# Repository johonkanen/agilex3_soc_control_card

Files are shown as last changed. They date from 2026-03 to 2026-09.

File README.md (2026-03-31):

# agilex3_soc_control_card
agilex 3 soc platform based control card for ac in/out lab power supply
Original board used Agilex 3 FPGA and had a few bugs in pin connections so this is second revision with SoC instead of just FPGA

target is to create a Linux capable Control Board with ethernet connection using A3CW100BM16AE6S SoC
Alternatively I could use Agilex 5 A5E(E/B)008B23BE6SCS

Main features :
Agilex 5 SoC (A5EB008B23BE6SCS)
1Gb ethernet
microSD
(1GB? 2GB? 4GB?) LPDDR4
muxed adc block

Controls power electronics so mostly does generic io for pwm and spi/sdm adc

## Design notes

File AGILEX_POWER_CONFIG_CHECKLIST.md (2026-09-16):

# Agilex 5 (A5EB013B-B23B, -6S) power, configuration and power-up checklist

Generated from the schematic as of 2026-09-16 (root sheet, `fpga_power`, `fpga_gnd`, `sdm`, `ps`, `ps1`, `clk`, `hps`). Reference: Altera *Agilex 5 Power Management User Guide* (ID 813161, section 3.2 Power-Up Sequence Requirements, table 3) and the *Agilex 5 Pin Connection Guidelines* (ID 813266).

Legend: `[x]` verified correct in the schematic, `[ ]` open item / needs your decision, `[!]` error to fix.

---

## 1. Supply rails on the board

| Rail (net) | Source | Nominal | Enable | Loads |
|---|---|---|---|---|
| `5V0` / `5V` | J6 (2x3 header), also J4.3 | 5.0 V in | – | all regulators, U6 |
| `VCORE` | U15 TDA38812XUMA1 buck, remote sense via `vcoresense_P/N` (VCCLSENSE BN46 / GNDSENSE BN44), FB divider R2 10k / R1 39k -> 0.6 V x (1 + 10/39) = **0.754 V** | 0.75 V | EN tied to 5V0 -> starts as soon as 5 V is present | all Group 1 pins (see §2) |
| `1V8` | U18 AP61202Z6 buck, R82 10k / (R80 ‖ R81 = 5k) -> 1.80 V | 1.8 V | EN = `PG-Core` (U15 PGOOD, open-drain, R58 5.6k to 5V0) | Group 2A pins, VCCIO_HVIO_6A, Y2 (SiT8924 1.8 V), QSPI flash U2, all SDM/JTAG pull-ups, U1/U42 B-side, PHY 1.8 V |
| `3V3` / `3v3` | U8 AP61202Z6, R85 10k / R83 2k2 -> 3.33 V | 3.3 V | EN = U18 PG (open-drain, R65 47k to 5V) | VCCIO_HVIO_6B..6H, U9 100 MHz LVDS osc, U1/U42 A-side, headers |
| `1V2` | U19 AP61202Z6, R88 10k / R86 10k -> 1.20 V | 1.2 V | EN = U18 PG | VCCRCORE, VCCIO_PIO_SDM, VCCIO_PIO_2A_T/B |
| `1V1` | U16 AP61202Z6, R91 10k / R89 12k -> 1.10 V | 1.1 V | EN = U18 PG | VCCIO_PIO_3A_T/B (LPDDR4), refclk bias divider |
| `3V3_analog` | U6 NCP163 LDO from 5V0 | 3.3 V intended | EN tied to 5V0 | ADC subsystem |

- [x] VCORE set point 0.754 V matches the -6S core voltage; remote sense goes to the device sense pins.
- [x] All AP61202 feedback dividers give the intended voltages (R84/R87/R90 are DNP).
- [x] U6 is `NCP163ASN330T1G` (3.3 V fixed) — was wrongly the 1.5 V `...150T1G` variant.
- [x] U19 / U8 / U16 `PG` pins (open drain) are wired-AND on `pg_all` with R249 10 k to 1V8 -> hierarchical `PG` -> root `pg_1v8` -> U42 channel 4 (1.8 V -> 3.3 V) -> `powergood` (SODIMM P1 pin 12, push-pull 3.3 V) and `pg_led` -> R16 -> D1. High only when 1V2, 3V3 and 1V1 are all in regulation (which implies VCORE and 1V8 are up).

## 2. Voltage per Agilex 5 supply pin group (from `fpga_power.kicad_sch`)

Rail groups are from table 3 of the Power Management UG. All pins of each group were checked; the count is the number of balls.

### Group 1 – core, must ramp first (all on `VCORE`, 0.75 V)

| Pin name | Balls | Net | |
|---|---|---|---|
| VCC | 21 | VCORE | [x] |
| VCCP | 7 | VCORE | [x] |
| VCCL_SDM | 4 | VCORE | [x] |
| VCCH_SDM | 1 (CD54) | VCORE | [x] (PCG: connect to VCCL_SDM when there are no transceivers) |
| VCC_IO_SDM | 1 (CT54) | VCORE | [x] sense pin, follows VCC |
| VCCL_ADC_SDM | 1 (CW52) | VCORE | [x] |
| VCCPLLDIG_SDM | 1 (CL49) | VCORE | [x] |
| VCCL_HPS | 4 | VCORE | [x] |
| VCCL_HPS_CORE0_CORE1 | 2 (AG46, AL46) | VCORE | [x] |
| VCCL_HPS_CORE2/3 | 4 (AL52, AL54, AR57, AW57) | VCORE | [x] (013B quad-core; on 008B these balls are GND) |
| VCCPLLDIG1_HPS / VCCPLLDIG2_HPS | 2 (BB54, BB52) | VCORE | [x] |
| VCC_HSSI_L | 2 (BJ54, BN54) | VCORE | [x] |
| VCCLSENSE / GNDSENSE | BN46 / BN44 | vcoresense_P / vcoresense_N | [x] Kelvin sense to U15 FB / RGND |

### Group 2A – 1.8 V, after Group 1 reaches 90 % (all on `1V8`)

| Pin name | Balls | Net | |
|---|---|---|---|
| VCCPT | 4 | 1V8 | [x] |
| VCCPT_HVIO | 10 | 1V8 | [x] |
| VCCIO_SDM | 1 (CW49) | 1V8 | [x] sets SDM I/O, JTAG, OSC_CLK_1 level = 1.8 V |
| VCCFUSEWR_SDM | 1 (CD52) | 1V8 | [x] |
| VCCPLL_SDM | 1 (CL46) | 1V8 | [x] |
| VCCADC | 1 (CG52) | 1V8 | [x] |
| VCCIO_HPS | 2 | 1V8 | [x] HPS I/O are 1.8 V only |
| VCCPLL1_HPS / VCCPLL2_HPS | 2 (BF57, BF52) | 1V8 | [x] |

### Group 2B – I/O, after Group 2A reaches 90 %

| Pin name | Balls | Net | |
|---|---|---|---|
| VCCRCORE | 3 | 1V2 | [x] 1.2 V |
| VCCIO_PIO_SDM | 1 (CW57) | 1V2 | [x] sense pin, follows VCCRCORE |
| VCCIO_PIO_2A_T / 2A_B | 4 | 1V2 | [x] |
| VCCIO_PIO_3A_T / 3A_B | 4 | 1V1 | [x] LPDDR4 (1.1 V) |
| VCCIO_HVIO_6B .. 6H | 14 | 3v3 | [x] 3.3 V LVCMOS banks |
| VCCIO_HVIO_6A | 2 (CL29, CT29) | **1V8** | [ ] see note below |

### Not sequenced

| Pin name | Ball | Net | |
|---|---|---|---|
| VCCBAT | CG49 | GND | [x] allowed when the BBRAM key is not used (UG 813161, 10/2025) |

**Note on VCCIO_HVIO_6A:** bank 6A was moved to 1.8 V so that the SDM 25 MHz clock can be fed to fabric PLL refclk pin CE19. VCCIO_HVIO is a Group 2B rail, but it now shares the 1V8 regulator with the Group 2A rails, so it reaches 90 % at the same moment as VCCPT instead of after it. This is the only deviation from the published group order. Options, in order of effort:
1. Accept it (Altera's sharing table – which could not be retrieved while writing this – is the authority; if it allows a 1.8 V VCCIO to share the VCCPT regulator, nothing is needed).
2. Feed bank 6A through a small load switch from 1V8, enable driven by U18 PG: e.g. a second TPS22918 (already in the BOM for the SD card) – its soft start gives a clean, later ramp.
3. Move bank 6A back to 3.3 V and use another refclk pin (DP55 in bank 2A at 1.2 V, or BF23 / AE11 in 3.3 V banks).

## 3. Power-up order implemented by the enable chain

```
5V0 applied
  |-- U6  3V3_analog LDO        (EN = VIN, immediately)
  |-- U15 VCORE 0.75 V          (EN = VIN, immediately)            ... Group 1
        PGOOD (open drain, 5.6k to 5 V) ->
        U18 1V8                                                    ... Group 2A (+ VCCIO_HVIO_6A)
              PG (open drain, 47k to 5 V) ->
              U19 1V2  (VCCRCORE, VCCIO_PIO_SDM, 2A)   \
              U8  3V3  (HVIO 6B-6H)                     |  in parallel ... Group 2B
              U16 1V1  (3A / LPDDR4)                   /
```

- [x] Order is Group 1 -> 2A -> 2B as required (VCCIO_HVIO_6A excepted, see §2).
- [x] Each stage is gated by a PGOOD, so the "90 % before the next group starts" rule is met by construction (TDA38812 and AP61202 PG assert at roughly 90–95 % of nominal).
- [x] All rails ramp monotonically (soft-start bucks, no pre-bias issues: every rail starts from 0 V because the previous rail's PG gates the next).
- [x] POR-monitored rails (VCCL_SDM, VCCPT, VCCIO_SDM, VCCADC, VCC, VCCL_HPS, VCCIO_PIO_SDM, VCCRCORE, VCC_IO_SDM) are all present and in the right groups.
- [x] The QSPI flash (1V8) and the 25 MHz oscillator Y2 (1V8) are up before the last Group 2B rail, so they are ready when the POR delay expires (AS fast mode, see §4).
- [ ] The 10 ms total tRAMP limit only applies to CvP; not relevant here, but the total time from 5 V to the last PG is a few ms per stage – fine.
- [ ] Power-down: the UG only *recommends* the reverse order. Nothing on the board enforces it (all rails just decay when 5 V is removed). Acceptable for a lab board; if you want it, add a discharge/sequencer later.
- [ ] While 1V8 is up and 3V3 is not yet up, U1/U42 (SN74AXC4T774) see VCCB = 1.8 V and VCCA = 0 V – the AXC family is designed for this (Ioff, partial-power-down), no issue. The KSZ9031 PHY and the SD card mux likewise have their own supplies sequenced from 1V8/3V3 only.
- [ ] Reminder: during power-up no input pin may be driven above its bank's VCCIO. The 3.3 V UART header J10 and the JTAG header J1 are behind level shifters that are powered by the same rails, so this holds.

## 4. SDM / configuration pins (from `sdm.kicad_sch`)

| Pin | Ball | Schematic | Requirement | |
|---|---|---|---|---|
| nCONFIG | BK71 | `~{nconfig}`, R8 10k to 1V8, nothing else | 10 k pull-up to VCCIO_SDM; drive low to reconfigure | [x] (no push-button / test point – add one if you want to force reconfiguration from the bench) |
| nSTATUS | BM71 | `~{nstatus}`, R11 10k to 1V8 | 10 k pull-up, open-drain output | [x] |
| CONF_DONE | SDM_IO16 DA74 | `conf_done`, R10 10k to 1V8 (no LED; D1 is the power-good LED) | 10 k pull-up; assign SDM_IO16 = CONF_DONE in Quartus | [x] |
| INIT_DONE | SDM_IO0 BK67 | `init_done`, R9 10k to 1V8 | 10 k pull-up; assign SDM_IO0 = INIT_DONE in Quartus | [x] |
| MSEL0 | SDM_IO5 BY71 | R7 4k7 to 1V8 (shared with AS_nCSO0 / flash CS#) | 4.7 k pull | [x] = 1 |
| MSEL1 | SDM_IO7 CN67 | R45 4k7 to GND | 4.7 k pull | [x] = 0 |
| MSEL2 | SDM_IO9 CN71 | R4 4k7 to GND | 4.7 k pull | [x] = 0 |
| MSEL[2:0] | | **001 = Active Serial, fast mode** (011 would be AS normal mode, 111 JTAG only) | matches AS x4 flash on SDM_IO1..IO6 | [x] verify the value once against the Configuration UG (ID 813773) table – the docs site was down while this list was written |
| AS_CLK | SDM_IO2 CY69 | `qspi_CLK` -> U2 SCLK | | [x] |
| AS_DATA0..3 | SDM_IO4 / IO1 / IO3 / IO6 | `qspi_D0..D3` -> U2 SIO0..3; D2, D3 have 10 k pull-ups (R12, R14) | | [x] |
| AS_nCSO0 | SDM_IO5 | `~{qspi_CS}` -> U2 CS#, 4k7 pull-up | | [x] |
| AS_nRST | SDM_IO15 CY71 | `~{qspi_rst_n}` -> U2 RESET#, R15 10 k pull-up | | [x] |
| AS_nCSO3 | SDM_IO8 DB71 | NC | unused, internal weak pull-up | [x] |
| SDM_IO10 | CK69 | `~{hps_cold_rstn}` from the connectors sheet | HPS_COLD_nRESET must be assigned to this SDM_IO in Quartus; SDM_IO pins have internal weak pull-ups, so no external pull-up is required | [ ] check the assignment; check the driver on the connector side is open-drain/1.8 V |
| SDM_IO11, IO12, IO14 | DG71, BK69, BY69 | NC | unused | [x] |
| SDM_IO13 | DA75 | NC | unused | [x] |
| OSC_CLK_1 | DB72 | net `sdm_clk25` = 25 MHz from Y2 (SiT8924, 1.8 V) via R246 33 R | 25 / 100 / 125 MHz, 1.8 V CMOS, mandatory with EMIF | [x] |
| RREF | DH75 | R18 2k0 to GND | 2 kΩ ±1 % | [x] |
| VREFP_ADC, VREFN_ADC, VSIGP/N_0, VSIGP/N_1 | CF75, CF74, BW75, BW74, CJ74, CJ75 | GND | GND when the ADC is unused | [x] |
| TEMPDIODE0Ap / An | CK71, CN72 | NC | leave unconnected (external remote-diode temperature sensor input, unused) | [x] |
| JTAG TCK | CC64 | R22 1k0 to GND | 1 k pull-down | [x] |
| JTAG TMS, TDI | CY67, CC67 | R21, R19 10 k to 1V8 | 10 k pull-up | [x] |
| JTAG TDO | BY67 | R20 10 k to 1V8 | optional | [x] |
| JTAG header | J1 via U1 SN74AXC4T774 (1.8 V <-> 3.3 V) | | | [x] |
| VCCBAT | CG49 | GND | | [x] |
| QSPI flash | U2 MX25U25645G, VCC = 1V8 | 1.8 V flash required (SDM I/O are 1.8 V) | | [x] |

## 5. Quartus / firmware settings implied by the schematic

- [ ] Configuration scheme: AS x4, fast mode; flash MX25U25645G (256 Mbit).
- [ ] SDM I/O assignments: SDM_IO0 = INIT_DONE, SDM_IO16 = CONF_DONE, SDM_IO10 = HPS_COLD_nRESET, SDM_IO15 = AS_nRST (device-wide flash reset), others unused.
- [ ] OSC_CLK_1 frequency = 25 MHz.
- [ ] Bank 6A VCCIO = 1.8 V, CE19 = `sdm_clk25` 1.8 V LVCMOS refclk; banks 6B–6H = 3.3 V; 2A = 1.2 V; 3A = 1.1 V (LPDDR4); HPS = 1.8 V.
- [ ] HPS clock: `hps_osc_clk25` on GPIO1_IO3 (AN67), 25 MHz.
- [ ] HPS GPIO1_IO14/IO15 = UART0 TX/RX (level-shifted by U42 to J10), GPIO1_IO18 = PHY reset.
- [ ] User LED D2 on CE6 (bank 6B, 3.3 V, ~2 mA source); D1 = power good (hardware, no assignment needed).

## 6. Summary of actions

1. `[x]` U6 value changed to `NCP163ASN330T1G` (3.3 V).
2. `[x]` NC flags added on SDM_TEMPDIODE0Ap / An (CK71, CN72).
3. `[ ]` Decide how to handle VCCIO_HVIO_6A on the shared 1V8 (§2 note).
4. `[x]` AP61202 PG pins wired-AND -> `powergood` (3.3 V via U42) + LED D1.
5. `[x]` `load_factory_image` label removed (SDM_IO13 NC); net renamed `sdm_clk25`.
6. `[ ]` Confirm HPS_COLD_nRESET on SDM_IO10 and the MSEL = 001 (AS fast) entry against the Configuration UG.
7. `[ ]` Optional: nCONFIG push-button / test point.

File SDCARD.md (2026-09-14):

# microSD interface

Documents the microSD card interface: what is currently built, what is
missing, and what would be required to run UHS-I speeds.

## Why a level translator is needed

The Agilex 5 HPS SD/MMC I/O only supports 1.8 V signalling. An SD card must
be powered and must communicate at 3.3 V signalling at insertion, regardless
of what speed mode it later negotiates. A translator between the two domains
is therefore mandatory, not optional.

## As built

| Part | Function |
|---|---|
| U11  | Nexperia NXS0506GUX, SD 3.0 level translator, XQFN16 (SOT1161-1) |
| J8 | microSD socket, Wuerth 693072010801 |
| U40  | TI TPS2116DRLR, 2:1 supply mux, `3V3` / `1V8` -> `VDD_SD_IO` (U11 VCCB) |
| U41  | TI TPS22918DBVR, load switch, `3V3` -> `VDD_SD_CARD` (J8 pin 4) |
| R241 | 100k, `sd_vsel` pull-up to `1V8` (default: 3.3 V signalling) |
| R242 | 100k, U40 MODE pull-up to `1V8` (manual mode) |
| R243 | 100k, `sd_pwr_en` pull-up to `1V8` (default: card powered) |
| C240, C241 | 1u at U40 VIN1 / VIN2 |
| C242, C243 | 4u7 + 100n on `VDD_SD_IO` at U11 pin 14 |
| C244, C245 | 4u7 + 100n on `1V8` at U11 pin 15 |
| C246 | 10u at U41 VIN |
| C247, C248 | 10u + 100n on `VDD_SD_CARD` at J8 pin 4 |

The decoupling capacitors are drawn as a row on the schematic; on the PCB
they belong at the pins named above.

Signal path, verified pin by pin:

| Function | HPS (U7) | U11 host side | U11 card side | J8 |
|---|---|---|---|-----|
| CLK  | AC74 | 5  CLKA  | 8  CLKB  | 5 |
| CMD  | AK69 | 16 CMDA  | 13 CMDB  | 3 |
| DAT0 | AF75 | 3  DAT0A | 10 DAT0B | 7 |
| DAT1 | AC75 | 4  DAT1A | 9  DAT1B | 8 |
| DAT2 | AN64 | 1  DAT2A | 12 DAT2B | 1 |
| DAT3 | Y74  | 2  DAT3A | 11 DAT3B | 2 |

Supplies:

| Net | Feeds |
|-----|---|
| `1V8` | U11 pin 15 (VCCA), host side; U40 VIN2 |
| `3V3` | U40 VIN1, U41 VIN |
| `VDD_SD_IO` | U11 pin 14 (VCCB), card-side signalling rail, 3.3 V or 1.8 V |
| `VDD_SD_CARD` | J8 pin 4 (card VDD), switched 3.3 V |
| `GND` | U11 pin 7, J8 pin 6 and shield, U40, U41, decoupling |

Control, both on HPS GPIO1 (IOB, 1.8 V bank):

| Signal | HPS pin | Drives | Idle (HPS in reset) |
|---|---|---|---|
| `sd_vsel` | F75, GPIO1_IO16 | U40 PR1: high = 3.3 V, low = 1.8 V | pulled high, 3.3 V |
| `sd_pwr_en` | AD71, GPIO1_IO17 | U41 ON: high = card powered | pulled high, on |

U40 ST (open-drain status) and U41 CT (slew) are left unconnected; U41 QOD
is tied to VOUT so the internal ~25 ohm discharge empties the card rail
when `sd_pwr_en` goes low.

Pin 6 (CLKFB) is tied to `sd_clk` together with CLKA, as the datasheet
recommends for higher clock rates.

No external pull-ups are fitted, and none are needed: the NXS0506GU has
integrated 70 kOhm (42-100 kOhm) pull-ups to VCCA on every host-side pin
except CLKA.

## Open items before fabrication

- [x] Decoupling on U11 (C242-C245) and at J8 (C247, C248) is in the
      schematic. Place them at the pins when the area is rerouted.
- [ ] **Update PCB from schematic.** U40, U41, R241-R243 and C240-C248
      exist only in the schematic until Tools -> Update PCB from Schematic
      is run, then need placing near U11 / J8.
- [ ] **No card detect.** J8's pin 2 is DAT3/CD and passes through the
      translator as an ordinary data line. This connector variant has no
      detect switch contact. Either detect in software from DAT3, or change
      to a connector variant with the switch.
- [ ] **SD traces need rerouting.** U11 was changed from a TXS0206A
      (DSBGA-20) to the NXS0506GUX (XQFN16). The footprint is much smaller,
      so the existing traces no longer reach the pads. They were left in
      place deliberately rather than deleted.

## UHS-I support

Without the rail switching below, the card-side signalling rail would sit at
a fixed 3.3 V and the interface would be limited to default speed and high
speed, roughly 50 MHz. UHS-I modes (SDR50, DDR50, SDR104) require the bus
to switch to 1.8 V signalling after the card accepts the request. The
NXS0506GU itself supports UHS-I; Nexperia AN90037 covers this use of the
part. The circuit described in this section is what is now drawn in
`hps.kicad_sch`.

### Sequence

1. Host sets S18R in ACMD41; card responds S18A.
2. Host issues CMD11.
3. Card drives CMD and DAT[3:0] low.
4. Host stops SDCLK, switches the signalling rail 3.3 V -> 1.8 V.
5. After at least 5 ms, host restarts the clock at 1.8 V.
6. Card releases the lines within 1 ms. If it does not, the host must
   power-cycle the card and fall back to 3.3 V.

Only the signalling rail changes. Card VDD stays at 3.3 V throughout.

### Rails

The two former uses of `3V3` are split:

| Net | Feeds | Behaviour |
|-----|---|---|
| `3V3` (via load switch) | J8 pin 4, card VDD | fixed 3.3 V, gateable on/off |
| `VDD_SD_IO` (new) | U11 pin 14, VCCB only | switched 3.3 V / 1.8 V |
| `1V8` | U11 pin 15, VCCA | unchanged |

Both `3V3` and `1V8` already exist on the board, so no additional regulator
is needed. The signalling rail can be a 2:1 supply mux between them.

Two control signals are used, on the first two of the six free HPS GPIOs
(all on IOB / GPIO1, the same 1.8 V bank as the SD signals; IO18 (K71),
IO19 (AK71), IO20 (F74) and IO21 (AA71) remain free).

| Signal | HPS pin | Controls | Linux binding |
|---|---|---|---|
| `sd_vsel` | GPIO1_IO16, F75 | `VDD_SD_IO` 3.3 V / 1.8 V | `vqmmc-supply` (gpio-regulator) |
| `sd_pwr_en` | GPIO1_IO17, AD71 | J8 pin 4 on/off | `vmmc-supply` (regulator-fixed with enable GPIO) |

Card power gating is not optional. It is the specification's mandated
recovery path when a card fails to release the bus after CMD11, and it
appears in the NXP reference circuit (AN13031, figure 1).

### Parts

| Ref | Part | Function | Package | KiCad footprint |
|-----|---|---|---|---|
| U40 | TI TPS2116DRLR | 2:1 mux, `3V3` / `1V8` -> `VDD_SD_IO` | SOT-583 | `Package_TO_SOT_SMD:SOT-583-8` |
| U41 | TI TPS22918 | load switch on card VDD | SOT-23-6 | `Package_TO_SOT_SMD:SOT-23-6` |

Symbols `TPS2116DRL` and `TPS22918DBV` are in `agilex_5_lib`. Pin numbers
were taken from the TI pin-function tables (TPS2116: 1 GND, 2/7 VOUT,
3 VIN1, 4 PR1, 5 MODE, 6 VIN2, 8 ST; TPS22918: 1 VIN, 2 GND, 3 ON, 4 CT,
5 QOD, 6 VOUT).

**TPS2116.** Input range 1.6-5.5 V, covering both rails. MODE is pulled
to `1V8` (R242) for manual mode; it must not be tied to VIN1, which selects
priority mode instead. PR1 then selects the input, high = VIN1, low = VIN2.
PR1 switches around VREF (0.92-1.08 V), so an 1.8 V GPIO has ample margin.
Reverse current blocking (when VOUT > VINx, 2 us) and break-before-make are
both internal, which satisfies the first two constraints below with no
external parts.

**TPS22918.** 1-5.5 V, 2 A, ON threshold 1 V minimum and specified for use
with 1 V or higher GPIOs. Quick output discharge is roughly 25 ohm at 3.3 V.
The discharge matters: for a power-cycle recovery to reset the card, its VDD
has to reach near zero rather than float on its own decoupling.

Availability as of September 2026: TPS2116DRLR, 66k at DigiKey and 2.4k at
Mouser, around $0.50. TPS22918 is stocked as TPS22918TDBVTQ1, the Q1
automotive grade, around 5.9k at DigiKey; the plain TPS22918DBVT was not
stocked.

Confirm before ordering:

- The stocked load switch is the `T` variant (TPS22918TDBVTQ1). Check its
  rise time and QOD behaviour against the base TPS22918 datasheet cited here.
- KiCad's `SOT-583-8` footprint carries a description referencing the
  TPS62933, not the TPS2116. It is the same JEDEC package and the land
  pattern measures 2.15 x 1.80 mm at 0.5 mm pitch, but cross-check it
  against TI's TPS2116 land pattern before fabrication.

### Design notes

- **Reverse blocking on the 1.8 V leg.** A plain P-FET or a load switch
  without reverse blocking will conduct through its body diode from the
  output back into `1V8` whenever the rail sits at 3.3 V. Use back-to-back
  FETs or a switch that blocks reverse current. The 3.3 V leg is inherently
  safe because 3.3 V > 1.8 V keeps its body diode reverse biased.
- **Break before make.** `3V3` and `1V8` must never be connected together.
  Handled internally by the TPS2116; only relevant if built from discretes.
- **Default state at reset.** HPS GPIOs are high impedance during reset, so
  both control lines are pulled (R241, R243) to the safe state: card
  powered, 3.3 V signalling. The translator also requires VCCB >= VCCA,
  which an undefined VCCB would violate while VCCA is at 1.8 V. The
  TPS22918 ON pin has no internal pull and must not float.
- **Falling transition.** Switching to the 1.8 V rail discharges the VCCB
  capacitance into `1V8` through the closed switch, roughly 7 uC for 4.7 uF,
  which is negligible against the board's 1.8 V bulk. Note that an LDO with
  a switched feedback divider would *not* behave this way: its output would
  float down at the load current, needing around 1.4 mA of bleed to meet the
  5 ms window. This is a reason to prefer the mux.
- **Signal integrity.** SDR104 clocks at 208 MHz, four times the present
  rate. Length matching, controlled impedance, short stubs and minimal added
  capacitance all become relevant. Worth routing for this when the traces are
  redone.
- **Silicon revision.** Agilex 5 engineering samples are documented as
  failing to boot from SD in SDR104 (and eMMC in HS200/HS400). Production
  devices are unaffected. Confirm the stepping before relying on it.

### Alternative part

NXP NVT4857UK integrates the switchable LDO and a card detect pin, removing
the external mux. It is WLCSP20, 0.4 mm pitch, 1.7 x 2.1 mm.

## eMMC as an alternative

eMMC has a separate I/O supply (VCCQ) that can run at 1.7-1.95 V while the
NAND core (VCC) runs at 3.3 V, so it connects directly to the 1.8 V HPS pins
with no translator, no card detect problem and no voltage switching. The
Agilex 5 HPS SD/MMC controller supports eMMC, and its HS200/HS400 modes
require 1.8 V signalling in any case.

`sd_d4` through `sd_d7` are already named and brought out to U7 (U74, AK67,
P75, P74) but connect to nothing else, so the 8-bit bus an eMMC would need
is partly prepared.

Sourcing is the obstacle. As of September 2026, 8 GB eMMC in single-digit
quantities was not stocked at DigiKey, Mouser or LCSC across parts from
Kingston, Micron, KIOXIA, Swissbit, FORESEE and MK; the low densities are
being discontinued. Franchise distributors (Arrow, Avnet, Future) quote
small quantities against stock that does not appear in the catalogues.

## References

- Nexperia NXS0506 datasheet — https://assets.nexperia.com/documents/data-sheet/NXS0506.pdf
- Nexperia AN90037, NXS0506 SD-card voltage level translator — https://assets.nexperia.com/documents/application-note/AN90037.pdf
- Nexperia SOT1161-1 package / land pattern — https://www.nxp.com/docs/en/package-information/SOT1161-1.pdf
- NXP AN13031, Recommendations for SD Connections to 1.8 V SDHC Interfaces — https://www.nxp.com/docs/en/application-note/AN13031.pdf
- NXP NVT4857UK datasheet — https://www.nxp.com/docs/en/data-sheet/NVT4857UK.pdf
- Altera SD/eMMC controller documentation — https://altera-fpga.github.io/rel-26.1/linux-embedded/drivers/sd-emmc/sd-emmc/

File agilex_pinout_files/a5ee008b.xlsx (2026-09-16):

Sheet: IO Resource Count
Pin Information for Agilex™ 5 A5EE008B Device
TYPE | BANK | B23B Package
HSIO | 2A_B | 48
HSIO | 2A_T | 48
HPS shared HSIO | 3A_B | 48
HPS and SDM shared HSIO | 3A_T | 48
HVIO | 6A | 20
HVIO | 6B | 20
HVIO | 6C | 20
HVIO | 6D | 19
HVIO | 6E | 20
HVIO | 6F | 20
HVIO | 6G | 20
HVIO | 6H | 20
HPS I/O | HPS | 48
SDM I/O | SDM | 33
i. Total LVDS channels per bank supporting SERDES Non-DPA and DPA mode is equivalent to (LVDS I/O per bank)/2, inclusive of clock pair. Please refer to Dedicated Tx/Rx Channel column in the pin-out table for the channel availability.
ii. Total LVDS channels supporting SERDES Soft-CDR mode is 12 pairs per bank. Please refer to Soft CDR column in the pin out table for the channel availability.

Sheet: Pin List B23B
Pin Information for Agilex™ 5 A5EE008B Device Version: 2025-06-13 B23B Status: Final
Bank Number | Index within I/O Bank | Pin Name/Function | Optional Function(s) | Configuration Function | HPS Function | Dedicated Tx/Rx Channel SERDES | Soft CDR Support | B23B | DQS for X4 | DQS for X8/X9 | DQS for X16/X18
SDM |  | TDO |  |  |  |  |  | BY67
SDM |  | TMS |  |  |  |  |  | CY67
SDM |  | TCK |  |  |  |  |  | CC64
SDM |  | TDI |  |  |  |  |  | CC67
SDM |  | OSC_CLK_1 |  |  |  |  |  | DB72
SDM |  | SDM_IO1 | AVSTx8_DATA2,AS_DATA1 |  |  |  |  | CK67
SDM |  | SDM_IO5 | AS_nCSO0,MSEL0 |  |  |  |  | BY71
SDM |  | SDM_IO3 | AVSTx8_DATA3,AS_DATA2 |  |  |  |  | DC74
SDM |  | nCONFIG |  |  |  |  |  | BK71
SDM |  | SDM_IO4 | AVSTx8_DATA1,AS_DATA0 |  |  |  |  | CN64
SDM |  | SDM_IO2 | AVSTx8_DATA0,AS_CLK |  |  |  |  | CY69
SDM |  | SDM_IO7 | AS_nCSO2,MSEL1 |  |  |  |  | CN67
SDM |  | SDM_IO11 | AVSTx8_VALID,PWRMGT_SDA |  |  |  |  | DG71
SDM |  | nSTATUS |  |  |  |  |  | BM71
SDM |  | SDM_IO16 | PWRMGT_SDA |  |  |  |  | DA74
SDM |  | SDM_IO0 | PWRMGT_SCL,PWRMGT_ALERT |  |  |  |  | BK67
SDM |  | SDM_IO13 | AVSTx8_DATA5 |  |  |  |  | DA75
SDM |  | SDM_IO9 | AS_nCSO1,MSEL2,PWRMGT_ALERT |  |  |  |  | CN71
SDM |  | SDM_IO6 | AVSTx8_DATA4,AS_DATA3 |  |  |  |  | DC75
SDM |  | SDM_IO10 | AVSTx8_DATA7 |  |  |  |  | CK69
SDM |  | SDM_IO8 | AVSTx8_READY,AS_nCSO3 |  |  |  |  | DB71
SDM |  | SDM_IO12 | PWRMGT_SDA,PWRMGT_ALERT |  |  |  |  | BK69
SDM |  | SDM_IO15 | AVSTx8_DATA6,AS_nRST |  |  |  |  | CY71
SDM |  | SDM_IO14 | AVSTx8_CLK,PWRMGT_SCL |  |  |  |  | BY69
SDM |  | RREF_SDM |  |  |  |  |  | DH75
SDM |  |  | TEMPDIODE0An |  |  |  |  | CN72
SDM |  |  | TEMPDIODE0Ap |  |  |  |  | CK71
SDM |  |  | VREFP_ADC |  |  |  |  | CF75
SDM |  |  | VREFN_ADC |  |  |  |  | CF74
SDM |  | VSIGP_0 |  |  |  |  |  | BW75
SDM |  | VSIGN_0 |  |  |  |  |  | BW74
SDM |  | VSIGP_1 |  |  |  |  |  | CJ74
SDM |  | VSIGN_1 |  |  |  |  |  | CJ75
HPS |  | HPS_IOA_1 | GPIO0_IO0,SPIM0_SS1_N,SPIS0_CLK,UART0_CTS_N,NAND_ADQ0,SDMMC_DATA0,USB0_CLK,EMAC0_PPS0,TRACE_D10 |  | HPS_IOA_1 |  |  | BC64
HPS |  | HPS_IOA_2 | GPIO0_IO1,SPIM1_SS1_N,SPIS0_MOSI,UART0_RTS_N,NAND_ADQ1,SDMMC_DATA1,USB0_STP,EMAC0_PPSTRIG0,TRACE_D9 |  | HPS_IOA_2 |  |  | BC67
HPS |  | HPS_IOA_3 | GPIO0_IO2,SPIS0_SS0_N,UART0_TX,I2C1_SDA,NAND_WE_N,SDMMC_CLK,USB0_DIR,EMAC1_PPS1,TRACE_D8 |  | HPS_IOA_3 |  |  | AY67
HPS |  | HPS_IOA_4 | GPIO0_IO3,SPIS0_MISO,UART0_RX,I2C1_SCL,NAND_RE_N,USB0_DATA0,EMAC1_PPSTRIG1,TRACE_D7 |  | HPS_IOA_4 |  |  | AN72
HPS |  | HPS_IOA_5 | GPIO0_IO4,SPIM0_CLK,UART1_CTS_N,I2C0_SDA,NAND_WP_N,SDMMC_WRITE_PROTECT,USB0_DATA1,EMAC2_PPS2,TRACE_D6 |  | HPS_IOA_5 |  |  | AY69
HPS |  | HPS_IOA_6 | GPIO0_IO5,SPIM0_MOSI,UART1_RTS_N,I2C0_SCL,NAND_ADQ2,SDMMC_DATA2,USB0_NXT,EMAC2_PPSTRIG2,TRACE_D5 |  | HPS_IOA_6 |  |  | BA75
HPS |  | HPS_IOA_7 | GPIO0_IO6,SPIM0_MISO,MDIO2_MDIO,UART1_TX,I2C_EMAC2_SDA,NAND_ADQ3,SDMMC_DATA3,USB0_DATA2,TRACE_D4 |  | HPS_IOA_7 |  |  | BC71
HPS |  | HPS_IOA_8 | GPIO0_IO7,SPIM0_SS0_N,MDIO2_MDC,UART1_RX,I2C_EMAC2_SCL,NAND_CLE,SDMMC_CMD,USB0_DATA3,TRACE_D15 |  | HPS_IOA_8 |  |  | AU74
HPS |  | HPS_IOA_9 | GPIO0_IO8,SPIM1_CLK,SPIS1_CLK,MDIO1_MDIO,I2C_EMAC1_SDA,NAND_ADQ4,SDMMC_DATA4,USB0_DATA4,I3C1_SDA,TRACE_D14 |  | HPS_IOA_9 |  |  | AY71
HPS |  | HPS_IOA_10 | GPIO0_IO9,SPIM1_MOSI,SPIS1_MOSI,MDIO1_MDC,I2C_EMAC1_SCL,NAND_ADQ5,SDMMC_DATA5,USB0_DATA5,I3C1_SCL,TRACE_D13 |  | HPS_IOA_10 |  |  | AU75
HPS |  | HPS_IOA_11 | GPIO0_IO10,SPIM1_MISO,SPIS1_SS0_N,MDIO0_MDIO,I2C_EMAC0_SDA,NAND_ADQ6,SDMMC_DATA6,USB0_DATA6,I3C0_SDA,TRACE_D12 |  | HPS_IOA_11 |  |  | BC72
HPS |  | HPS_IOA_12 | GPIO0_IO11,SPIM1_SS0_N,SPIS1_MISO,MDIO0_MDC,I2C_EMAC0_SCL,NAND_ADQ7,SDMMC_DATA7,USB0_DATA7,I3C0_SCL,TRACE_D11 |  | HPS_IOA_12 |  |  | BP74
HPS |  | HPS_IOA_13 | GPIO0_IO12,NAND_ALE,SDMMC_PU_PD_DATA2,USB1_CLK,EMAC0_TX_CLK,TRACE_D10 |  | HPS_IOA_13 |  |  | BP75
HPS |  | HPS_IOA_14 | GPIO0_IO13,NAND_RB_N,SDMMC_PWR_ENA,USB1_STP,EMAC0_TX_CTL,TRACE_D9 |  | HPS_IOA_14 |  |  | BL74
HPS |  | HPS_IOA_15 | GPIO0_IO14,NAND_CE_N,USB1_DIR,EMAC0_RX_CLK,TRACE_D8 |  | HPS_IOA_15 |  |  | BL75
HPS |  | HPS_IOA_16 | GPIO0_IO15,NAND_DQS,SDMMC_DATA_STROBE,USB1_DATA0,EMAC0_RX_CTL,TRACE_D7 |  | HPS_IOA_16 |  |  | AP74
HPS |  | HPS_IOA_17 | GPIO0_IO16,I3C1_SDA,NAND_ADQ8,USB1_DATA1,EMAC0_TXD0,TRACE_D6 |  | HPS_IOA_17 |  |  | BG74
HPS |  | HPS_IOA_18 | GPIO0_IO17,I3C1_SCL,NAND_ADQ9,USB1_NXT,EMAC0_TXD1,TRACE_D5 |  | HPS_IOA_18 |  |  | AP75
HPS |  | HPS_IOA_19 | GPIO0_IO18,I3C0_SDA,NAND_ADQ10,USB1_DATA2,EMAC0_RXD0,TRACE_D4 |  | HPS_IOA_19 |  |  | BD74
HPS |  | HPS_IOA_20 | GPIO0_IO19,SPIM1_SS1_N,I3C0_SCL,NAND_ADQ11,USB1_DATA3,EMAC0_RXD1,TRACE_CLK |  | HPS_IOA_20 |  |  | AN71
HPS |  | HPS_IOA_21 | GPIO0_IO20,SPIM1_CLK,SPIS0_CLK,UART0_CTS_N,I2C1_SDA,NAND_ADQ12,USB1_DATA4,EMAC0_TXD2,TRACE_D0 |  | HPS_IOA_21 |  |  | BD75
HPS |  | HPS_IOA_22 | GPIO0_IO21,SPIM1_MOSI,SPIS0_MOSI,UART0_RTS_N,I2C1_SCL,NAND_ADQ13,USB1_DATA5,EMAC0_TXD3,TRACE_D1 |  | HPS_IOA_22 |  |  | AM74
HPS |  | HPS_IOA_23 | GPIO0_IO22,SPIM1_MISO,SPIS0_SS0_N,UART0_TX,I2C0_SDA,NAND_ADQ14,USB1_DATA6,EMAC0_RXD2,TRACE_D2 |  | HPS_IOA_23 |  |  | AJ74
HPS |  | HPS_IOA_24 | GPIO0_IO23,SPIM1_SS0_N,SPIS0_MISO,UART0_RX,I2C0_SCL,NAND_ADQ15,USB1_DATA7,EMAC0_RXD3,TRACE_D3 |  | HPS_IOA_24 |  |  | AJ75
HPS |  | HPS_IOB_1 | GPIO1_IO0,SPIM1_CLK,UART0_CTS_N,EMAC0_PPS0,NAND_ADQ0,SDMMC_DATA0,I3C0_SDA_PULLUP_EN,EMAC1_TX_CLK,TRACE_D10 |  | HPS_IOB_1 |  |  | AF75
HPS |  | HPS_IOB_2 | GPIO1_IO1,SPIM1_MOSI,UART0_RTS_N,EMAC0_PPSTRIG0,NAND_ADQ1,SDMMC_DATA1,I3C1_SDA_PULLUP_EN,EMAC1_TX_CTL,TRACE_D9 |  | HPS_IOB_2 |  |  | AC75
HPS |  | HPS_IOB_3 | GPIO1_IO2,SPIM1_MISO,UART0_TX,I2C0_SDA,NAND_WE_N,SDMMC_CLK,EMAC1_RX_CLK,TRACE_D8 |  | HPS_IOB_3 |  |  | AC74
HPS |  | HPS_IOB_4 | GPIO1_IO3,SPIM1_SS0_N,UART0_RX,I2C0_SCL,NAND_RE_N,EMAC1_RX_CTL,TRACE_D7 |  | HPS_IOB_4 |  |  | AN67
HPS |  | HPS_IOB_5 | GPIO1_IO4,SPIM1_SS1_N,SPIS1_CLK,UART1_CTS_N,EMAC2_PPS2,NAND_WP_N,SDMMC_WRITE_PROTECT,I3C1_SDA,EMAC1_TXD0,TRACE_D6 |  | HPS_IOB_5 |  |  | Y75
HPS |  | HPS_IOB_6 | GPIO1_IO5,SPIS1_MOSI,UART1_RTS_N,EMAC2_PPSTRIG2,NAND_ADQ2,SDMMC_DATA2,I3C1_SCL,EMAC1_TXD1,TRACE_D5 |  | HPS_IOB_6 |  |  | AN64
HPS |  | HPS_IOB_7 | GPIO1_IO6,SPIS1_SS0_N,UART1_TX,I2C1_SDA,NAND_ADQ3,SDMMC_DATA3,I3C0_SDA,EMAC1_RXD0,TRACE_D4 |  | HPS_IOB_7 |  |  | Y74
HPS |  | HPS_IOB_8 | GPIO1_IO7,SPIS1_MISO,UART1_RX,I2C1_SCL,NAND_CLE,SDMMC_CMD,I3C0_SCL,EMAC1_RXD1,TRACE_D15 |  | HPS_IOB_8 |  |  | AK69
HPS |  | HPS_IOB_9 | GPIO1_IO8,JTAG_TCK,SPIS0_CLK,MDIO2_MDIO,I2C_EMAC2_SDA,NAND_ADQ4,SDMMC_DATA4,EMAC1_TXD2,TRACE_D14 |  | HPS_IOB_9 |  |  | U74
HPS |  | HPS_IOB_10 | GPIO1_IO9,JTAG_TMS,SPIS0_MOSI,MDIO2_MDC,I2C_EMAC2_SCL,NAND_ADQ5,SDMMC_DATA5,EMAC1_TXD3,TRACE_D13 |  | HPS_IOB_10 |  |  | AK67
HPS |  | HPS_IOB_11 | GPIO1_IO10,JTAG_TDO,SPIS0_SS0_N,MDIO0_MDIO,I2C_EMAC0_SDA,NAND_ADQ6,SDMMC_DATA6,EMAC1_RXD2,TRACE_D12 |  | HPS_IOB_11 |  |  | P75
HPS |  | HPS_IOB_12 | GPIO1_IO11,JTAG_TDI,SPIS0_MISO,MDIO0_MDC,I2C_EMAC0_SCL,NAND_ADQ7,SDMMC_DATA7,EMAC1_RXD3,TRACE_D11 |  | HPS_IOB_12 |  |  | P74
HPS |  | HPS_IOB_13 | GPIO1_IO12,I2C1_SDA,NAND_ALE,SDMMC_PU_PD_DATA2,EMAC2_TX_CLK,TRACE_D10 |  | HPS_IOB_13 |  |  | L75
HPS |  | HPS_IOB_14 | GPIO1_IO13,I2C1_SCL,NAND_RB_N,SDMMC_PWR_ENA,EMAC2_TX_CTL,TRACE_D9 |  | HPS_IOB_14 |  |  | N72
HPS |  | HPS_IOB_15 | GPIO1_IO14,UART1_TX,NAND_CE_N,I3C1_SDA,EMAC2_RX_CLK,TRACE_D8 |  | HPS_IOB_15 |  |  | N71
HPS |  | HPS_IOB_16 | GPIO1_IO15,UART1_RX,NAND_DQS,SDMMC_DATA_STROBE,I3C1_SCL,EMAC2_RX_CTL,TRACE_D7 |  | HPS_IOB_16 |  |  | AD72
HPS |  | HPS_IOB_17 | GPIO1_IO16,UART1_CTS_N,NAND_ADQ8,I3C0_SDA,EMAC2_TXD0,TRACE_D6 |  | HPS_IOB_17 |  |  | F75
HPS |  | HPS_IOB_18 | GPIO1_IO17,SPIM0_SS1_N,UART1_RTS_N,NAND_ADQ9,I3C0_SCL,EMAC2_TXD1,TRACE_D5 |  | HPS_IOB_18 |  |  | AD71
HPS |  | HPS_IOB_19 | GPIO1_IO18,SPIM0_MISO,MDIO1_MDIO,I2C_EMAC1_SDA,NAND_ADQ10,EMAC2_RXD0,TRACE_D4 |  | HPS_IOB_19 |  |  | K71
HPS |  | HPS_IOB_20 | GPIO1_IO19,SPIM0_SS0_N,MDIO1_MDC,I2C_EMAC1_SCL,NAND_ADQ11,EMAC2_RXD1,TRACE_CLK |  | HPS_IOB_20 |  |  | AK71
HPS |  | HPS_IOB_21 | GPIO1_IO20,SPIM0_CLK,SPIS1_CLK,I2C_EMAC2_SDA,NAND_ADQ12,I3C0_SDA_PULLUP_EN,EMAC2_TXD2,TRACE_D0 |  | HPS_IOB_21 |  |  | F74
HPS |  | HPS_IOB_22 | GPIO1_IO21,SPIM0_MOSI,SPIS1_MOSI,I2C_EMAC2_SCL,NAND_ADQ13,I3C1_SDA_PULLUP_EN,EMAC2_TXD3,TRACE_D1 |  | HPS_IOB_22 |  |  | AA71
HPS |  | HPS_IOB_23 | GPIO1_IO22,SPIM0_MISO,SPIS1_SS0_N,MDIO0_MDIO,I2C_EMAC0_SDA,NAND_ADQ14,EMAC2_RXD2,TRACE_D2 |  | HPS_IOB_23 |  |  | C74
HPS |  | HPS_IOB_24 | GPIO1_IO23,SPIM0_SS0_N,SPIS1_MISO,MDIO0_MDC,I2C_EMAC0_SCL,NAND_ADQ15,EMAC2_RXD3,TRACE_D3 |  | HPS_IOB_24 |  |  | D71
2A_T | 95 | IO | IOB |  |  | DIFF_IO_2A_T1n | No | DJ9 | DQ0 | DQ0 | DQ0
2A_T | 94 | IO | IOB |  |  | DIFF_IO_2A_T1p | No | DK9 | DQ0 | DQ0 | DQ0
2A_T | 93 | IO | IOB |  |  | DIFF_IO_2A_T2n | No | DD9 | DQ0 | DQ0 | DQ0
2A_T | 92 | IO | IOB |  |  | DIFF_IO_2A_T2p | No | DD12 | DQ0 | DQ0 | DQ0
2A_T | 91 | IO | IOB |  |  | DIFF_IO_2A_T3n | No | DF12 | DQSn0 | DQ0 | DQ0
2A_T | 90 | IO | IOB |  |  | DIFF_IO_2A_T3p | No | DJ12 | DQS0 | DQ0 | DQ0
2A_T | 89 | IO | IOB |  |  | DIFF_IO_2A_T4n | No | DJ18 | DQSn1 | DQSn0/CQn0 | DQ0
2A_T | 88 | IO | IOB |  |  | DIFF_IO_2A_T4p | No | DK18 | DQS1 | DQS0/CQ0 | DQ0
2A_T | 87 | IO | IOB |  |  | DIFF_IO_2A_T5n | Yes | DD18 | DQ1 | DQ0 | DQ0
2A_T | 86 | IO | IOB |  |  | DIFF_IO_2A_T5p | Yes | DD21 | DQ1 | DQ0 | DQ0
2A_T | 85 | IO | IOB |  |  | DIFF_IO_2A_T6n | No | DF21 | DQ1 | DQ0 | DQ0
2A_T | 84 | IO | IOB |  |  | DIFF_IO_2A_T6p | No | DJ21 | DQ1 | DQ0 | DQ0
2A_T | 83 | IO | IOB |  |  | DIFF_IO_2A_T7n | No | DN7 | DQ2 | DQ1 | DQ0
2A_T | 82 | IO | IOB |  |  | DIFF_IO_2A_T7p | No | DN3 | DQ2 | DQ1 | DQ0
2A_T | 81 | IO | IOB |  |  | DIFF_IO_2A_T8n | No | DN10 | DQ2 | DQ1 | DQ0
2A_T | 80 | IO | IOB |  |  | DIFF_IO_2A_T8p | No | DP7 | DQ2 | DQ1 | DQ0
2A_T | 79 | IO | IOB |  |  | DIFF_IO_2A_T9n | No | DP13 | DQSn2 | DQ1 | DQ0
2A_T | 78 | IO | IOB |  |  | DIFF_IO_2A_T9p | No | DP10 | DQS2 | DQ1 | DQ0
2A_T | 77 | IO | IOB |  |  | DIFF_IO_2A_T10n | No | DN15 | DQSn3 | DQSn1/CQn1 | DQSn0/CQn0
2A_T | 76 | IO | IOB |  |  | DIFF_IO_2A_T10p | No | DP15 | DQS3 | DQS1/CQ1 | DQS0/CQ0
2A_T | 75 | IO | IOB |  |  | DIFF_IO_2A_T11n | Yes | DN20 | DQ3 | DQ1 | DQ0
2A_T | 74 | IO | IOB |  |  | DIFF_IO_2A_T11p | Yes | DP22 | DQ3 | DQ1 | DQ0
2A_T | 73 | IO | IOB |  |  | DIFF_IO_2A_T12n | No | DN17 | DQ3 | DQ1 | DQ0
2A_T | 72 | IO | IOB |  |  | DIFF_IO_2A_T12p | No | DP20 | DQ3 | DQ1 | DQ0
2A_T | 71 | IO | IOB |  |  | DIFF_IO_2A_T13n | No | DJ24 | DQ4 | DQ2 | DQ1
2A_T | 70 | IO | IOB |  |  | DIFF_IO_2A_T13p | No | DK24 | DQ4 | DQ2 | DQ1
2A_T | 69 | IO | IOB |  |  | DIFF_IO_2A_T14n | No | DD24 | DQ4 | DQ2 | DQ1
2A_T | 68 | IO | IOB |  |  | DIFF_IO_2A_T14p | No | DD27 | DQ4 | DQ2 | DQ1
2A_T | 67 | IO | IOB |  |  | DIFF_IO_2A_T15n | No | DF27 | DQSn4 | DQ2 | DQ1
2A_T | 66 | IO | IOB |  |  | DIFF_IO_2A_T15p | No | DJ27 | DQS4 | DQ2 | DQ1
2A_T | 65 | IO | IOB,PLL_2A_T_CLKOUT1n |  |  | DIFF_IO_2A_T16n | No | DJ32 | DQSn5 | DQSn2/CQn2 | DQ1
2A_T | 64 | IO | IOB,PLL_2A_T_CLKOUT1p,PLL_2A_T_CLKOUT1,PLL_2A_T_FB1 |  |  | DIFF_IO_2A_T16p | No | DK32 | DQS5 | DQS2/CQ2 | DQ1
2A_T | 63 | IO | IOB |  |  | DIFF_IO_2A_T17n | Yes | DD32 | DQ5 | DQ2 | DQ1
2A_T | 62 | IO | IOB,RZQ_T_2A |  |  | DIFF_IO_2A_T17p | Yes | DD35 | DQ5 | DQ2 | DQ1
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

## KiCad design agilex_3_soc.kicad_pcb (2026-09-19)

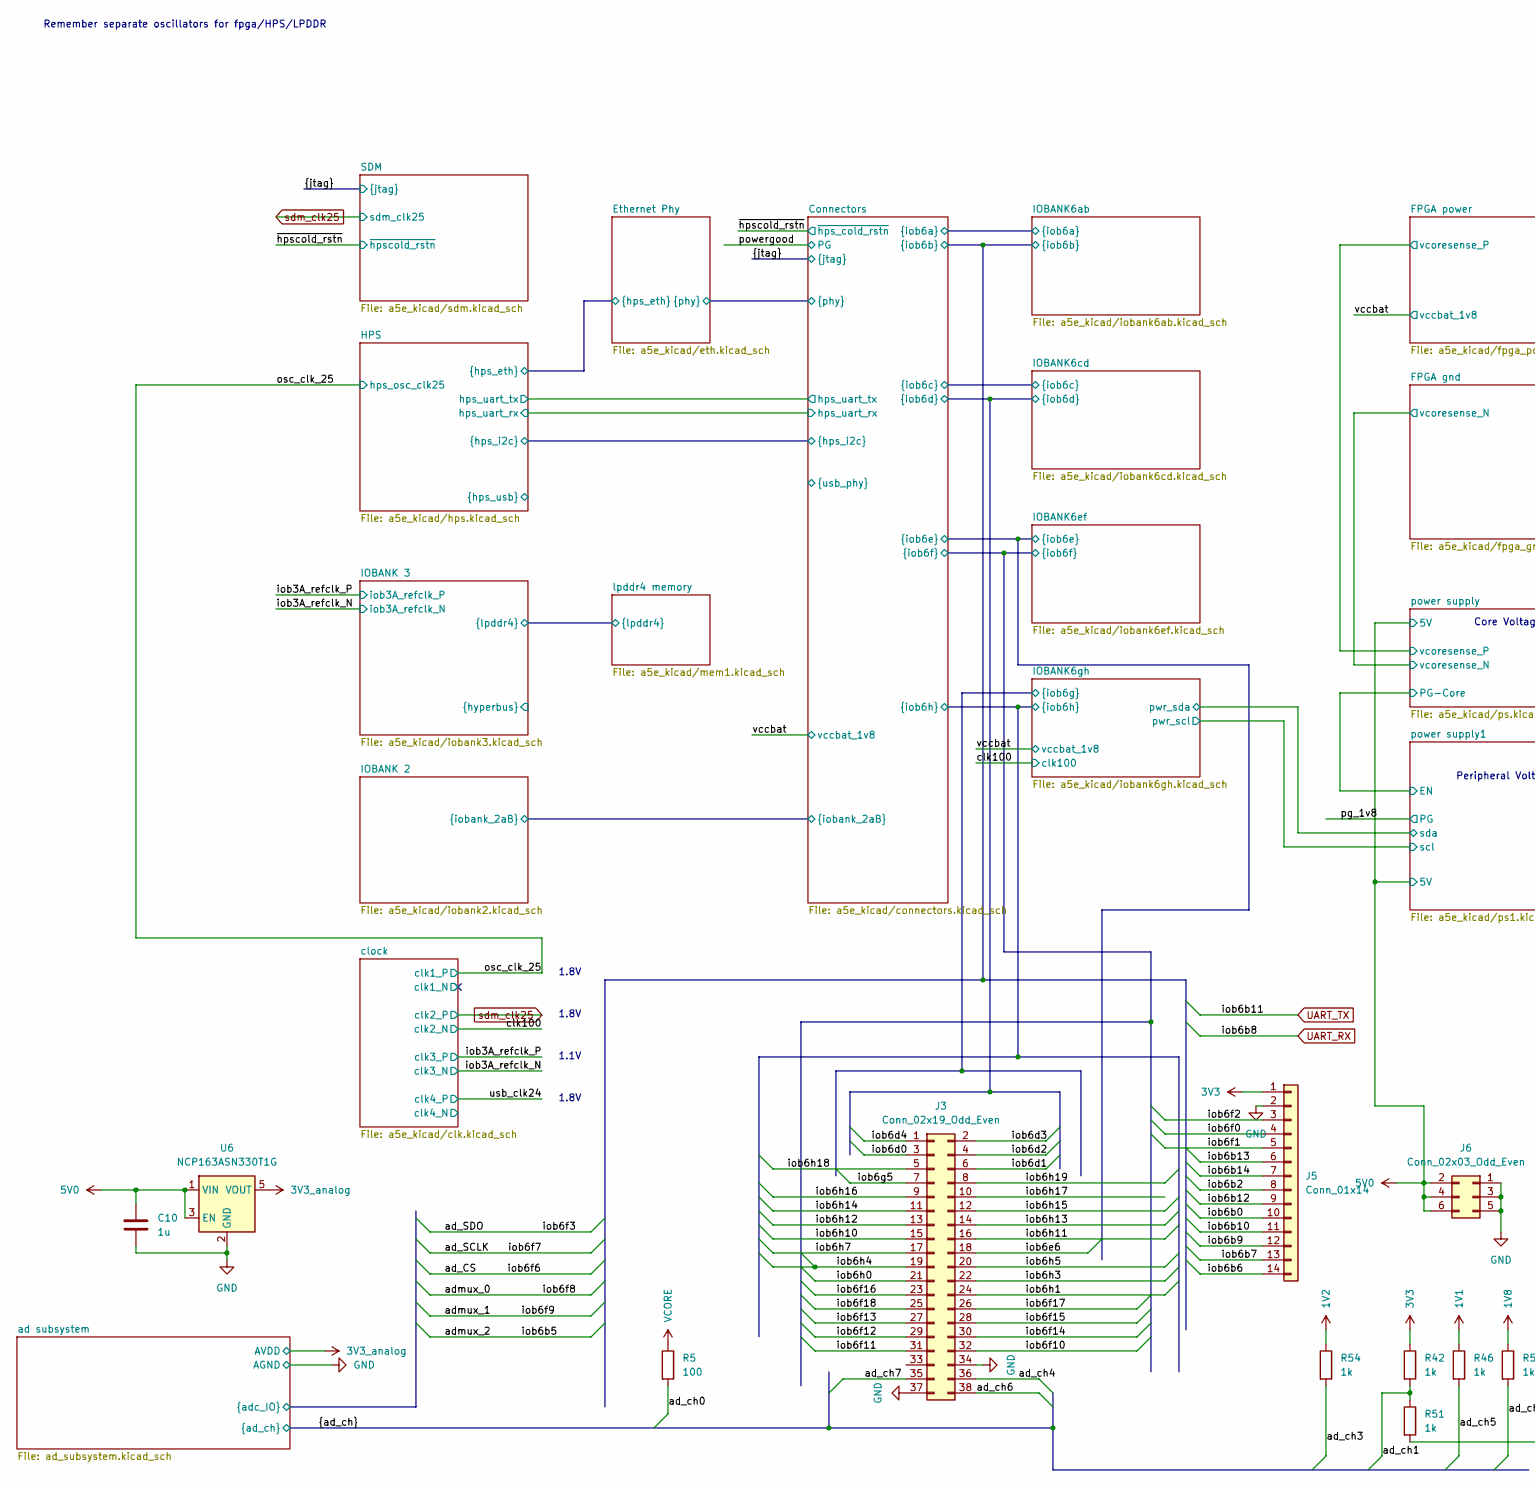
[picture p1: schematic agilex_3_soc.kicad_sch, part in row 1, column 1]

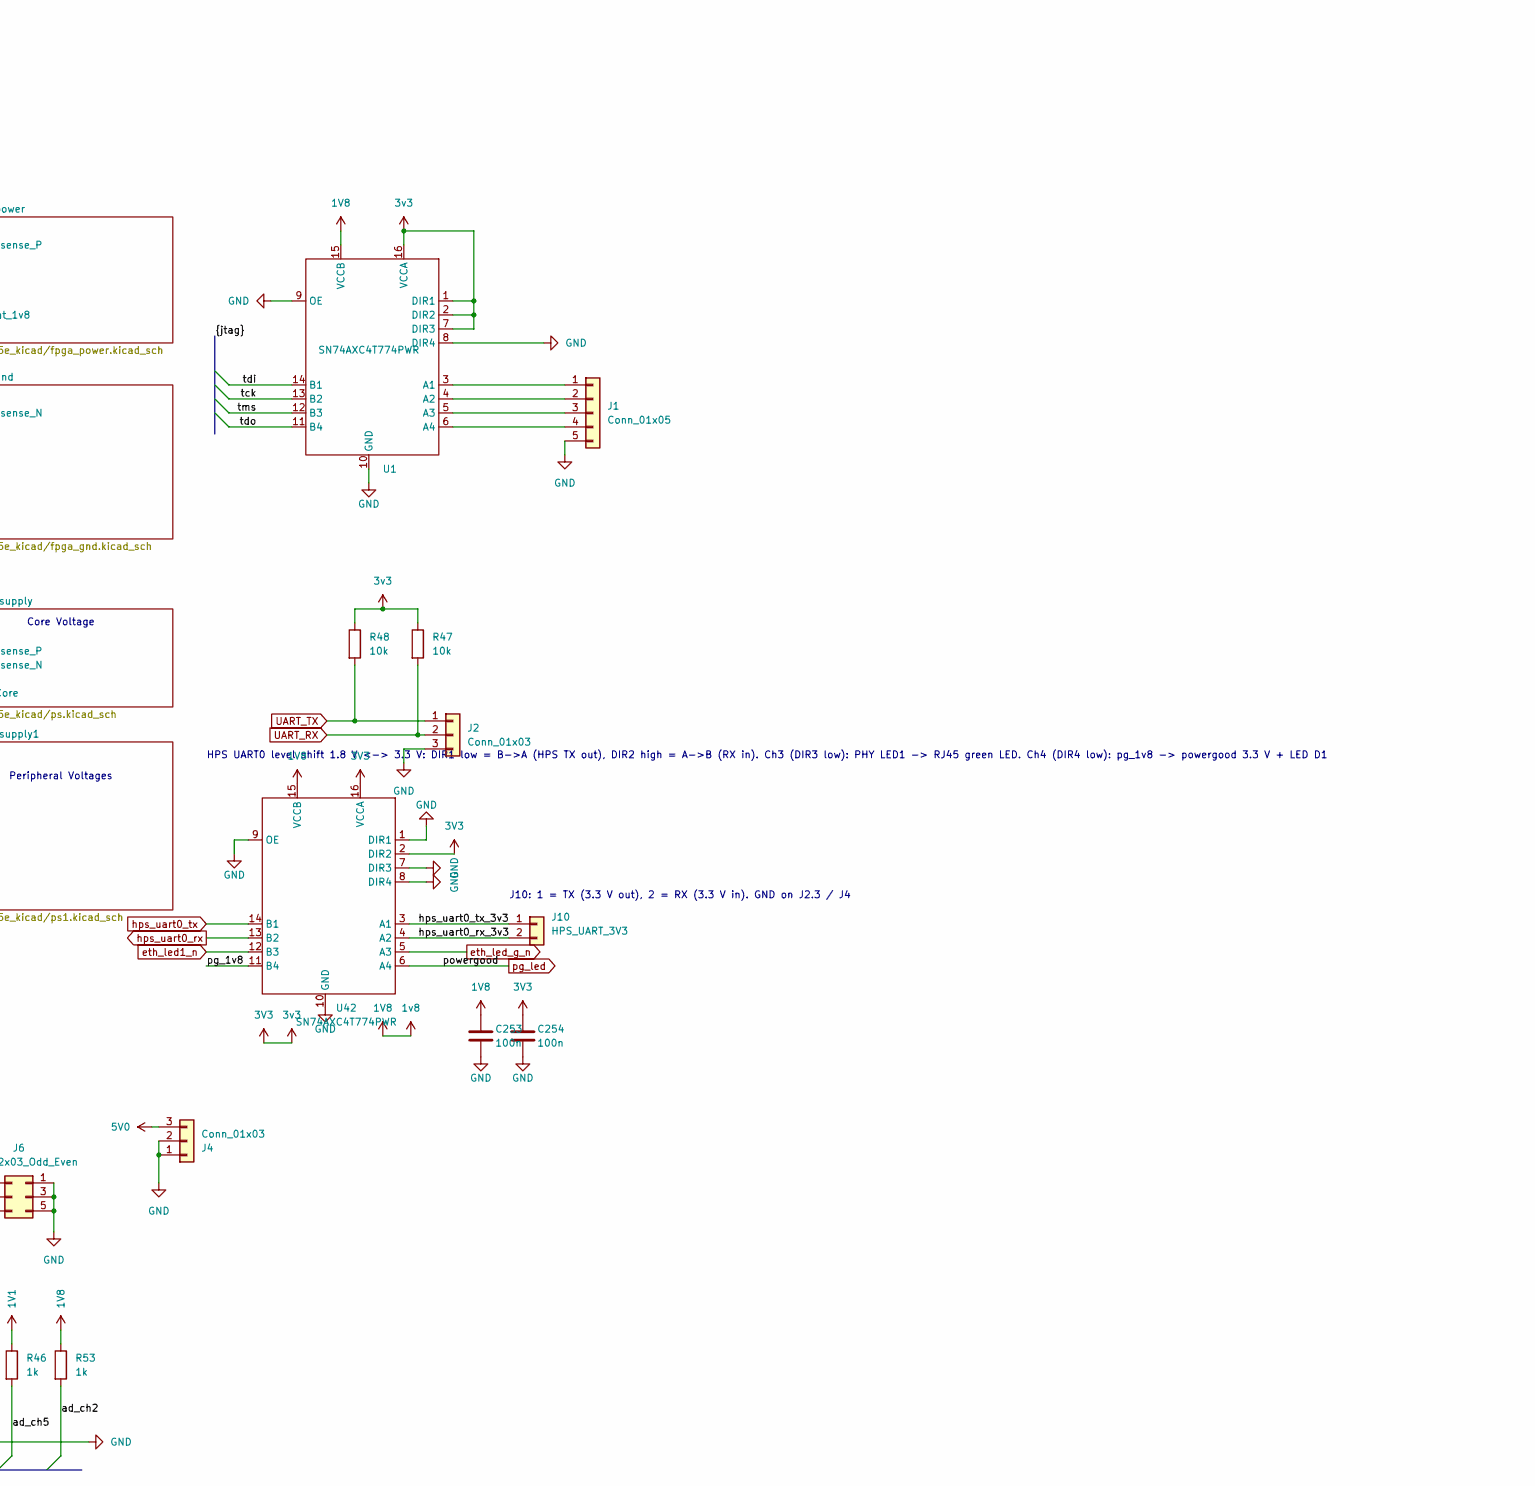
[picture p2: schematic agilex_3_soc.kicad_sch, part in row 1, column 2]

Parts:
C10: 1u; C_0603_1608Metric
C253, C254: 100n; C_0402_1005Metric
J1: Conn_01x05; PinHeader_1x05_P2.54mm_Vertical
J2, J4: Conn_01x03; PinHeader_1x03_P2.54mm_Vertical
J3: Conn_02x19_Odd_Even; PinHeader_2x19_P1.27mm_Vertical
J5: Conn_01x14; PinHeader_1x14_P2.54mm_Vertical
J6: Conn_02x03_Odd_Even; PinHeader_2x03_P1.27mm_Vertical
J10: HPS_UART_3V3; PinHeader_1x02_P2.54mm_Vertical
R5: 100; R_0402_1005Metric
R42, R51: 1k; C_0402_1005Metric
R46, R53, R54: 1k; R_0402_1005Metric
R47, R48: 10k; R_0402_1005Metric
U1, U42: SN74AXC4T774PWR; TSSOP-16_4.4x5mm_P0.65mm
U6: NCP163ASN330T1G; SOT-23-5

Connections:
1V1: R46.1; also elsewhere on the board
1V2: R54.1; also elsewhere on the board
1V8: C253.1, R53.1, U1.15 (VCCB), U42.15 (VCCB); also elsewhere on the board
3V3: C254.1, J5.1, R42.1, R47.1, R48.1, U1.1 (DIR1), U1.2 (DIR2), U1.7 (DIR3), U1.16 (VCCA), U42.2 (DIR2), U42.16 (VCCA); also elsewhere on the board
3V3_analog: U6.5 (VOUT); also elsewhere on the board
5V0: C10.1, J4.3, J6.2, J6.4, J6.6, U6.1 (VIN), U6.3 (EN); also elsewhere on the board
/Connectors/iob6b0: J5.10; also elsewhere on the board
/Connectors/iob6b2: J5.8; also elsewhere on the board
/Connectors/iob6b6: J5.14; also elsewhere on the board
/Connectors/iob6b7: J5.13; also elsewhere on the board
/Connectors/iob6b9: J5.12; also elsewhere on the board
/Connectors/iob6b10: J5.11; also elsewhere on the board
/Connectors/iob6b12: J5.9; also elsewhere on the board
/Connectors/iob6b13: J5.6; also elsewhere on the board
/Connectors/iob6b14: J5.7; also elsewhere on the board
/Connectors/iob6d0: J3.3; also elsewhere on the board
/Connectors/iob6d1: J3.6; also elsewhere on the board
/Connectors/iob6d2: J3.4; also elsewhere on the board
/Connectors/iob6d3: J3.2; also elsewhere on the board
/Connectors/iob6d4: J3.1; also elsewhere on the board
/Connectors/iob6e6: J3.18; also elsewhere on the board
/Connectors/iob6f0: J5.4; also elsewhere on the board
/Connectors/iob6f1: J5.5; also elsewhere on the board
/Connectors/iob6f2: J5.3; also elsewhere on the board
/Connectors/iob6f10: J3.32; also elsewhere on the board
/Connectors/iob6f11: J3.31; also elsewhere on the board
/Connectors/iob6f12: J3.29; also elsewhere on the board
/Connectors/iob6f13: J3.27; also elsewhere on the board
/Connectors/iob6f14: J3.30; also elsewhere on the board
/Connectors/iob6f15: J3.28; also elsewhere on the board
/Connectors/iob6f16: J3.23; also elsewhere on the board
/Connectors/iob6f17: J3.26; also elsewhere on the board
/Connectors/iob6f18: J3.25; also elsewhere on the board
/Connectors/iob6h0: J3.21; also elsewhere on the board
/Connectors/iob6h1: J3.24; also elsewhere on the board
/Connectors/iob6h3: J3.22; also elsewhere on the board
/Connectors/iob6h4: J3.19; also elsewhere on the board
/Connectors/iob6h5: J3.20; also elsewhere on the board
/Connectors/iob6h7: J3.17; also elsewhere on the board
/Connectors/iob6h10: J3.15; also elsewhere on the board
/Connectors/iob6h11: J3.16; also elsewhere on the board
/Connectors/iob6h12: J3.13; also elsewhere on the board
/Connectors/iob6h13: J3.14; also elsewhere on the board
/Connectors/iob6h14: J3.11; also elsewhere on the board
/Connectors/iob6h15: J3.12; also elsewhere on the board
/Connectors/iob6h16: J3.9; also elsewhere on the board
/Connectors/iob6h17: J3.10; also elsewhere on the board
/Connectors/iob6h18: J3.5; also elsewhere on the board
/Connectors/iob6h19: J3.8; also elsewhere on the board
/IOBANK6gh/iob6g5: J3.7; also elsewhere on the board
/ad_ch0: R5.2; also elsewhere on the board
/ad_ch1: R42.2, R51.1; also elsewhere on the board
/ad_ch2: R53.2; also elsewhere on the board
/ad_ch3: R54.2; also elsewhere on the board
/ad_ch4: J3.36; also elsewhere on the board
/ad_ch5: R46.2; also elsewhere on the board
/ad_ch6: J3.38; also elsewhere on the board
/ad_ch7: J3.35; also elsewhere on the board
/hps_uart0_rx_3v3: J10.2, U42.4 (A2)
/hps_uart0_tx_3v3: J10.1, U42.3 (A1)
/pg_1v8: U42.11 (B4); also elsewhere on the board
/tck: U1.13 (B2); also elsewhere on the board
/tdi: U1.14 (B1); also elsewhere on the board
/tdo: U1.11 (B4); also elsewhere on the board
/tms: U1.12 (B3); also elsewhere on the board
GND: C10.2, C253.2, C254.2, J1.5, J2.3, J3.34, J3.37, J4.1, J4.2, J5.2, J6.1, J6.3, J6.5, R51.2, U1.8 (DIR4), U1.9 (OE), U1.10 (GND), U6.2 (GND), U42.1 (DIR1), U42.7 (DIR3), U42.8 (DIR4), U42.9 (OE), U42.10 (GND); also elsewhere on the board
unnamed: J1.1, U1.3 (A1)
unnamed: J1.2, U1.4 (A2)
unnamed: J1.3, U1.5 (A3)
unnamed: J1.4, U1.6 (A4)
UART_RX: J2.2, R47.2; also elsewhere on the board
UART_TX: J2.1, R48.2; also elsewhere on the board
VCORE: R5.1; also elsewhere on the board
eth_led1_n: U42.12 (B3); also elsewhere on the board
eth_led_g_n: U42.5 (A3); also elsewhere on the board
hps_uart0_rx: U42.13 (B2); also elsewhere on the board
hps_uart0_tx: U42.14 (B1); also elsewhere on the board
pg_led: U42.6 (A4); also elsewhere on the board

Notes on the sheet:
HPS UART0 level shift 1.8 V <-> 3.3 V: DIR1 low = B->A (HPS TX out), DIR2 high = A->B (RX in). Ch3 (DIR3 low): PHY LED1 -> RJ45 green LED. Ch4 (DIR4 low): pg_1v8 -> powergood 3.3 V + LED D1
1.8V
Core Voltage
Remember separate oscillators for fpga/HPS/LPDDR
Peripheral Voltages
1.1V
J10: 1 = TX (3.3 V out), 2 = RX (3.3 V in). GND on J2.3 / J4

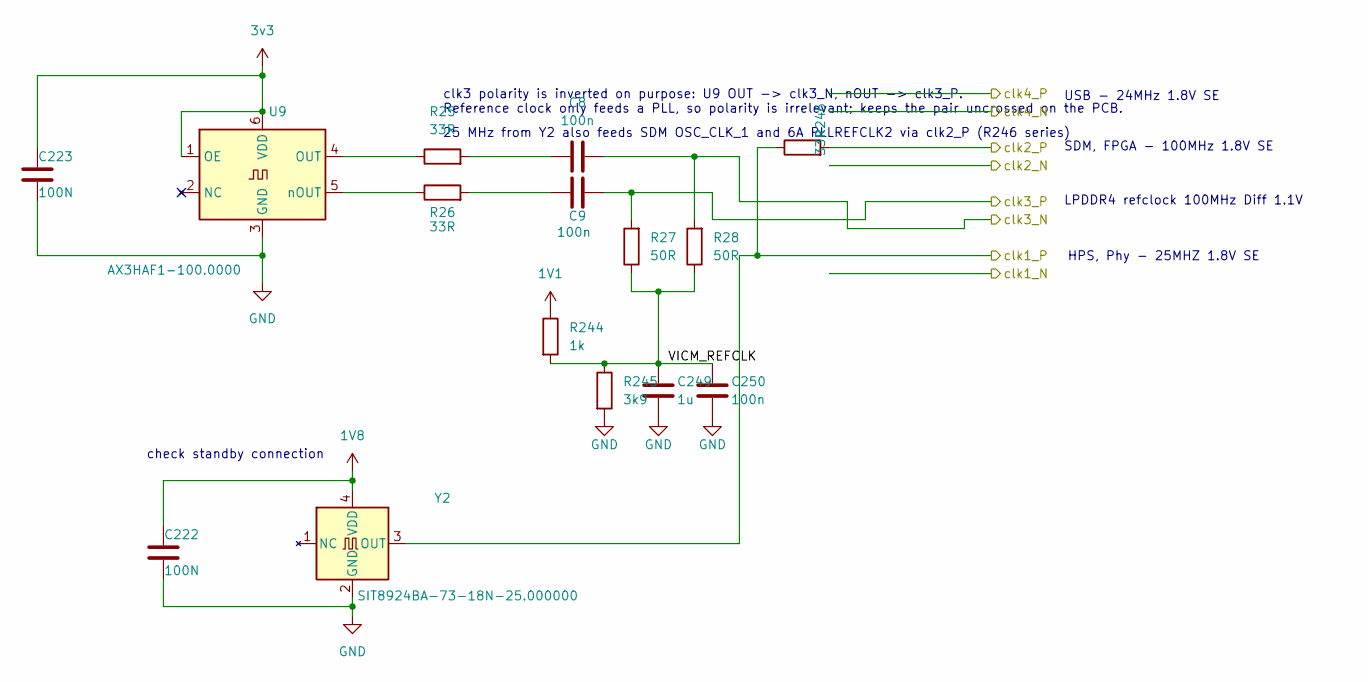
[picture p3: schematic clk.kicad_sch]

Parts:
C8, C9, C250: 100n; C_0402_1005Metric
C222, C223: 100N; C_0201_0603Metric
C249: 1u; C_0402_1005Metric
R25: 33R; C_0402_1005Metric
R26, R246: 33R; R_0402_1005Metric
R27, R28: 50R; R_0402_1005Metric
R244: 1k; R_0402_1005Metric
R245: 3k9; R_0402_1005Metric
U9: AX3HAF1-100.0000; Oscillator_SMD_SiTime_SiT9121-6Pin_3.2x2.5mm
Y2: SIT8924BA-73-18N-25.000000; Oscillator_SMD_SiT_PQFN-4Pin_2.0x1.6mm

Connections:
1V1: R244.1; also elsewhere on the board
1V8: C222.1, Y2.4 (VDD); also elsewhere on the board
3V3: C223.1, U9.1 (OE), U9.6 (VDD); also elsewhere on the board
/clock/VICM_REFCLK: C249.1, C250.1, R27.1, R28.1, R244.2, R245.1
/iob3A_refclk_N: C8.2, R28.2; also elsewhere on the board
/iob3A_refclk_P: C9.2, R27.2; also elsewhere on the board
/osc_clk_25: R246.1, Y2.3 (OUT); also elsewhere on the board
GND: C222.2, C223.2, C249.2, C250.2, R245.2, U9.3 (GND), Y2.2 (GND); also elsewhere on the board
unnamed: C8.1, R25.2
unnamed: C9.1, R26.2
unnamed: R25.1, U9.4 (OUT)
unnamed: R26.1, U9.5 (nOUT)
sdm_clk25: R246.2; also elsewhere on the board

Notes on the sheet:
25 MHz from Y2 also feeds SDM OSC_CLK_1 and 6A PLLREFCLK2 via clk2_P (R246 series)
LPDDR4 refclock 100MHz Diff 1.1V
check standby connection
USB - 24MHz 1.8V SE
SDM, FPGA - 100MHz 1.8V SE
HPS, Phy - 25MHZ 1.8V SE
clk3 polarity is inverted on purpose: U9 OUT -> clk3_N, nOUT -> clk3_P. Reference clock only feeds a PLL, so polarity is irrelevant; keeps the pair uncrossed on the PCB.

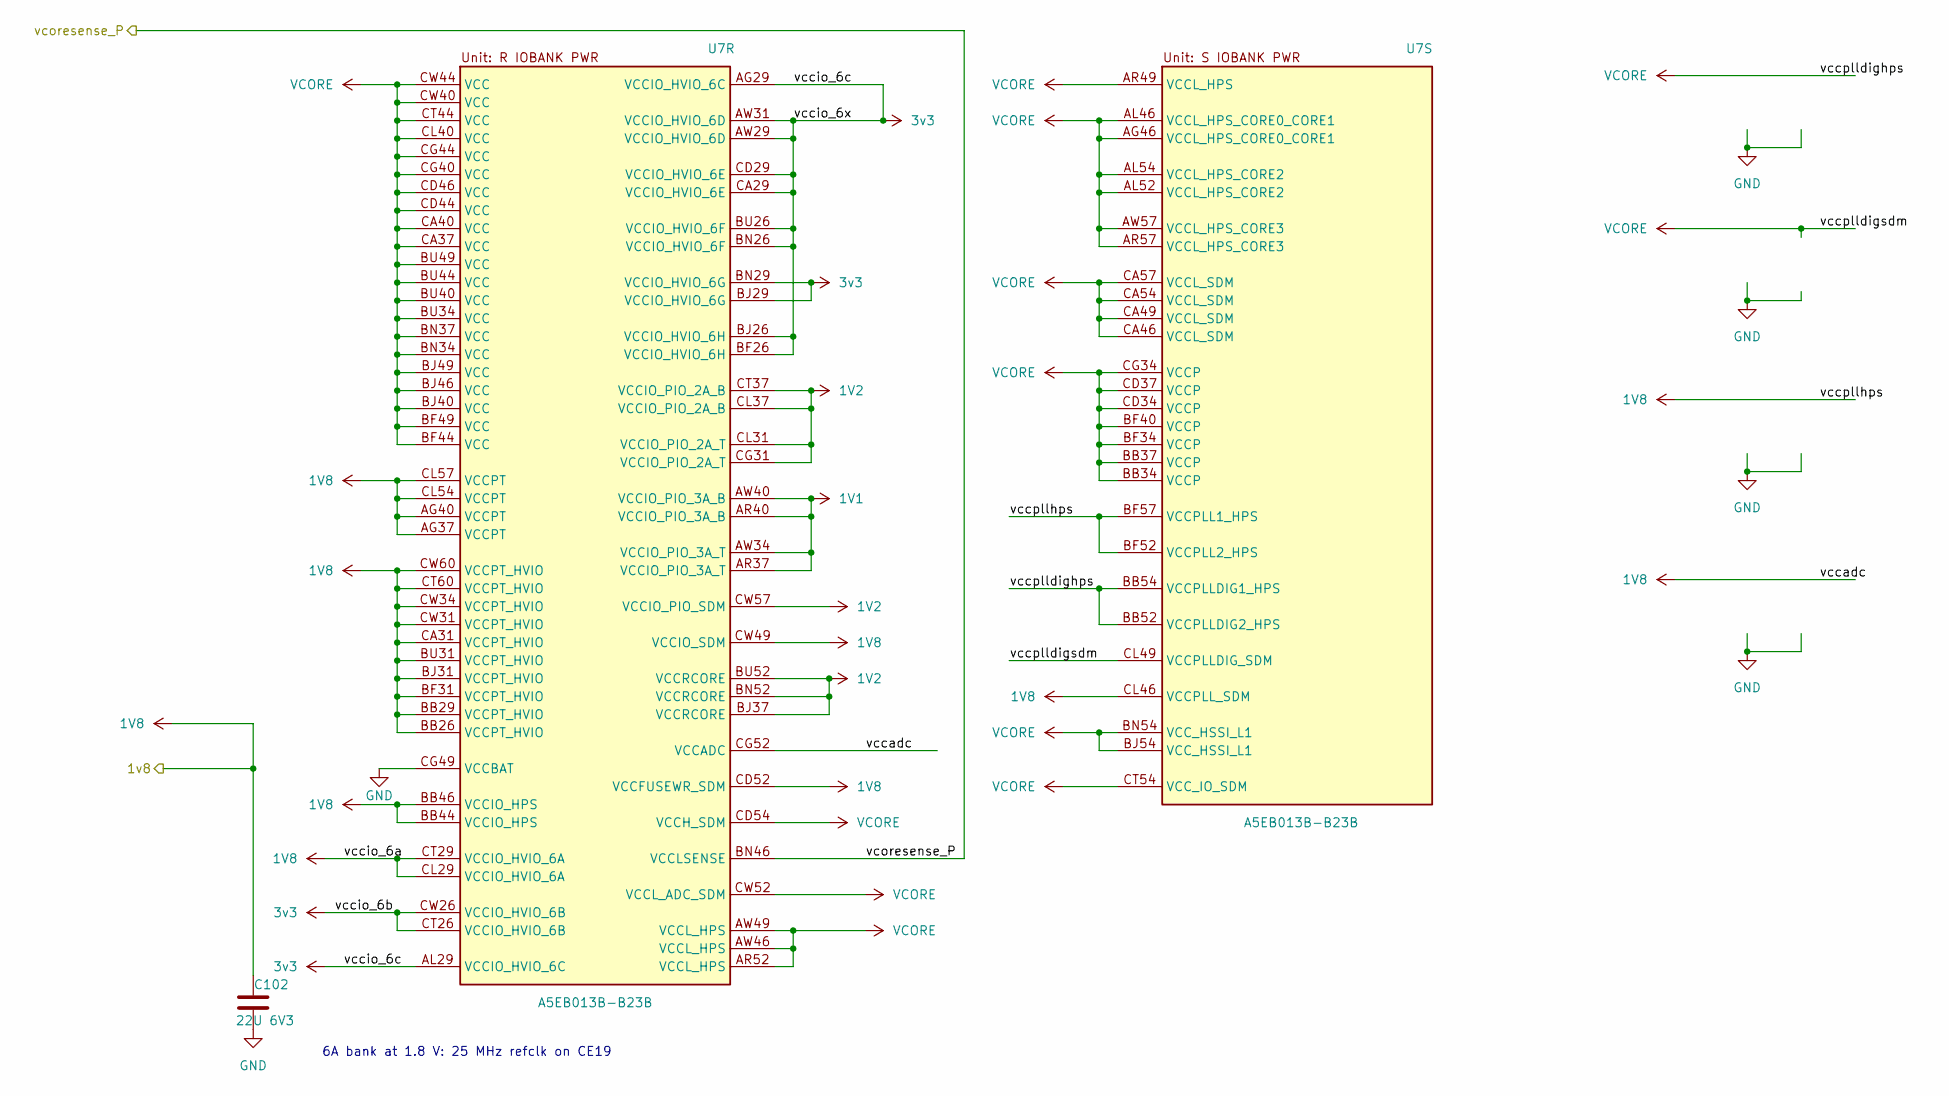
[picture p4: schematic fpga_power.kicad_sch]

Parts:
C102: 22U 6V3; C_0201_0603Metric
U7: A5EB013B-B23B; VFBGA_b23b_mirror

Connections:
1V1: U7.AR37 (VCCIO_PIO_3A_T), U7.AR40 (VCCIO_PIO_3A_B), U7.AW34 (VCCIO_PIO_3A_T), U7.AW40 (VCCIO_PIO_3A_B); also elsewhere on the board
1V2: U7.BJ37 (VCCRCORE), U7.BN52 (VCCRCORE), U7.BU52 (VCCRCORE), U7.CG31 (VCCIO_PIO_2A_T), U7.CL31 (VCCIO_PIO_2A_T), U7.CL37 (VCCIO_PIO_2A_B), U7.CT37 (VCCIO_PIO_2A_B), U7.CW57 (VCCIO_PIO_SDM); also elsewhere on the board
1V8: C102.1, U7.AG37 (VCCPT), U7.AG40 (VCCPT), U7.BB26 (VCCPT_HVIO), U7.BB29 (VCCPT_HVIO), U7.BB44 (VCCIO_HPS), U7.BB46 (VCCIO_HPS), U7.BF31 (VCCPT_HVIO), U7.BF52 (VCCPLL2_HPS), U7.BF57 (VCCPLL1_HPS), U7.BJ31 (VCCPT_HVIO), U7.BU31 (VCCPT_HVIO), U7.CA31 (VCCPT_HVIO), U7.CD52 (VCCFUSEWR_SDM), U7.CG52 (VCCADC), U7.CL29 (VCCIO_HVIO_6A), U7.CL46 (VCCPLL_SDM), U7.CL54 (VCCPT), U7.CL57 (VCCPT), U7.CT29 (VCCIO_HVIO_6A), U7.CT60 (VCCPT_HVIO), U7.CW31 (VCCPT_HVIO), U7.CW34 (VCCPT_HVIO), U7.CW49 (VCCIO_SDM), U7.CW60 (VCCPT_HVIO); also elsewhere on the board
3V3: U7.AG29 (VCCIO_HVIO_6C), U7.AL29 (VCCIO_HVIO_6C), U7.AW29 (VCCIO_HVIO_6D), U7.AW31 (VCCIO_HVIO_6D), U7.BF26 (VCCIO_HVIO_6H), U7.BJ26 (VCCIO_HVIO_6H), U7.BJ29 (VCCIO_HVIO_6G), U7.BN26 (VCCIO_HVIO_6F), U7.BN29 (VCCIO_HVIO_6G), U7.BU26 (VCCIO_HVIO_6F), U7.CA29 (VCCIO_HVIO_6E), U7.CD29 (VCCIO_HVIO_6E), U7.CT26 (VCCIO_HVIO_6B), U7.CW26 (VCCIO_HVIO_6B); also elsewhere on the board
/FPGA power/vcoresense_P: U7.BN46 (VCCLSENSE); also elsewhere on the board
GND: C102.2, U7.CG49 (VCCBAT); also elsewhere on the board
VCORE: U7.AG46 (VCCL_HPS_CORE0_CORE1), U7.AL46 (VCCL_HPS_CORE0_CORE1), U7.AL52 (VCCL_HPS_CORE2), U7.AL54 (VCCL_HPS_CORE2), U7.AR49 (VCCL_HPS), U7.AR52 (VCCL_HPS), U7.AR57 (VCCL_HPS_CORE3), U7.AW46 (VCCL_HPS), U7.AW49 (VCCL_HPS), U7.AW57 (VCCL_HPS_CORE3), U7.BB34 (VCCP), U7.BB37 (VCCP), U7.BB52 (VCCPLLDIG2_HPS), U7.BB54 (VCCPLLDIG1_HPS), U7.BF34 (VCCP), U7.BF40 (VCCP), U7.BF44 (VCC), U7.BF49 (VCC), U7.BJ40 (VCC), U7.BJ46 (VCC), U7.BJ49 (VCC), U7.BJ54 (VCC_HSSI_L1), U7.BN34 (VCC), U7.BN37 (VCC), U7.BN54 (VCC_HSSI_L1), U7.BU34 (VCC), U7.BU40 (VCC), U7.BU44 (VCC), U7.BU49 (VCC), U7.CA37 (VCC), U7.CA40 (VCC), U7.CA46 (VCCL_SDM), U7.CA49 (VCCL_SDM), U7.CA54 (VCCL_SDM), U7.CA57 (VCCL_SDM), U7.CD34 (VCCP), U7.CD37 (VCCP), U7.CD44 (VCC), U7.CD46 (VCC), U7.CD54 (VCCH_SDM), U7.CG34 (VCCP), U7.CG40 (VCC), U7.CG44 (VCC), U7.CL40 (VCC), U7.CL49 (VCCPLLDIG_SDM), U7.CT44 (VCC), U7.CT54 (VCC_IO_SDM), U7.CW40 (VCC), U7.CW44 (VCC), U7.CW52 (VCCL_ADC_SDM); also elsewhere on the board

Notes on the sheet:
6A bank at 1.8 V: 25 MHz refclk on CE19

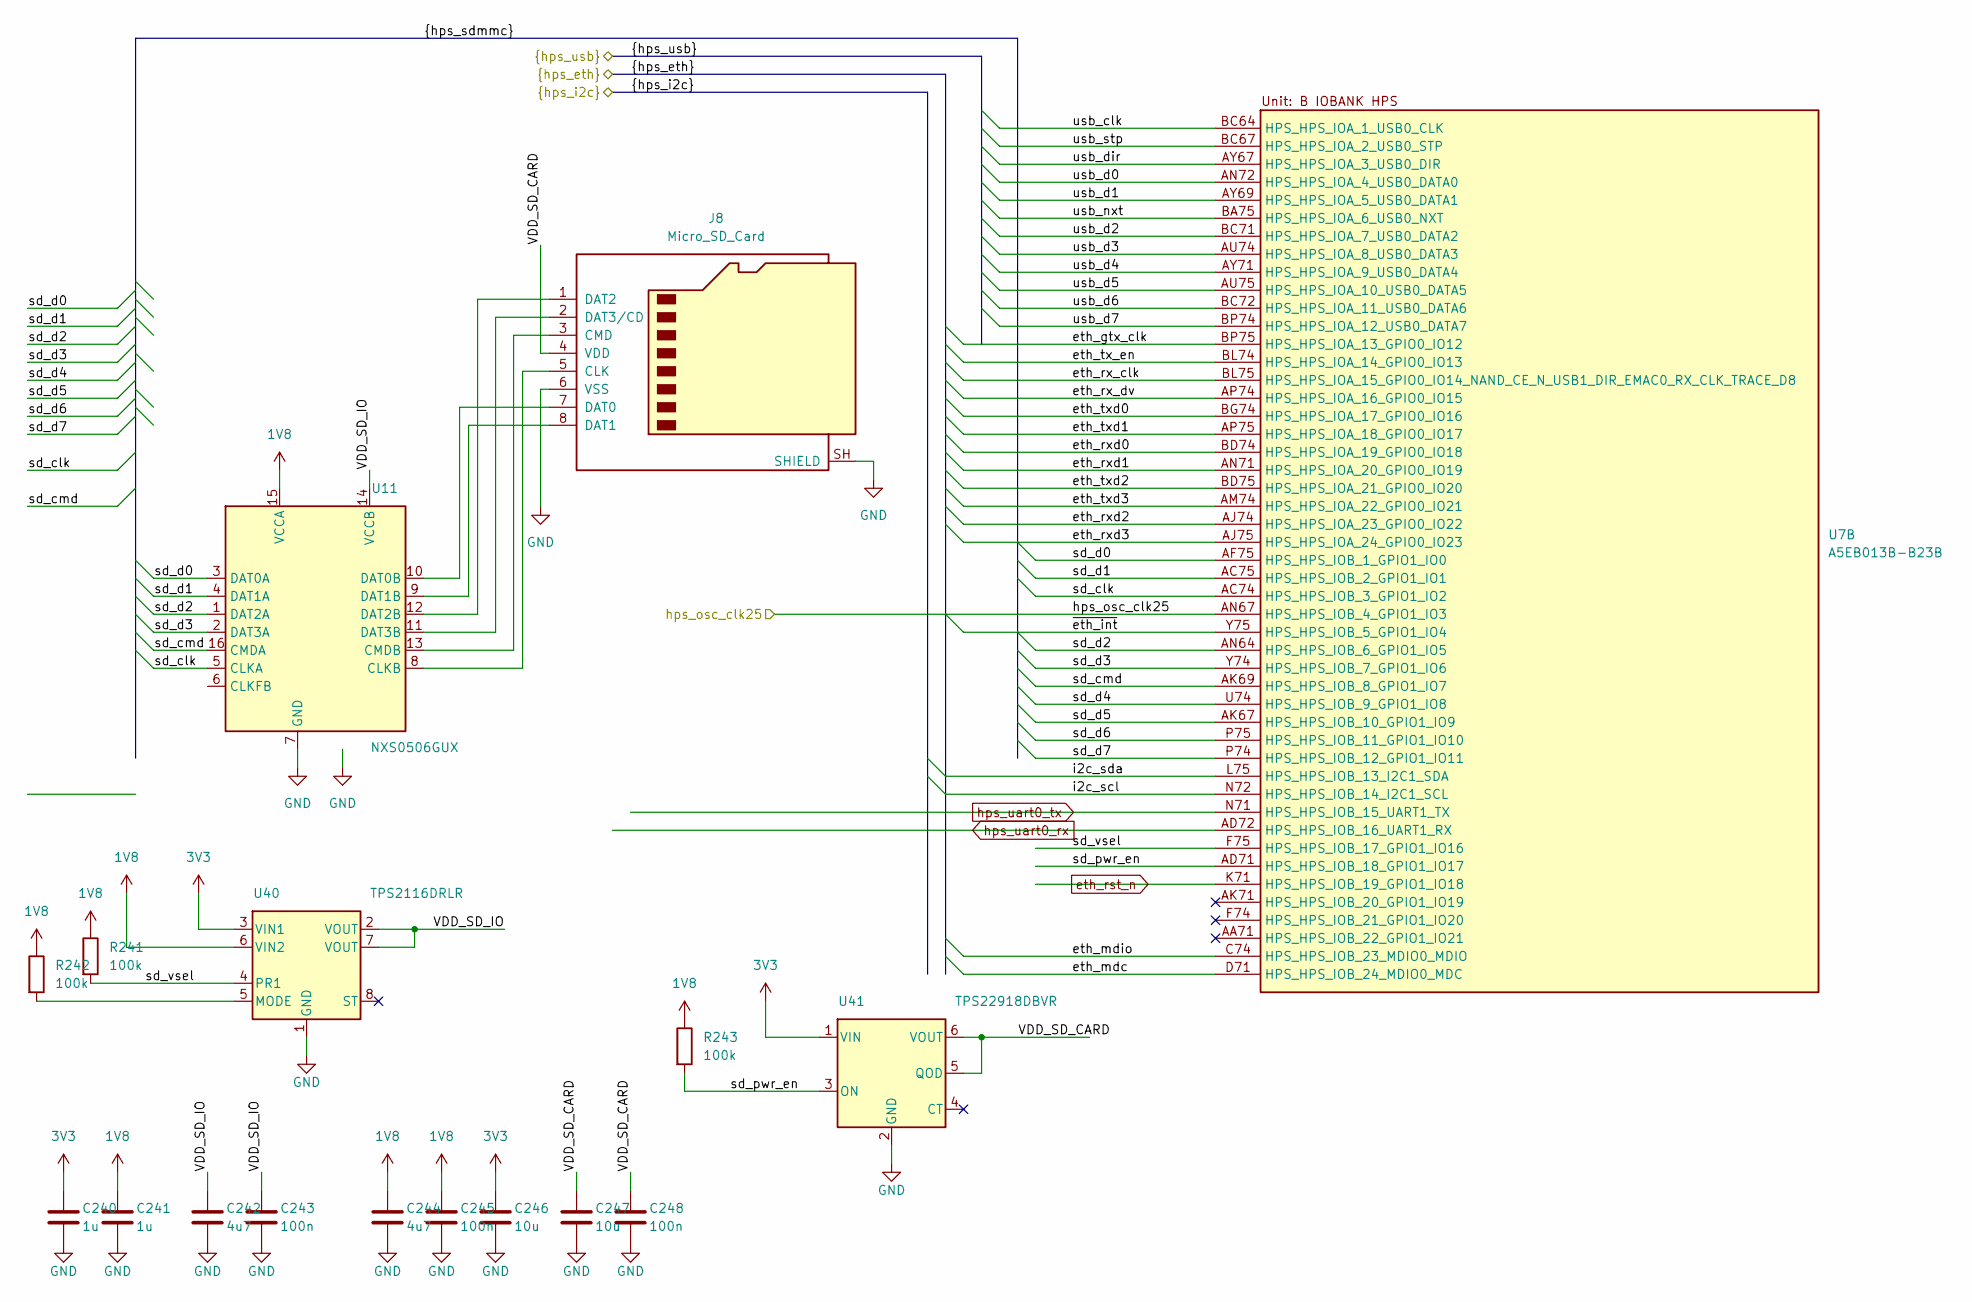
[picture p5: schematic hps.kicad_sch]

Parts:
C240, C241: 1u; C_0402_1005Metric
C242, C244: 4u7; C_0603_1608Metric
C243, C245, C248: 100n; C_0402_1005Metric
C246, C247: 10u; C_0603_1608Metric
J8: Micro_SD_Card; microSD_HC_Wuerth_693072010801
R241, R242, R243: 100k; R_0402_1005Metric
U7: A5EB013B-B23B; VFBGA_b23b_mirror
U11: NXS0506GUX; NXS0506GU_XQFN16_1.8x2.6mm_P0.4mm
U40: TPS2116DRLR; SOT-583-8
U41: TPS22918DBVR; SOT-23-6

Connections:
1V8: C241.1, C244.1, C245.1, R241.1, R242.1, R243.1, U11.15 (VCCA), U40.6 (VIN2); also elsewhere on the board
3V3: C240.1, C246.1, U40.3 (VIN1), U41.1 (VIN); also elsewhere on the board
/HPS/VDD_SD_CARD: C247.1, C248.1, J8.4 (VDD), U41.5 (QOD), U41.6 (VOUT)
/HPS/VDD_SD_IO: C242.1, C243.1, U11.14 (VCCB), U40.2 (VOUT), U40.7 (VOUT)
/HPS/eth_gtx_clk: U7.BP75 (HPS_HPS_IOA_13_GPIO0_IO12); also elsewhere on the board
/HPS/eth_mdc: U7.D71 (HPS_HPS_IOB_24_MDIO0_MDC); also elsewhere on the board
/HPS/eth_mdio: U7.C74 (HPS_HPS_IOB_23_MDIO0_MDIO); also elsewhere on the board
/HPS/eth_rx_clk: U7.BL75 (HPS_HPS_IOA_15_GPIO0_IO14_NAND_CE_N_USB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); also elsewhere on the board
/HPS/eth_rx_dv: U7.AP74 (HPS_HPS_IOA_16_GPIO0_IO15); also elsewhere on the board
/HPS/eth_rxd0: U7.BD74 (HPS_HPS_IOA_19_GPIO0_IO18); also elsewhere on the board
/HPS/eth_rxd1: U7.AN71 (HPS_HPS_IOA_20_GPIO0_IO19); also elsewhere on the board
/HPS/eth_rxd2: U7.AJ74 (HPS_HPS_IOA_23_GPIO0_IO22); also elsewhere on the board
/HPS/eth_rxd3: U7.AJ75 (HPS_HPS_IOA_24_GPIO0_IO23); also elsewhere on the board
/HPS/eth_tx_en: U7.BL74 (HPS_HPS_IOA_14_GPIO0_IO13); also elsewhere on the board
/HPS/eth_txd0: U7.BG74 (HPS_HPS_IOA_17_GPIO0_IO16); also elsewhere on the board
/HPS/eth_txd1: U7.AP75 (HPS_HPS_IOA_18_GPIO0_IO17); also elsewhere on the board
/HPS/eth_txd2: U7.BD75 (HPS_HPS_IOA_21_GPIO0_IO20); also elsewhere on the board
/HPS/eth_txd3: U7.AM74 (HPS_HPS_IOA_22_GPIO0_IO21); also elsewhere on the board
/HPS/i2c_scl: U7.N72 (HPS_HPS_IOB_14_I2C1_SCL)
/HPS/i2c_sda: U7.L75 (HPS_HPS_IOB_13_I2C1_SDA)
/HPS/sd_clk: U7.AC74 (HPS_HPS_IOB_3_GPIO1_IO2), U11.5 (CLKA)
/HPS/sd_cmd: U7.AK69 (HPS_HPS_IOB_8_GPIO1_IO7), U11.16 (CMDA)
/HPS/sd_d0: U7.AF75 (HPS_HPS_IOB_1_GPIO1_IO0), U11.3 (DAT0A)
/HPS/sd_d1: U7.AC75 (HPS_HPS_IOB_2_GPIO1_IO1), U11.4 (DAT1A)
/HPS/sd_d2: U7.AN64 (HPS_HPS_IOB_6_GPIO1_IO5), U11.1 (DAT2A)
/HPS/sd_d3: U7.Y74 (HPS_HPS_IOB_7_GPIO1_IO6), U11.2 (DAT3A)
/HPS/sd_d4: U7.U74 (HPS_HPS_IOB_9_GPIO1_IO8)
/HPS/sd_d5: U7.AK67 (HPS_HPS_IOB_10_GPIO1_IO9)
/HPS/sd_d6: U7.P75 (HPS_HPS_IOB_11_GPIO1_IO10)
/HPS/sd_d7: U7.P74 (HPS_HPS_IOB_12_GPIO1_IO11)
/HPS/sd_pwr_en: R243.2, U7.AD71 (HPS_HPS_IOB_18_GPIO1_IO17), U41.3 (ON)
/HPS/sd_vsel: R241.2, U7.F75 (HPS_HPS_IOB_17_GPIO1_IO16), U40.4 (PR1)
/HPS/usb_clk: U7.BC64 (HPS_HPS_IOA_1_USB0_CLK)
/HPS/usb_d0: U7.AN72 (HPS_HPS_IOA_4_USB0_DATA0)
/HPS/usb_d1: U7.AY69 (HPS_HPS_IOA_5_USB0_DATA1)
/HPS/usb_d2: U7.BC71 (HPS_HPS_IOA_7_USB0_DATA2)
/HPS/usb_d3: U7.AU74 (HPS_HPS_IOA_8_USB0_DATA3)
/HPS/usb_d4: U7.AY71 (HPS_HPS_IOA_9_USB0_DATA4)
/HPS/usb_d5: U7.AU75 (HPS_HPS_IOA_10_USB0_DATA5)
/HPS/usb_d6: U7.BC72 (HPS_HPS_IOA_11_USB0_DATA6)
/HPS/usb_d7: U7.BP74 (HPS_HPS_IOA_12_USB0_DATA7)
/HPS/usb_dir: U7.AY67 (HPS_HPS_IOA_3_USB0_DIR)
/HPS/usb_nxt: U7.BA75 (HPS_HPS_IOA_6_USB0_NXT)
/HPS/usb_stp: U7.BC67 (HPS_HPS_IOA_2_USB0_STP)
/HPS/~eth_int: U7.Y75 (HPS_HPS_IOB_5_GPIO1_IO4); also elsewhere on the board
/osc_clk_25: U7.AN67 (HPS_HPS_IOB_4_GPIO1_IO3); also elsewhere on the board
GND: C240.2, C241.2, C242.2, C243.2, C244.2, C245.2, C246.2, C247.2, C248.2, J8.6 (VSS), J8.SH (SHIELD), U11.7 (GND), U40.1 (GND), U41.2 (GND); also elsewhere on the board
unnamed: J8.5 (CLK), U11.8 (CLKB)
unnamed: J8.3 (CMD), U11.13 (CMDB)
unnamed: J8.7 (DAT0), U11.10 (DAT0B)
unnamed: J8.8 (DAT1), U11.9 (DAT1B)
unnamed: J8.1 (DAT2), U11.12 (DAT2B)
unnamed: J8.2 (DAT3/CD), U11.11 (DAT3B)
unnamed: R242.2, U40.5 (MODE)
eth_rst_n: U7.K71 (HPS_HPS_IOB_19_GPIO1_IO18); also elsewhere on the board
hps_uart0_rx: U7.AD72 (HPS_HPS_IOB_16_UART1_RX); also elsewhere on the board
hps_uart0_tx: U7.N71 (HPS_HPS_IOB_15_UART1_TX); also elsewhere on the board

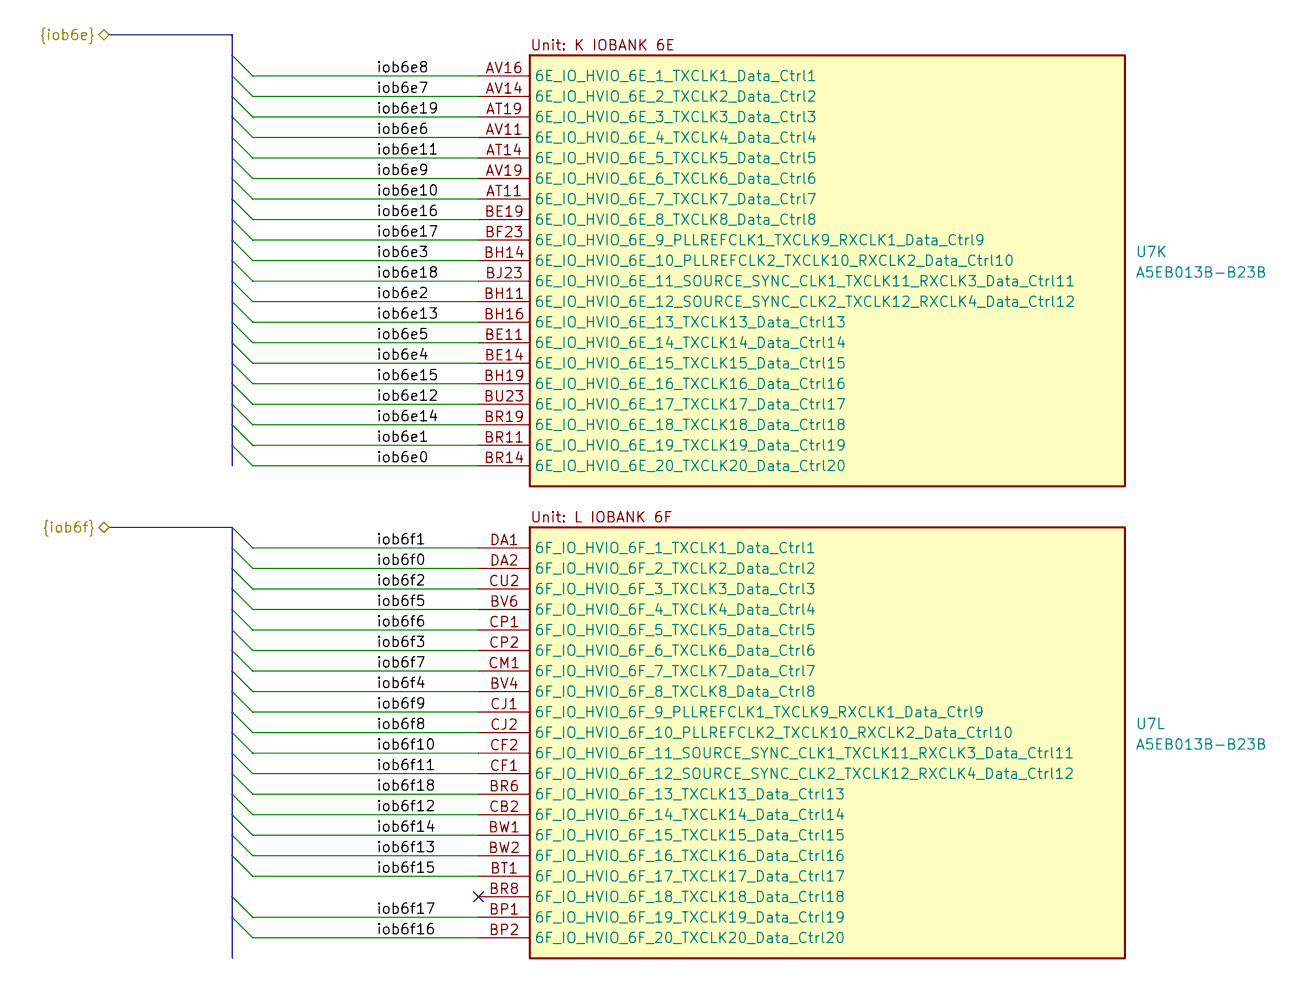
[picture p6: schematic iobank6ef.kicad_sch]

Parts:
U7: A5EB013B-B23B; VFBGA_b23b_mirror

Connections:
/Connectors/iob6e0: U7.BR14 (6E_IO_HVIO_6E_20_TXCLK20_Data_Ctrl20)
/Connectors/iob6e1: U7.BR11 (6E_IO_HVIO_6E_19_TXCLK19_Data_Ctrl19)
/Connectors/iob6e2: U7.BH11 (6E_IO_HVIO_6E_12_SOURCE_SYNC_CLK2_TXCLK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)
/Connectors/iob6e3: U7.BH14 (6E_IO_HVIO_6E_10_PLLREFCLK2_TXCLK10_RXC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)
/Connectors/iob6e4: U7.BE14 (6E_IO_HVIO_6E_15_TXCLK15_Data_Ctrl15)
/Connectors/iob6e5: U7.BE11 (6E_IO_HVIO_6E_14_TXCLK14_Data_Ctrl14)
/Connectors/iob6e6: U7.AV11 (6E_IO_HVIO_6E_4_TXCLK4_Data_Ctrl4); also elsewhere on the board
/Connectors/iob6e7: U7.AV14 (6E_IO_HVIO_6E_2_TXCLK2_Data_Ctrl2)
/Connectors/iob6e8: U7.AV16 (6E_IO_HVIO_6E_1_TXCLK1_Data_Ctrl1)
/Connectors/iob6e9: U7.AV19 (6E_IO_HVIO_6E_6_TXCLK6_Data_Ctrl6)
/Connectors/iob6e10: U7.AT11 (6E_IO_HVIO_6E_7_TXCLK7_Data_Ctrl7)
/Connectors/iob6e11: U7.AT14 (6E_IO_HVIO_6E_5_TXCLK5_Data_Ctrl5)
/Connectors/iob6e12: U7.BU23 (6E_IO_HVIO_6E_17_TXCLK17_Data_Ctrl17)
/Connectors/iob6e13: U7.BH16 (6E_IO_HVIO_6E_13_TXCLK13_Data_Ctrl13)
/Connectors/iob6e14: U7.BR19 (6E_IO_HVIO_6E_18_TXCLK18_Data_Ctrl18)
/Connectors/iob6e15: U7.BH19 (6E_IO_HVIO_6E_16_TXCLK16_Data_Ctrl16)
/Connectors/iob6e16: U7.BE19 (6E_IO_HVIO_6E_8_TXCLK8_Data_Ctrl8)
/Connectors/iob6e17: U7.BF23 (6E_IO_HVIO_6E_9_PLLREFCLK1_TXCLK9_RXCLK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)
/Connectors/iob6e18: U7.BJ23 (6E_IO_HVIO_6E_11_SOURCE_SYNC_CLK1_TXCLK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)
/Connectors/iob6e19: U7.AT19 (6E_IO_HVIO_6E_3_TXCLK3_Data_Ctrl3)
/Connectors/iob6f0: U7.DA2 (6F_IO_HVIO_6F_2_TXCLK2_Data_Ctrl2); also elsewhere on the board
/Connectors/iob6f1: U7.DA1 (6F_IO_HVIO_6F_1_TXCLK1_Data_Ctrl1); also elsewhere on the board
/Connectors/iob6f2: U7.CU2 (6F_IO_HVIO_6F_3_TXCLK3_Data_Ctrl3); also elsewhere on the board
/Connectors/iob6f3: U7.CP2 (6F_IO_HVIO_6F_6_TXCLK6_Data_Ctrl6); also elsewhere on the board
/Connectors/iob6f4: U7.BV4 (6F_IO_HVIO_6F_8_TXCLK8_Data_Ctrl8)
/Connectors/iob6f5: U7.BV6 (6F_IO_HVIO_6F_4_TXCLK4_Data_Ctrl4)
/Connectors/iob6f6: U7.CP1 (6F_IO_HVIO_6F_5_TXCLK5_Data_Ctrl5); also elsewhere on the board
/Connectors/iob6f7: U7.CM1 (6F_IO_HVIO_6F_7_TXCLK7_Data_Ctrl7); also elsewhere on the board
/Connectors/iob6f8: U7.CJ2 (6F_IO_HVIO_6F_10_PLLREFCLK2_TXCLK10_RXC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); also elsewhere on the board
/Connectors/iob6f9: U7.CJ1 (6F_IO_HVIO_6F_9_PLLREFCLK1_TXCLK9_RXCLK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); also elsewhere on the board
/Connectors/iob6f10: U7.CF2 (6F_IO_HVIO_6F_11_SOURCE_SYNC_CLK1_TXCLK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); also elsewhere on the board
/Connectors/iob6f11: U7.CF1 (6F_IO_HVIO_6F_12_SOURCE_SYNC_CLK2_TXCLK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); also elsewhere on the board
/Connectors/iob6f12: U7.CB2 (6F_IO_HVIO_6F_14_TXCLK14_Data_Ctrl14); also elsewhere on the board
/Connectors/iob6f13: U7.BW2 (6F_IO_HVIO_6F_16_TXCLK16_Data_Ctrl16); also elsewhere on the board
/Connectors/iob6f14: U7.BW1 (6F_IO_HVIO_6F_15_TXCLK15_Data_Ctrl15); also elsewhere on the board
/Connectors/iob6f15: U7.BT1 (6F_IO_HVIO_6F_17_TXCLK17_Data_Ctrl17); also elsewhere on the board
/Connectors/iob6f16: U7.BP2 (6F_IO_HVIO_6F_20_TXCLK20_Data_Ctrl20); also elsewhere on the board
/Connectors/iob6f17: U7.BP1 (6F_IO_HVIO_6F_19_TXCLK19_Data_Ctrl19); also elsewhere on the board
/Connectors/iob6f18: U7.BR6 (6F_IO_HVIO_6F_13_TXCLK13_Data_Ctrl13); also elsewhere on the board

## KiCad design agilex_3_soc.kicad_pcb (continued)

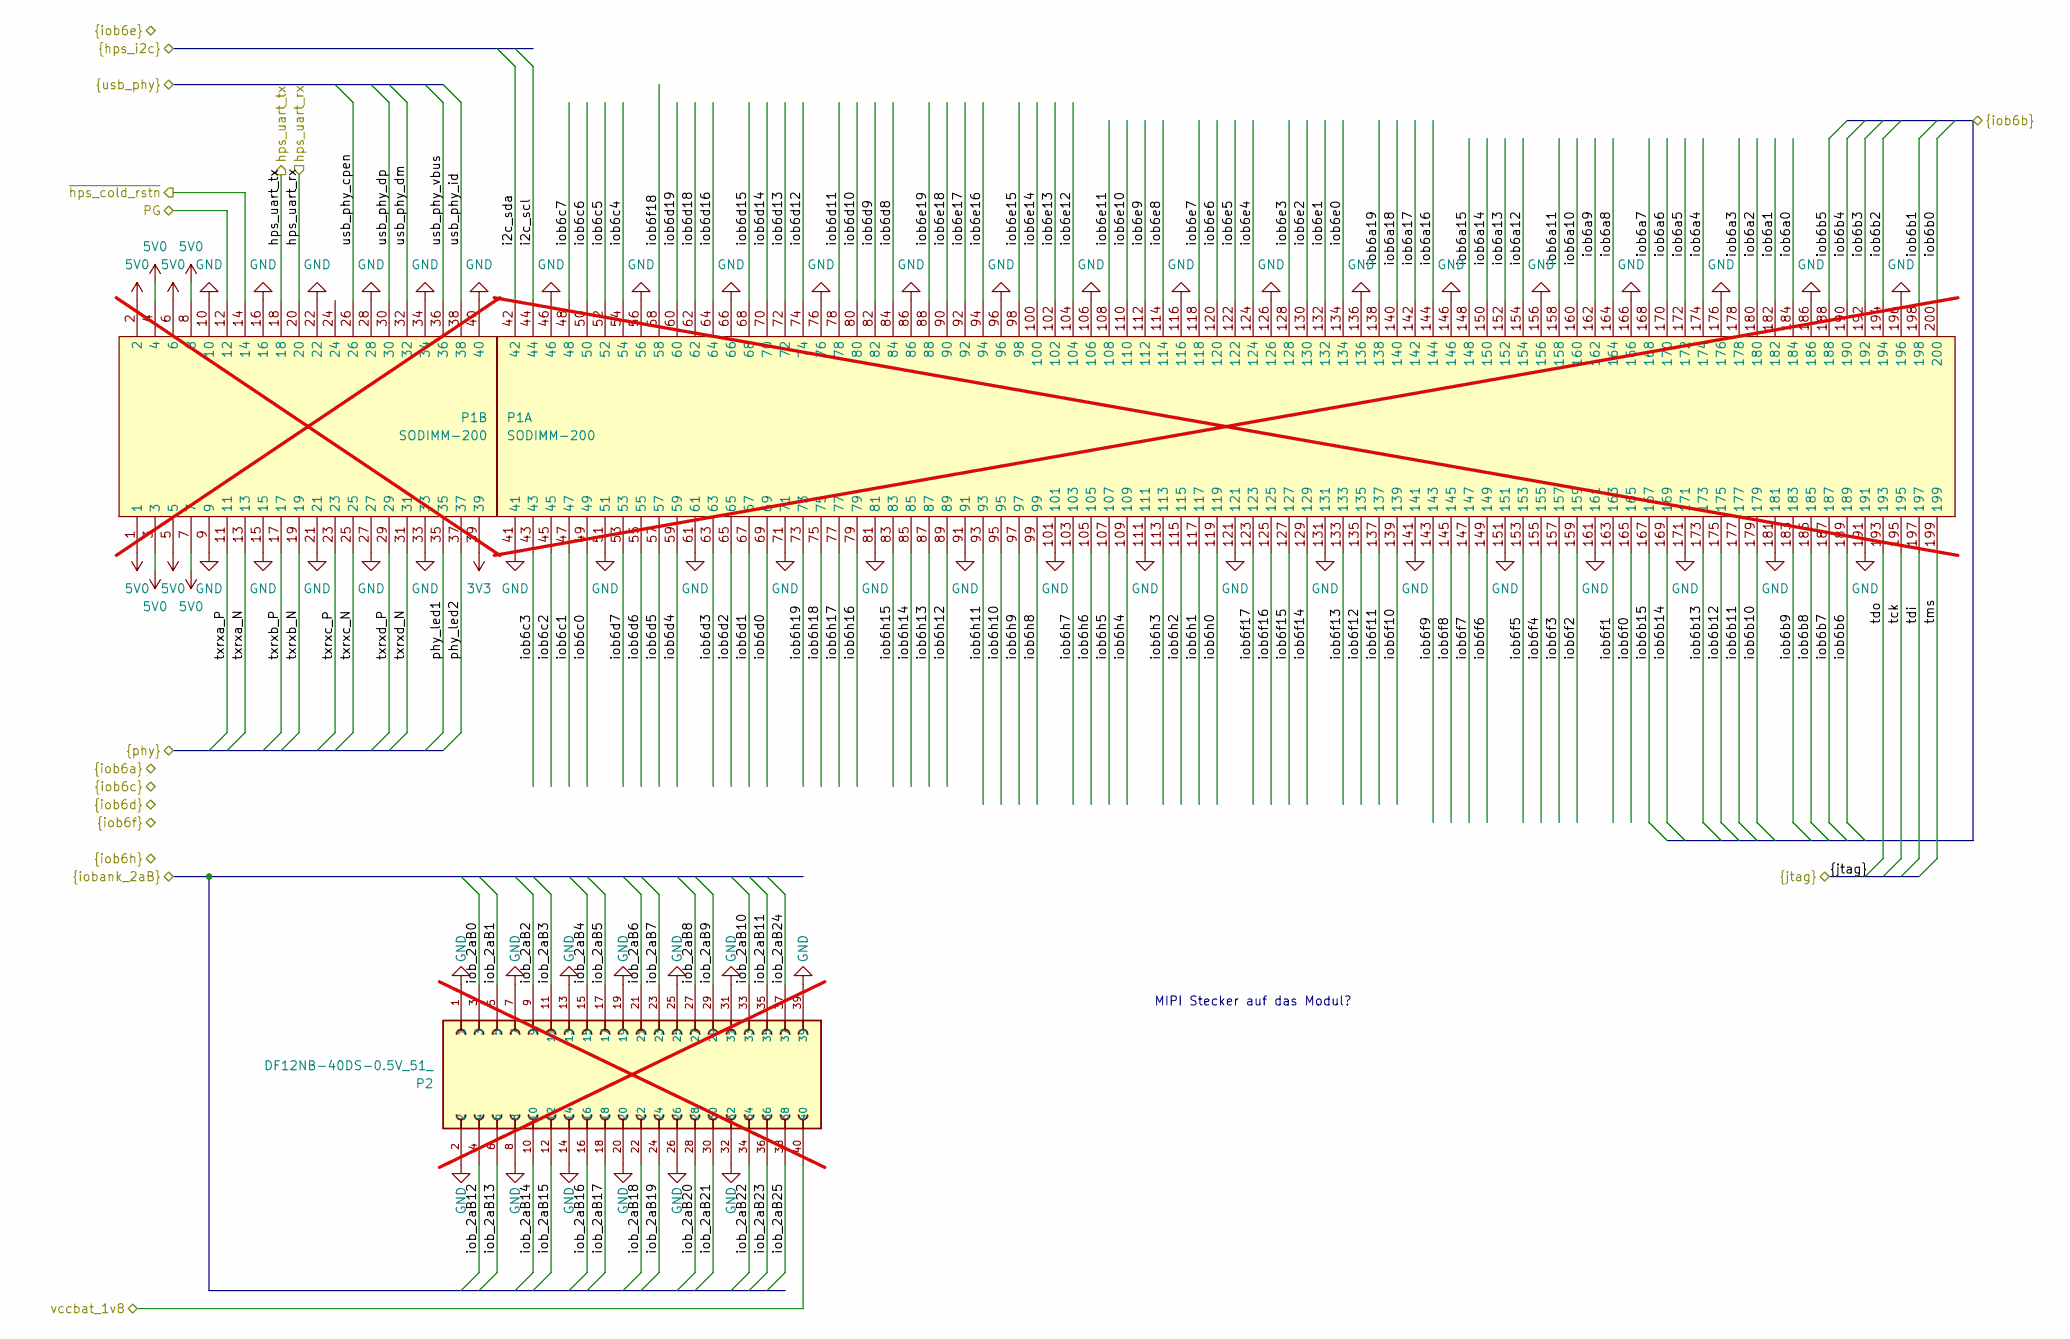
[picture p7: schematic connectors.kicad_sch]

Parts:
P1: SODIMM-200; DIMM-SO200; not fitted
P2: DF12NB-40DS-0.5V_51_; HRS_DF12NB-40DS-0.5V_51_; not fitted

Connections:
unnamed: P1.1, P1.2, P1.3, P1.4, P1.5, P1.6, P1.7, P1.8
unnamed: P1.9, P1.10, P1.15, P1.16, P1.21, P1.22, P1.27, P1.28, P1.33, P1.34, P1.40, P1.41, P1.46, P1.51, P1.56, P1.61, P1.66, P1.71, P1.76, P1.81, P1.86, P1.91, P1.96, P1.101, P1.106, P1.111, P1.116, P1.121, P1.126, P1.131, P1.136, P1.141, P1.146, P1.151, P1.156, P1.161, P1.166, P1.171, P1.176, P1.181, P1.186, P1.191, P1.196, P2.1, P2.2, P2.7, P2.8, P2.13, P2.14, P2.19, P2.20, P2.25, P2.26, P2.31, P2.32, P2.39

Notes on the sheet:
MIPI Stecker auf das Modul?

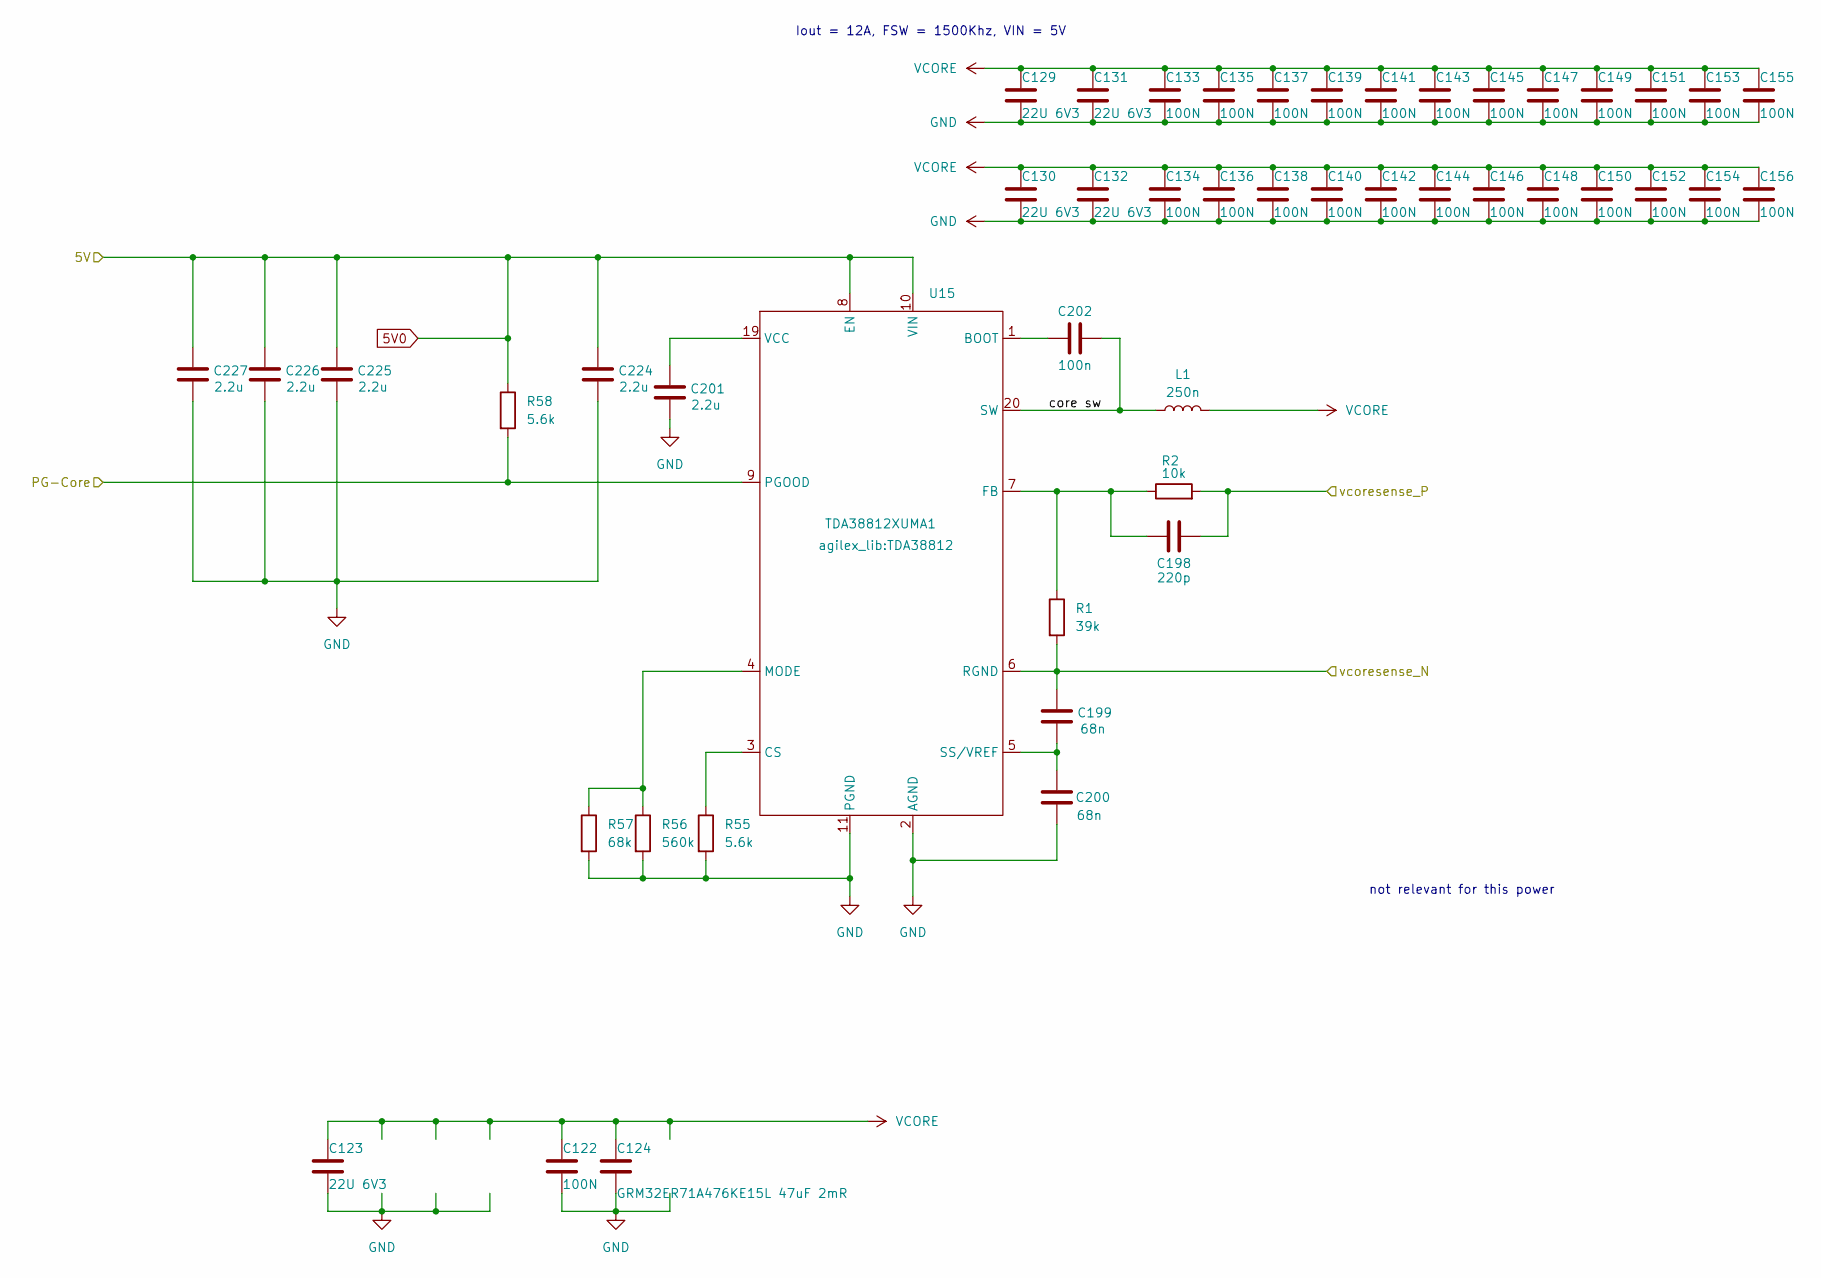
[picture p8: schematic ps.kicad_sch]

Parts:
C122, C133, C134, C135, C136, C137, C138, C139, C140, C141, C142, C143, C144, C145, C146, C147, C148, C149, C150, C151, C152, C153, C154, C155, C156: 100N; C_0201_0603Metric
C123, C129, C130, C131, C132: 22U 6V3; C_0402_1005Metric
C124: GRM32ER71A476KE15L 47uF 2mR; C_1210_3225Metric
C198: 220p; C_0402_1005Metric
C199, C200: 68n; C_0402_1005Metric
C201, C224, C225, C226, C227: 2.2u; C_0402_1005Metric
C202: 100n; C_0402_1005Metric
L1: 250n; CMLE051H
R1: 39k; R_0402_1005Metric
R2: 10k; R_0402_1005Metric
R55, R58: 5.6k; R_0402_1005Metric
R56: 560k; R_0402_1005Metric
R57: 68k; R_0402_1005Metric
U15: TDA38812XUMA1; TDA38812

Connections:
5V0: C224.2, C225.2, C226.2, C227.2, R58.1, U15.8 (EN), U15.10 (VIN); also elsewhere on the board
/FPGA gnd/vcoresense_N: C199.2, R1.2, U15.6 (RGND); also elsewhere on the board
/FPGA power/vcoresense_P: C198.2, R2.2; also elsewhere on the board
/power supply/PG-Core: R58.2, U15.9 (PGOOD); also elsewhere on the board
/power supply/core sw: C202.2, L1.1, U15.20 (SW)
GND: C122.2, C123.2, C124.2, C129.2, C130.2, C131.2, C132.2, C133.2, C134.2, C135.2, C136.2, C137.2, C138.2, C139.2, C140.2, C141.2, C142.2, C143.2, C144.2, C145.2, C146.2, C147.2, C148.2, C149.2, C150.2, C151.2, C152.2, C153.2, C154.2, C155.2, C156.2, C200.1, C201.1, C224.1, C225.1, C226.1, C227.1, R55.2, R56.2, R57.2, U15.2 (AGND), U15.11 (PGND); also elsewhere on the board
unnamed: C202.1, U15.1 (BOOT)
unnamed: R55.1, U15.3 (CS)
unnamed: C198.1, R1.1, R2.1, U15.7 (FB)
unnamed: R56.1, R57.1, U15.4 (MODE)
unnamed: C199.1, C200.2, U15.5 (SS/VREF)
unnamed: C201.2, U15.19 (VCC)
VCORE: C122.1, C123.1, C124.1, C129.1, C130.1, C131.1, C132.1, C133.1, C134.1, C135.1, C136.1, C137.1, C138.1, C139.1, C140.1, C141.1, C142.1, C143.1, C144.1, C145.1, C146.1, C147.1, C148.1, C149.1, C150.1, C151.1, C152.1, C153.1, C154.1, C155.1, C156.1, L1.2; also elsewhere on the board

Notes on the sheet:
not relevant for this power
Iout = 12A, FSW = 1500Khz, VIN = 5V

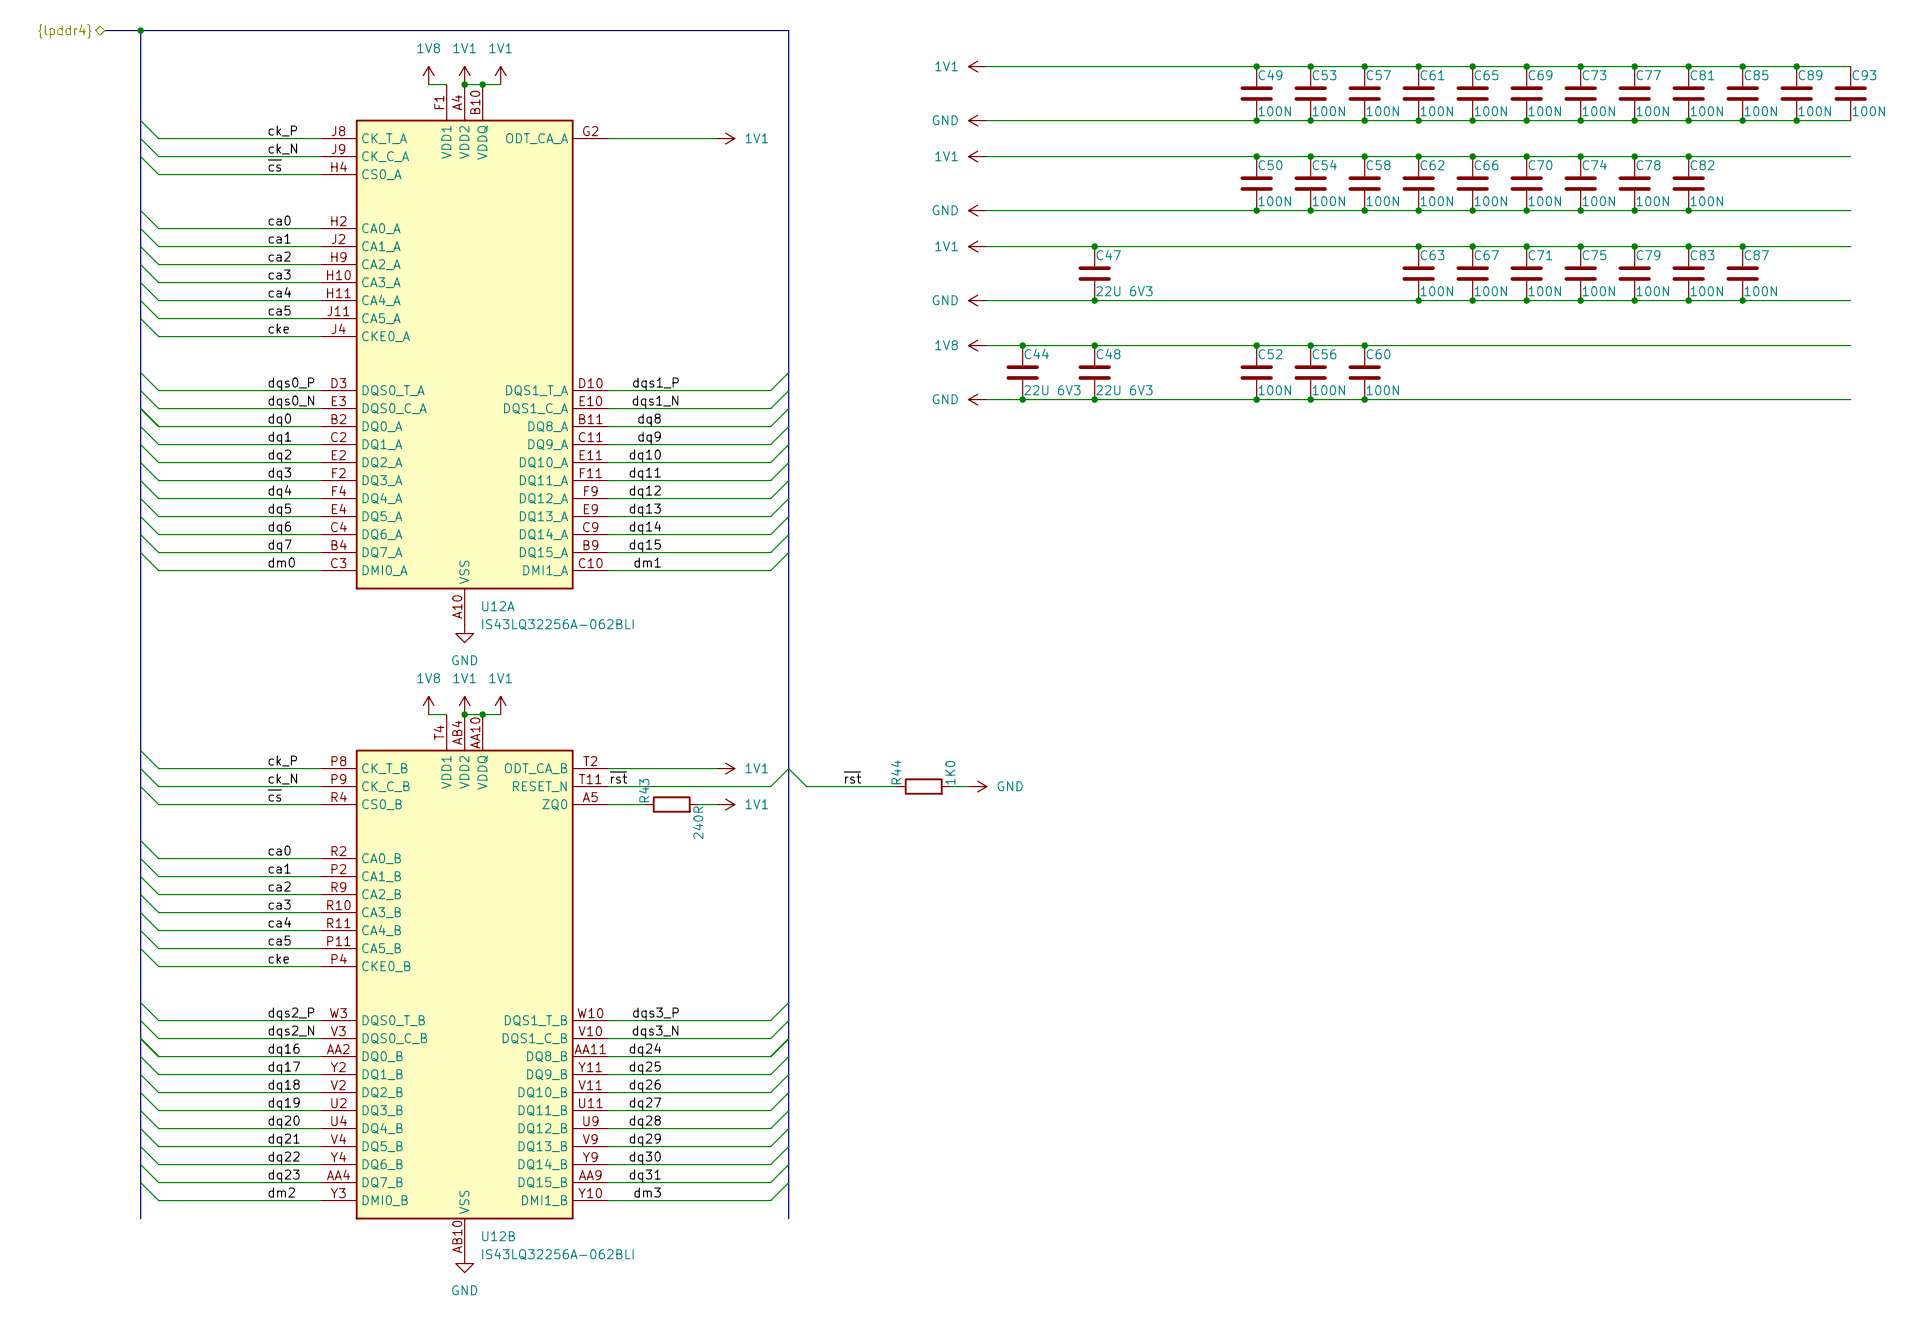
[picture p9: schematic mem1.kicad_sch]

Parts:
C44, C47, C48: 22U 6V3; C_0402_1005Metric
C49, C50, C52, C53, C54, C56, C57, C58, C60, C61, C62, C63, C65, C66, C67, C69, C70, C71, C73, C74, C75, C77, C78, C79, C81, C82, C83, C85, C87, C89, C93: 100N; C_0201_0603Metric
R43: 240R; R_0402_1005Metric
R44: 1K0; R_0402_1005Metric
U12: IS43LQ32256A-062BLI; BGA-200_10x14.5mm_Layout12x22_P0.8x0.65mm

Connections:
1V1: C47.1, C49.1, C50.1, C53.1, C54.1, C57.1, C58.1, C61.1, C62.1, C63.1, C65.1, C66.1, C67.1, C69.1, C70.1, C71.1, C73.1, C74.1, C75.1, C77.1, C78.1, C79.1, C81.1, C82.1, C83.1, C85.1, C87.1, C89.1, C93.1, R43.2, U12.A4 (VDD2), U12.A9 (VDD2), U12.AA3 (VDDQ), U12.AA5 (VDDQ), U12.AA8 (VDDQ), U12.AA10 (VDDQ), U12.AB4 (VDD2), U12.AB9 (VDD2), U12.B3 (VDDQ), U12.B5 (VDDQ), U12.B8 (VDDQ), U12.B10 (VDDQ), U12.D1 (VDDQ), U12.D5 (VDDQ), U12.D8 (VDDQ), U12.D12 (VDDQ), U12.F3 (VDDQ), U12.F5 (VDD2), U12.F8 (VDD2), U12.F10 (VDDQ), U12.G2 (ODT_CA_A), U12.H1 (VDD2), U12.H5 (VDD2), U12.H8 (VDD2), U12.H12 (VDD2), U12.K1 (VDD2), U12.K3 (VDD2), U12.K10 (VDD2), U12.K12 (VDD2), U12.N1 (VDD2), U12.N3 (VDD2), U12.N10 (VDD2), U12.N12 (VDD2), U12.R1 (VDD2), U12.R5 (VDD2), U12.R8 (VDD2), U12.R12 (VDD2), U12.T2 (ODT_CA_B), U12.U3 (VDDQ), U12.U5 (VDD2), U12.U8 (VDD2), U12.U10 (VDDQ), U12.W1 (VDDQ), U12.W5 (VDDQ), U12.W8 (VDDQ), U12.W12 (VDDQ); also elsewhere on the board
1V8: C44.1, C48.1, C52.1, C56.1, C60.1, U12.F1 (VDD1), U12.F12 (VDD1), U12.G4 (VDD1), U12.G9 (VDD1), U12.T4 (VDD1), U12.T9 (VDD1), U12.U1 (VDD1), U12.U12 (VDD1); also elsewhere on the board
/IOBANK 3/ca0: U12.H2 (CA0_A), U12.R2 (CA0_B); also elsewhere on the board
/IOBANK 3/ca1: U12.J2 (CA1_A), U12.P2 (CA1_B); also elsewhere on the board
/IOBANK 3/ca2: U12.H9 (CA2_A), U12.R9 (CA2_B); also elsewhere on the board
/IOBANK 3/ca3: U12.H10 (CA3_A), U12.R10 (CA3_B); also elsewhere on the board
/IOBANK 3/ca4: U12.H11 (CA4_A), U12.R11 (CA4_B); also elsewhere on the board
/IOBANK 3/ca5: U12.J11 (CA5_A), U12.P11 (CA5_B); also elsewhere on the board
/IOBANK 3/ck_N: U12.J9 (CK_C_A), U12.P9 (CK_C_B); also elsewhere on the board
/IOBANK 3/ck_P: U12.J8 (CK_T_A), U12.P8 (CK_T_B); also elsewhere on the board
/IOBANK 3/cke: U12.J4 (CKE0_A), U12.P4 (CKE0_B); also elsewhere on the board
/IOBANK 3/dm0: U12.C3 (DMI0_A); also elsewhere on the board
/IOBANK 3/dm1: U12.C10 (DMI1_A); also elsewhere on the board
/IOBANK 3/dm2: U12.Y3 (DMI0_B); also elsewhere on the board
/IOBANK 3/dm3: U12.Y10 (DMI1_B); also elsewhere on the board
/IOBANK 3/dq0: U12.B2 (DQ0_A); also elsewhere on the board
/IOBANK 3/dq1: U12.C2 (DQ1_A); also elsewhere on the board
/IOBANK 3/dq2: U12.E2 (DQ2_A); also elsewhere on the board
/IOBANK 3/dq3: U12.F2 (DQ3_A); also elsewhere on the board
/IOBANK 3/dq4: U12.F4 (DQ4_A); also elsewhere on the board
/IOBANK 3/dq5: U12.E4 (DQ5_A); also elsewhere on the board
/IOBANK 3/dq6: U12.C4 (DQ6_A); also elsewhere on the board
/IOBANK 3/dq7: U12.B4 (DQ7_A); also elsewhere on the board
/IOBANK 3/dq8: U12.B11 (DQ8_A); also elsewhere on the board
/IOBANK 3/dq9: U12.C11 (DQ9_A); also elsewhere on the board
/IOBANK 3/dq10: U12.E11 (DQ10_A); also elsewhere on the board
/IOBANK 3/dq11: U12.F11 (DQ11_A); also elsewhere on the board
/IOBANK 3/dq12: U12.F9 (DQ12_A); also elsewhere on the board
/IOBANK 3/dq13: U12.E9 (DQ13_A); also elsewhere on the board
/IOBANK 3/dq14: U12.C9 (DQ14_A); also elsewhere on the board
/IOBANK 3/dq15: U12.B9 (DQ15_A); also elsewhere on the board
/IOBANK 3/dq16: U12.AA2 (DQ0_B); also elsewhere on the board
/IOBANK 3/dq17: U12.Y2 (DQ1_B); also elsewhere on the board
/IOBANK 3/dq18: U12.V2 (DQ2_B); also elsewhere on the board
/IOBANK 3/dq19: U12.U2 (DQ3_B); also elsewhere on the board
/IOBANK 3/dq20: U12.U4 (DQ4_B); also elsewhere on the board
/IOBANK 3/dq21: U12.V4 (DQ5_B); also elsewhere on the board
/IOBANK 3/dq22: U12.Y4 (DQ6_B); also elsewhere on the board
/IOBANK 3/dq23: U12.AA4 (DQ7_B); also elsewhere on the board
/IOBANK 3/dq24: U12.AA11 (DQ8_B); also elsewhere on the board
/IOBANK 3/dq25: U12.Y11 (DQ9_B); also elsewhere on the board
/IOBANK 3/dq26: U12.V11 (DQ10_B); also elsewhere on the board
/IOBANK 3/dq27: U12.U11 (DQ11_B); also elsewhere on the board
/IOBANK 3/dq28: U12.U9 (DQ12_B); also elsewhere on the board
/IOBANK 3/dq29: U12.V9 (DQ13_B); also elsewhere on the board
/IOBANK 3/dq30: U12.Y9 (DQ14_B); also elsewhere on the board
/IOBANK 3/dq31: U12.AA9 (DQ15_B); also elsewhere on the board
/IOBANK 3/dqs0_N: U12.E3 (DQS0_C_A); also elsewhere on the board
/IOBANK 3/dqs0_P: U12.D3 (DQS0_T_A); also elsewhere on the board
/IOBANK 3/dqs1_N: U12.E10 (DQS1_C_A); also elsewhere on the board
/IOBANK 3/dqs1_P: U12.D10 (DQS1_T_A); also elsewhere on the board
/IOBANK 3/dqs2_N: U12.V3 (DQS0_C_B); also elsewhere on the board
/IOBANK 3/dqs2_P: U12.W3 (DQS0_T_B); also elsewhere on the board
/IOBANK 3/dqs3_N: U12.V10 (DQS1_C_B); also elsewhere on the board
/IOBANK 3/dqs3_P: U12.W10 (DQS1_T_B); also elsewhere on the board
/IOBANK 3/~cs: U12.H4 (CS0_A), U12.R4 (CS0_B); also elsewhere on the board
/IOBANK 3/~rst: R44.1, U12.T11 (RESET_N); also elsewhere on the board
GND: C44.2, C47.2, C48.2, C49.2, C50.2, C52.2, C53.2, C54.2, C56.2, C57.2, C58.2, C60.2, C61.2, C62.2, C63.2, C65.2, C66.2, C67.2, C69.2, C70.2, C71.2, C73.2, C74.2, C75.2, C77.2, C78.2, C79.2, C81.2, C82.2, C83.2, C85.2, C87.2, C89.2, C93.2, R44.2, U12.A3 (VSS), U12.A10 (VSS), U12.AB3 (VSS), U12.AB5 (VSS), U12.AB8 (VSS), U12.AB10 (VSS), U12.C1 (VSS), U12.C5 (VSS), U12.C8 (VSS), U12.C12 (VSS), U12.D2 (VSS), U12.D4 (VSS), U12.D9 (VSS), U12.D11 (VSS), U12.E1 (VSS), U12.E5 (VSS), U12.E8 (VSS), U12.E12 (VSS), U12.G1 (VSS), U12.G3 (VSS), U12.G5 (VSS), U12.G8 (VSS), U12.G10 (VSS), U12.G12 (VSS), U12.J1 (VSS), U12.J3 (VSS), U12.J10 (VSS), U12.J12 (VSS), U12.K2 (VSS), U12.K4 (VSS), U12.K9 (VSS), U12.K11 (VSS), U12.N2 (VSS), U12.N4 (VSS), U12.N9 (VSS), U12.N11 (VSS), U12.P1 (VSS), U12.P3 (VSS), U12.P10 (VSS), U12.P12 (VSS), U12.T1 (VSS), U12.T3 (VSS), U12.T5 (VSS), U12.T8 (VSS), U12.T10 (VSS), U12.T12 (VSS), U12.V1 (VSS), U12.V5 (VSS), U12.V8 (VSS), U12.V12 (VSS), U12.W2 (VSS), U12.W4 (VSS), U12.W9 (VSS), U12.W11 (VSS), U12.Y1 (VSS), U12.Y5 (VSS), U12.Y8 (VSS), U12.Y12 (VSS); also elsewhere on the board
unnamed: R43.1, U12.A5 (ZQ0)

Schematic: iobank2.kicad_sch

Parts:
R24: 240R; R_0402_1005Metric
U7: A5EB013B-B23B; VFBGA_b23b_mirror

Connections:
/Connectors/iob_2aB0: U7.DP70 (2A_B_IO12_IOB_DIFF_IO_2A_B18p)
/Connectors/iob_2aB1: U7.DN68 (2A_B_IO13_IOB_DIFF_IO_2A_B18n)
/Connectors/iob_2aB2: U7.DP68 (2A_B_IO16_IOB_DIFF_IO_2A_B16p)
/Connectors/iob_2aB3: U7.DN66 (2A_B_IO17_IOB_DIFF_IO_2A_B16n)
/Connectors/iob_2aB4: U7.DP66 (2A_B_IO18_IOB_DIFF_IO_2A_B15p)
/Connectors/iob_2aB5: U7.DN63 (2A_B_IO19_IOB_DIFF_IO_2A_B15n)
/Connectors/iob_2aB6: U7.DP61 (2A_B_IO20_IOB_DIFF_IO_2A_B14p)
/Connectors/iob_2aB7: U7.DN61 (2A_B_IO21_IOB_DIFF_IO_2A_B14n)
/Connectors/iob_2aB8: U7.DP60 (2A_B_IO22_IOB_DIFF_IO_2A_B13p)
/Connectors/iob_2aB9: U7.DN58 (2A_B_IO23_IOB_DIFF_IO_2A_B13n)
/Connectors/iob_2aB10: U7.DK56 (2A_B_IO10_IOB_DIFF_IO_2A_B19p)
/Connectors/iob_2aB11: U7.DJ56 (2A_B_IO11_IOB_DIFF_IO_2A_B19n)
/Connectors/iob_2aB12: U7.DK62 (2A_B_IO4_IOB_DIFF_IO_2A_B22p)
/Connectors/iob_2aB13: U7.DJ62 (2A_B_IO5_IOB_DIFF_IO_2A_B22n)
/Connectors/iob_2aB14: U7.DJ65 (2A_B_IO0_IOB_DIFF_IO_2A_B24p)
/Connectors/iob_2aB15: U7.DF65 (2A_B_IO1_IOB_DIFF_IO_2A_B24n)
/Connectors/iob_2aB16: U7.DD65 (2A_B_IO2_IOB_DIFF_IO_2A_B23p)
/Connectors/iob_2aB17: U7.DD62 (2A_B_IO3_IOB_DIFF_IO_2A_B23n)
/Connectors/iob_2aB18: U7.DJ59 (2A_B_IO6_IOB_DIFF_IO_2A_B21p)
/Connectors/iob_2aB19: U7.DF59 (2A_B_IO7_IOB_DIFF_IO_2A_B21n)
/Connectors/iob_2aB20: U7.DD59 (2A_B_IO8_IOB_DIFF_IO_2A_B20p)
/Connectors/iob_2aB21: U7.DD56 (2A_B_IO9_IOB_DIFF_IO_2A_B20n)
/Connectors/iob_2aB22: U7.DN73 (2A_B_IO14_IOB_DIFF_IO_2A_B17p)
/Connectors/iob_2aB23: U7.DN74 (2A_B_IO15_IOB_DIFF_IO_2A_B17n)
/Connectors/iob_2aB24: U7.DP50 (2A_B_IO40_PLL_2A_B_CLKOUT1)
/Connectors/iob_2aB25: U7.DN50 (2A_B_IO41_IOB_PLL_2A_B_CLKOUT1n_DIFF_IO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)
/IOBANK 2/rzq_b_2a: R24.1, U7.DP58 (2A_B_IO38_IOB_RZQ_B_2A_DIFF_IO_2A_B5p)
GND: R24.2; also elsewhere on the board

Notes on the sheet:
Pin Lane Pin-Index MIPI Soft CDR DJ65 0 0 D0P Yes DF65 0 1 D0N Yes DD65 0 2 D1P Yes DD62 0 3 D1N Yes DK62 0 4 CLKP No DK62 0 5 CLKN No DJ59 0 6 D2P No DF59 0 7 D2N No DD59 0 8 D3P No DD56 0 9 D3N No DK56 0 10 No DJ56 0 11 No DP70 1 12 D0P Yes DN68 1 13 D0N Yes DN73 1 14 D1P Yes DN74 1 15 D1N Yes DP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

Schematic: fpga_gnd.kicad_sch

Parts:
U7: A5EB013B-B23B; VFBGA_b23b_mirror

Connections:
/FPGA gnd/vcoresense_N: U7.BN44 (GNDSENSE); also elsewhere on the board
GND: U7.A3 (GND), U7.A5 (GND), U7.A17 (GND), U7.A28 (GND), U7.A41 (GND), U7.A53 (GND), U7.A63 (GND), U7.A73 (GND), U7.A74 (GND), U7.AA72 (GND), U7.AB27 (GND), U7.AB35 (GND), U7.AB42 (GND), U7.AB51 (GND), U7.AB59 (GND), U7.AB65 (GND), U7.AE4 (GND), U7.AE16 (GND), U7.AF2 (GND), U7.AF74 (GND), U7.AG34 (GND), U7.AG44 (GND), U7.AG49 (GND), U7.AG52 (GND), U7.AG54 (GND), U7.AG57 (GND), U7.AG60 (GND), U7.AH8 (GND), U7.AK64 (GND), U7.AK72 (GND), U7.AL23 (GND), U7.AL26 (GND), U7.AL40 (GND), U7.AL44 (GND), U7.AL49 (GND), U7.AL57 (GND), U7.AL60 (GND), U7.AM1 (GND), U7.AM75 (GND), U7.AN69 (GND), U7.AR29 (GND), U7.AR44 (GND), U7.AR46 (GND), U7.AR54 (GND), U7.AR60 (GND), U7.AT4 (GND), U7.AT16 (GND), U7.AV8 (GND), U7.AW26 (GND), U7.AW37 (GND), U7.AW44 (GND), U7.AW52 (GND), U7.AW54 (GND), U7.AW60 (GND), U7.AY64 (GND), U7.AY72 (GND), U7.B13 (GND), U7.B20 (GND), U7.B23 (GND), U7.B36 (GND), U7.B47 (GND), U7.B60 (GND), U7.B70 (GND), U7.B75 (GND), U7.BA2 (GND), U7.BA74 (GND), U7.BB23 (GND), U7.BB31 (GND), U7.BB40 (GND), U7.BB49 (GND), U7.BB57 (GND), U7.BB60 (GND), U7.BC69 (GND), U7.BE4 (GND), U7.BE16 (GND), U7.BF29 (GND), U7.BF37 (GND), U7.BF46 (GND), U7.BF54 (GND), U7.BF60 (GND), U7.BG1 (GND), U7.BG75 (GND), U7.BH8 (GND), U7.BJ34 (GND), U7.BJ44 (GND), U7.BJ52 (GND), U7.BJ57 (GND), U7.BK64 (GND), U7.BK72 (GND), U7.BM64 (GND), U7.BM67 (GND), U7.BM69 (GND), U7.BN23 (GND), U7.BN31 (GND), U7.BN40 (GND), U7.BN49 (GND), U7.BN57 (GND), U7.BR4 (GND), U7.BR16 (GND), U7.BT2 (GND), U7.BT74 (GND), U7.BU29 (GND), U7.BU37 (GND), U7.BU46 (GND), U7.BU54 (GND), U7.BU57 (GND), U7.BU60 (GND), U7.BV8 (GND), U7.BY64 (GND), U7.BY72 (GND), U7.C1 (GND), U7.C4 (GND), U7.C16 (GND), U7.C75 (GND), U7.CA26 (GND), U7.CA34 (GND), U7.CA44 (GND), U7.CA52 (GND), U7.CA60 (GND), U7.CB1 (GND), U7.CB75 (GND), U7.CC69 (GND), U7.CD31 (GND), U7.CD40 (GND), U7.CD49 (GND), U7.CD57 (GND), U7.CE4 (GND), U7.CE16 (GND), U7.CG29 (GND), U7.CG37 (GND), U7.CG46 (GND), U7.CG54 (GND), U7.CH8 (GND), U7.CK64 (GND), U7.CK72 (GND), U7.CL23 (GND), U7.CL26 (GND), U7.CL34 (GND), U7.CL44 (GND), U7.CL52 (GND), U7.CL60 (GND), U7.CM2 (GND), U7.CM74 (GND), U7.CN69 (GND), U7.CR4 (GND), U7.CR16 (GND), U7.CT31 (GND), U7.CT40 (GND), U7.CT49 (GND), U7.CT57 (GND), U7.CU1 (GND), U7.CU74 (GND), U7.CU75 (GND), U7.CV8 (GND), U7.CW29 (GND), U7.CW37 (GND), U7.CW46 (GND), U7.CW54 (GND), U7.CY64 (GND), U7.CY72 (GND), U7.D72 (GND), U7.DE2 (GND), U7.DE74 (GND), U7.DF9 (GND), U7.DF18 (GND), U7.DF24 (GND), U7.DF32 (GND), U7.DF39 (GND), U7.DF48 (GND), U7.DF56 (GND), U7.DF62 (GND), U7.DG72 (GND), U7.DK3 (GND), U7.DK12 (GND), U7.DK21 (GND), U7.DK27 (GND), U7.DK35 (GND), U7.DK42 (GND), U7.DK51 (GND), U7.DK59 (GND), U7.DK65 (GND), U7.DL72 (GND), U7.DM1 (GND), U7.DM74 (GND), U7.DM75 (GND), U7.DN1 (GND), U7.DN13 (GND), U7.DN23 (GND), U7.DN36 (GND), U7.DN47 (GND), U7.DN60 (GND), U7.DN70 (GND), U7.DN75 (GND), U7.DP2 (GND), U7.DP3 (GND), U7.DP17 (GND), U7.DP28 (GND), U7.DP41 (GND), U7.DP53 (GND), U7.DP63 (GND), U7.DP73 (GND), U7.DP74 (GND), U7.E27 (GND), U7.E35 (GND), U7.E42 (GND), U7.E51 (GND), U7.E59 (GND), U7.E65 (GND), U7.F1 (GND), U7.H8 (GND), U7.J24 (GND), U7.J32 (GND), U7.J39 (GND), U7.J48 (GND), U7.J56 (GND), U7.J62 (GND), U7.K72 (GND), U7.L2 (GND), U7.L74 (GND), U7.R4 (GND), U7.R16 (GND), U7.U1 (GND), U7.U75 (GND), U7.V8 (GND), U7.W27 (GND), U7.W35 (GND), U7.W42 (GND), U7.W51 (GND), U7.W59 (GND), U7.W65 (GND); also elsewhere on the board

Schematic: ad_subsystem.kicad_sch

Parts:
C1, C2, C4: C; C_0402_1005Metric
C3: 1n; C_0402_1005Metric
R3: 10; R_0402_1005Metric
U3: CD4051B; TSSOP-16_4.4x5mm_P0.65mm
U4: AD8603; TSOT-23-5
U5: ADS7056IRUGR; ads7056

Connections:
3V3_analog: C1.1, C2.1, C4.1, U3.6 (INH), U3.16 (VDD), U4.5 (V+), U5.4 (DVDD), U5.6 (AVDD); also elsewhere on the board
/Connectors/iob6b5: U3.9 (C); also elsewhere on the board
/Connectors/iob6f3: U5.2 (SDO); also elsewhere on the board
/Connectors/iob6f6: U5.1 (~CS); also elsewhere on the board
/Connectors/iob6f7: U5.3 (SCLK); also elsewhere on the board
/Connectors/iob6f8: U3.11 (A); also elsewhere on the board
/Connectors/iob6f9: U3.10 (B); also elsewhere on the board
/ad_ch0: U3.13 (X0); also elsewhere on the board
/ad_ch1: U3.14 (X1); also elsewhere on the board
/ad_ch2: U3.15 (X2); also elsewhere on the board
/ad_ch3: U3.12 (X3); also elsewhere on the board
/ad_ch4: U3.1 (X4); also elsewhere on the board
/ad_ch5: U3.5 (X5); also elsewhere on the board
/ad_ch6: U3.2 (X6); also elsewhere on the board
/ad_ch7: U3.4 (X7); also elsewhere on the board
GND: C1.2, C2.2, C3.2, C4.2, U3.7 (VEE), U3.8 (VSS), U4.2 (V-), U5.5 (GND), U5.8 (AINM); also elsewhere on the board
unnamed: U3.3 (X), U4.3 (+)
unnamed: R3.1, U4.1, U4.4 (-)
unnamed: C3.1, R3.2, U5.7 (AINP)

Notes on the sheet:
does it need series termination?

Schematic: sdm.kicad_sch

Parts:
D1, D2: 150060RS75000; LED_0603_1608Metric
R4, R7, R45: 4K7; R_0402_1005Metric
R8, R9, R10, R11, R12, R14, R15, R19, R20, R21: 10K; R_0402_1005Metric
R16, R17: 680R; R_0402_1005Metric
R18: 2K0; R_0402_1005Metric
R22: 1K0; R_0402_1005Metric
U2: MX25U25645G; MX25U25645G_CSP24_6x8mm_P1.0mm
U7: A5EB013B-B23B; VFBGA_b23b_mirror

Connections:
1V8: R7.1, R8.1, R9.1, R10.1, R11.1, R12.1, R14.1, R15.1, R19.1, R20.1, R21.1, U2.B4 (VCC); also elsewhere on the board
/SDM/conf_done: R10.2, U7.DA74 (SDM_SDM_IO16_PWRMGT_SDA)
/SDM/init_done: R9.2, U7.BK67 (SDM_SDM_IO0_PWRMGT_SCL_PWRMGT_ALERT)
/SDM/msel1: R45.1, U7.CN67 (SDM_SDM_IO7_AS_nCSO2_MSEL1)
/SDM/msel2: R4.1, U7.CN71 (SDM_SDM_IO9_AS_nCSO1_MSEL2_PWRMGT_ALERT); also elsewhere on the board
/SDM/qspi_CLK: U2.B2 (SCLK), U7.CY69 (SDM_SDM_IO2_AVSTx8_DATA0_AS_CLK)
/SDM/qspi_D0: U2.D3 (SI/SIO0), U7.CN64 (SDM_SDM_IO4_AVSTx8_DATA1_AS_DATA0)
/SDM/qspi_D1: U2.D2 (SO/SIO1), U7.CK67 (SDM_SDM_IO1_AVSTx8_DATA2_AS_DATA1)
/SDM/qspi_D2: R12.2, U2.C4 (WP#/SIO2), U7.DC74 (SDM_SDM_IO3_AVSTx8_DATA3_AS_DATA2)
/SDM/qspi_D3: R14.2, U2.D4 (NC/SIO3), U7.DC75 (SDM_SDM_IO6_AVSTx8_DATA4_AS_DATA3)
/SDM/~nconfig: R8.2, U7.BK71 (SDM_nCONFIG)
/SDM/~nstatus: R11.2, U7.BM71 (SDM_nSTATUS)
/SDM/~qspi_CS: R7.2, U2.C2 (CS#), U7.BY71 (SDM_SDM_IO5_AS_nCSO0_MSEL0)
/SDM/~qspi_rst_n: R15.2, U2.A4 (RESET#), U7.CY71 (SDM_SDM_IO15_AVSTx8_DATA6_AS_nRST)
/tck: R22.2, U7.CC64 (SDM_TCK); also elsewhere on the board
/tdi: R19.2, U7.CC67 (SDM_TDI); also elsewhere on the board
/tdo: R20.2, U7.BY67 (SDM_TDO); also elsewhere on the board
/tms: R21.2, U7.CY67 (SDM_TMS); also elsewhere on the board
/~hpscold_rstn: U7.CK69 (SDM_SDM_IO10_AVSTx8_DATA7)
GND: D1.1 (K), D2.1 (K), R4.2, R18.2, R22.1, R45.2, U2.B3 (GND), U7.BW74 (SDM_VSIGN_0), U7.BW75 (SDM_VSIGP_0), U7.CF74 (SDM_VREFN_ADC), U7.CF75 (SDM_VREFP_ADC), U7.CJ74 (SDM_VSIGP_1), U7.CJ75 (SDM_VSIGN_1); also elsewhere on the board
unnamed: D1.2 (A), R16.1
unnamed: D2.2 (A), R17.1
unnamed: R18.1, U7.DH75 (SDM_RREF_SDM)
fpga_led: R17.2; also elsewhere on the board
pg_led: R16.2; also elsewhere on the board
sdm_clk25: U7.DB72 (SDM_OSC_CLK_1); also elsewhere on the board

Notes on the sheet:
msel0
SDM_IO13 unused
D2: user LED on FPGA IO CE6 (bank 6B, 3.3 V) - see IOBANK6ab
D1: power good - regulator PGs wired-AND (ps1) -> U42 ch4 (root) -> 3.3 V pg_led

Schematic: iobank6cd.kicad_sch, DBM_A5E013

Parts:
U7: A5EB013B-B23B; VFBGA_b23b_mirror

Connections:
/Connectors/iob6c0: U7.H6 (6C_IO_HVIO_6C_17_TXCLK17_Data_Ctrl17)
/Connectors/iob6c1: U7.H11 (6C_IO_HVIO_6C_14_TXCLK14_Data_Ctrl14)
/Connectors/iob6c2: U7.H14 (6C_IO_HVIO_6C_12_SOURCE_SYNC_CLK2_TXCLK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)
/Connectors/iob6c3: U7.B17 (6C_IO_HVIO_6C_4_TXCLK4_Data_Ctrl4)
/Connectors/iob6c4: U7.R14 (6C_IO_HVIO_6C_18_TXCLK18_Data_Ctrl18)
/Connectors/iob6c5: U7.R19 (6C_IO_HVIO_6C_3_TXCLK3_Data_Ctrl3)
/Connectors/iob6c6: U7.H19 (6C_IO_HVIO_6C_6_TXCLK6_Data_Ctrl6)
/Connectors/iob6c7: U7.V19 (6C_IO_HVIO_6C_11_SOURCE_SYNC_CLK1_TXCLK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)
/Connectors/iob6d0: U7.Y2 (6D_IO_HVIO_6D_5_TXCLK5_Data_Ctrl5); also elsewhere on the board
/Connectors/iob6d1: U7.Y1 (6D_IO_HVIO_6D_2_TXCLK2_Data_Ctrl2); also elsewhere on the board
/Connectors/iob6d2: U7.U2 (6D_IO_HVIO_6D_1_TXCLK1_Data_Ctrl1); also elsewhere on the board
/Connectors/iob6d3: U7.P2 (6D_IO_HVIO_6D_4_TXCLK4_Data_Ctrl4); also elsewhere on the board
/Connectors/iob6d4: U7.P1 (6D_IO_HVIO_6D_3_TXCLK3_Data_Ctrl3); also elsewhere on the board
/Connectors/iob6d5: U7.L1 (6D_IO_HVIO_6D_6_TXCLK6_Data_Ctrl6)
/Connectors/iob6d6: U7.F2 (6D_IO_HVIO_6D_7_TXCLK7_Data_Ctrl7)
/Connectors/iob6d7: U7.C2 (6D_IO_HVIO_6D_9_PLLREFCLK1_TXCLK9_RXCLK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)
/Connectors/iob6d8: U7.C8 (6D_IO_HVIO_6D_10_PLLREFCLK2_TXCLK10_RXC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)
/Connectors/iob6d9: U7.C6 (6D_IO_HVIO_6D_8_TXCLK8_Data_Ctrl8)
/Connectors/iob6d10: U7.C11 (6D_IO_HVIO_6D_12_SOURCE_SYNC_CLK2_TXCLK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)
/Connectors/iob6d11: U7.C14 (6D_IO_HVIO_6D_13_TXCLK13_Data_Ctrl13)
/Connectors/iob6d12: U7.B3 (6D_IO_HVIO_6D_11_SOURCE_SYNC_CLK1_TXCLK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)
/Connectors/iob6d13: U7.B5 (6D_IO_HVIO_6D_14_TXCLK14_Data_Ctrl14)
/Connectors/iob6d14: U7.B10 (6D_IO_HVIO_6D_16_TXCLK16_Data_Ctrl16)
/Connectors/iob6d15: U7.A10 (6D_IO_HVIO_6D_15_TXCLK15_Data_Ctrl15)
/Connectors/iob6d16: U7.A13 (6D_IO_HVIO_6D_17_TXCLK17_Data_Ctrl17)
/Connectors/iob6d18: U7.B15 (6D_IO_HVIO_6D_20_TXCLK20_Data_Ctrl20)
/Connectors/iob6d19: U7.A15 (6D_IO_HVIO_6D_19_TXCLK19_Data_Ctrl19)

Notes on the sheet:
VCCIO_6C : 2.5V or 3.3V

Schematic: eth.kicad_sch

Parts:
C18, C21, C24, C27: 22U 6V3; C_0402_1005Metric
C19, C20, C22, C23, C25, C26, C28, C29, C30, C31, C32: 100N; C_0402_1005Metric
C251, C252: 27p; C_0402_1005Metric
C255: 100n; C_0402_1005Metric
J9: RJ45_RB1-125B8G1A; RJ45_UDE_RB1-125B8G1A
R29, R30, R32, R34, R36, R37, R39, R40: 4K7; R_0402_1005Metric
R31, R33, R35, R38: 1K0; R_0402_1005Metric
R41: 12K1; R_0402_1005Metric
R247: 10k; R_0402_1005Metric
R250: 330R; R_0402_1005Metric
U10: KSZ9031RNXCA; QFN-48-1EP_7x7mm_P0.5mm_EP5.15x5.15mm
Y3: 25MHz; Crystal_SMD_3225-4Pin_3.2x2.5mm

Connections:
1V2: C18.1, C19.1, C20.1, C21.1, C22.1, C23.1, C27.1, C28.1, C29.1, C30.1, C31.1, C32.1, U10.4 (AVDDL), U10.9 (AVDDL), U10.14 (DVDDL), U10.18 (DVDDL), U10.23 (DVDDL), U10.26 (DVDDL), U10.30 (DVDDL), U10.39 (DVDDL), U10.44 (AVDDL_PLL); also elsewhere on the board
1V8: R29.1, R30.1, R32.1, R34.1, R36.1, R37.1, R39.1, R40.1, R247.2, U10.16 (DVDDH), U10.34 (DVDDH), U10.40 (DVDDH); also elsewhere on the board
3V3: C24.1, C25.1, C26.1, R250.2, U10.1 (AVDDH), U10.12 (AVDDH); also elsewhere on the board
/Connectors/phy_led1: R35.1, U10.15 (LED2/PHYAD1)
/Connectors/txrxa_N: J9.R3 (TD1-), U10.3 (TXRXM_A)
/Connectors/txrxa_P: J9.R2 (TD1+), U10.2 (TXRXP_A)
/Connectors/txrxb_N: J9.R5 (TD2-), U10.6 (TXRXM_B)
/Connectors/txrxb_P: J9.R4 (TD2+), U10.5 (TXRXP_B)
/Connectors/txrxc_N: J9.R7 (TD3-), U10.8 (TXRXM_C)
/Connectors/txrxc_P: J9.R6 (TD3+), U10.7 (TXRXP_C)
/Connectors/txrxd_N: J9.R9 (TD4-), U10.11 (TXRXM_D)
/Connectors/txrxd_P: J9.R8 (TD4+), U10.10 (TXRXP_D)
/Ethernet Phy/eth_led_mode: R29.2, U10.41 (CLK125_NDO/LED_MODE)
/HPS/eth_gtx_clk: U10.24 (GTX_CLK); also elsewhere on the board
/HPS/eth_mdc: R40.2, U10.36 (MDC); also elsewhere on the board
/HPS/eth_mdio: R36.2, U10.37 (MDIO); also elsewhere on the board
/HPS/eth_rx_clk: R33.1, U10.35 (RX_CLK/PHYAD2); also elsewhere on the board
/HPS/eth_rx_dv: R31.1, U10.33 (RX_DV/CLK125_EN); also elsewhere on the board
/HPS/eth_rxd0: R39.2, U10.32 (RXD0/MODE0); also elsewhere on the board
/HPS/eth_rxd1: R37.2, U10.31 (RXD1/MODE1); also elsewhere on the board
/HPS/eth_rxd2: R34.2, U10.28 (RXD2/MODE2); also elsewhere on the board
/HPS/eth_rxd3: R32.2, U10.27 (RXD3/MODE3); also elsewhere on the board
/HPS/eth_tx_en: U10.25 (TX_EN); also elsewhere on the board
/HPS/eth_txd0: U10.19 (TXD0); also elsewhere on the board
/HPS/eth_txd1: U10.20 (TXD1); also elsewhere on the board
/HPS/eth_txd2: U10.21 (TXD2); also elsewhere on the board
/HPS/eth_txd3: U10.22 (TXD3); also elsewhere on the board
/HPS/~eth_int: R30.2, U10.38 (INT_N/PME_N2); also elsewhere on the board
GND: C18.2, C19.2, C20.2, C21.2, C22.2, C23.2, C24.2, C25.2, C26.2, C27.2, C28.2, C29.2, C30.2, C31.2, C32.2, C251.2, C252.2, C255.2, J9.R10 (GND), J9.SH, R31.2, R33.2, R35.2, R38.2, R41.2, U10.29 (VSS), U10.49 (PAD_GND), Y3.2 (GND), Y3.4 (GND); also elsewhere on the board
unnamed: C255.1, J9.R1 (CT)
unnamed: J9.L3, R250.1
unnamed: R41.1, U10.48 (ISET)
unnamed: C251.1, U10.46 (XI), Y3.1
unnamed: C252.1, U10.45 (XO), Y3.3 (2)
eth_led1_n: R38.1, U10.17 (LED1/PHAD0/PME_N1); also elsewhere on the board
eth_led_g_n: J9.L4; also elsewhere on the board
eth_rst_n: R247.1, U10.42 (RESET_N); also elsewhere on the board

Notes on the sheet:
25 MHz +/-50 ppm crystal (KSZ9031). C251/C252 = 2*(CL - Cstray): 27p for CL=18pF; adjust to the crystal chosen.
SODIMM P1 not populated: {phy} bus to P1 is a leftover
Green LED L3(+)/L4 <- PHY LED1 link/act via U42 ch3 (1.8->3.3 V). Yellow L1/L2 unused. Check +/- vs datasheet p.7
RESET_N driven by HPS GPIO1_IO18 (K71); pull-up keeps PHY in reset-released state when HPS is in reset
J9: CT = common PHY-side centre tap (all 4 pairs) -> 100n to GND. GND/SH -> GND.

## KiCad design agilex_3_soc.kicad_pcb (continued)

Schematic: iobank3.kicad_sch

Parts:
R23, R248: 240R; R_0402_1005Metric
U7: A5EB013B-B23B; VFBGA_b23b_mirror

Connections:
/IOBANK 3/ca0: U7.B66 (3A_B_IO24_IOB_DIFF_IO_3A_B12p); also elsewhere on the board
/IOBANK 3/ca1: U7.A68 (3A_B_IO25_IOB_DIFF_IO_3A_B12n); also elsewhere on the board
/IOBANK 3/ca2: U7.B68 (3A_B_IO26_IOB_DIFF_IO_3A_B11p); also elsewhere on the board
/IOBANK 3/ca3: U7.A70 (3A_B_IO27_IOB_DIFF_IO_3A_B11n); also elsewhere on the board
/IOBANK 3/ca4: U7.B63 (3A_B_IO28_IOB_DIFF_IO_3A_B10p); also elsewhere on the board
/IOBANK 3/ca5: U7.A66 (3A_B_IO29_IOB_DIFF_IO_3A_B10n); also elsewhere on the board
/IOBANK 3/ck_N: U7.G42 (3A_B_IO43_IOB_DIFF_IO_3A_B3n); also elsewhere on the board
/IOBANK 3/ck_P: U7.J42 (3A_B_IO42_IOB_DIFF_IO_3A_B3p); also elsewhere on the board
/IOBANK 3/cke: U7.A61 (3A_B_IO30_IOB); also elsewhere on the board
/IOBANK 3/dm0: U7.J59 (3A_B_IO6_IOB_DIFF_IO_3A_B21p); also elsewhere on the board
/IOBANK 3/dm1: U7.T59 (3A_B_IO18_IOB_DIFF_IO_3A_B15p); also elsewhere on the board
/IOBANK 3/dm2: U7.J27 (3A_T_IO78_IOB_DIFF_IO_3A_T9p); also elsewhere on the board
/IOBANK 3/dm3: U7.A25 (3A_T_IO90_IOB_DIFF_IO_3A_T3p); also elsewhere on the board
/IOBANK 3/dq0: U7.T62 (3A_B_IO2_IOB_DIFF_IO_3A_B23p); also elsewhere on the board
/IOBANK 3/dq1: U7.T56 (3A_B_IO8_IOB_DIFF_IO_3A_B20p); also elsewhere on the board
/IOBANK 3/dq2: U7.G56 (3A_B_IO10_IOB_DIFF_IO_3A_B19p); also elsewhere on the board
/IOBANK 3/dq3: U7.E56 (3A_B_IO11_IOB_DIFF_IO_3A_B19n); also elsewhere on the board
/IOBANK 3/dq4: U7.G65 (3A_B_IO1_IOB_DIFF_IO_3A_B24n); also elsewhere on the board
/IOBANK 3/dq5: U7.J65 (3A_B_IO0_IOB_DIFF_IO_3A_B24p); also elsewhere on the board
/IOBANK 3/dq6: U7.M56 (3A_B_IO9_IOB_DIFF_IO_3A_B20n); also elsewhere on the board
/IOBANK 3/dq7: U7.M62 (3A_B_IO3_IOB_DIFF_IO_3A_B23n); also elsewhere on the board
/IOBANK 3/dq8: U7.W62 (3A_B_IO13_IOB_DIFF_IO_3A_B18n); also elsewhere on the board
/IOBANK 3/dq9: U7.M65 (3A_B_IO15_IOB_DIFF_IO_3A_B17n); also elsewhere on the board
/IOBANK 3/dq10: U7.M51 (3A_B_IO23_IOB_DIFF_IO_3A_B13n); also elsewhere on the board
/IOBANK 3/dq11: U7.T51 (3A_B_IO22_IOB_DIFF_IO_3A_B13p); also elsewhere on the board
/IOBANK 3/dq12: U7.AB48 (3A_B_IO20_IOB_DIFF_IO_3A_B14p); also elsewhere on the board
/IOBANK 3/dq13: U7.W48 (3A_B_IO21_IOB_DIFF_IO_3A_B14n); also elsewhere on the board
/IOBANK 3/dq14: U7.T65 (3A_B_IO14_IOB_DIFF_IO_3A_B17p); also elsewhere on the board
/IOBANK 3/dq15: U7.AB62 (3A_B_IO12_IOB_DIFF_IO_3A_B18p); also elsewhere on the board
/IOBANK 3/dq16: U7.G24 (3A_T_IO82_IOB_DIFF_IO_3A_T7p); also elsewhere on the board
/IOBANK 3/dq17: U7.E24 (3A_T_IO83_IOB_DIFF_IO_3A_T7n); also elsewhere on the board
/IOBANK 3/dq18: U7.J35 (3A_T_IO72_IOB_DIFF_IO_3A_T12p); also elsewhere on the board
/IOBANK 3/dq19: U7.T32 (3A_T_IO74_IOB_DIFF_IO_3A_T11p); also elsewhere on the board
/IOBANK 3/dq20: U7.M32 (3A_T_IO75_IOB_DIFF_IO_3A_T11n); also elsewhere on the board
/IOBANK 3/dq21: U7.T24 (3A_T_IO80_IOB_DIFF_IO_3A_T8p); also elsewhere on the board
/IOBANK 3/dq22: U7.G35 (3A_T_IO73_IOB_DIFF_IO_3A_T12n); also elsewhere on the board
/IOBANK 3/dq23: U7.M24 (3A_T_IO81_IOB_DIFF_IO_3A_T8n); also elsewhere on the board
/IOBANK 3/dq24: U7.A22 (3A_T_IO92_IOB_DIFF_IO_3A_T2p); also elsewhere on the board
/IOBANK 3/dq25: U7.A23 (3A_T_IO93_IOB_DIFF_IO_3A_T2n); also elsewhere on the board
/IOBANK 3/dq26: U7.A33 (3A_T_IO87_IOB_DIFF_IO_3A_T5n); also elsewhere on the board
/IOBANK 3/dq27: U7.B33 (3A_T_IO84_IOB_DIFF_IO_3A_T6p); also elsewhere on the board
/IOBANK 3/dq28: U7.B30 (3A_T_IO86_IOB_DIFF_IO_3A_T5p); also elsewhere on the board
/IOBANK 3/dq29: U7.A36 (3A_T_IO85_IOB_DIFF_IO_3A_T6n); also elsewhere on the board
/IOBANK 3/dq30: U7.A20 (3A_T_IO95_IOB_DIFF_IO_3A_T1n); also elsewhere on the board
/IOBANK 3/dq31: U7.B22 (3A_T_IO94_IOB_DIFF_IO_3A_T1p); also elsewhere on the board
/IOBANK 3/dqs0_N: U7.A30 (3A_T_IO89_IOB_DIFF_IO_3A_T4n); also elsewhere on the board
/IOBANK 3/dqs0_P: U7.B28 (3A_T_IO88_IOB_DIFF_IO_3A_T4p); also elsewhere on the board
/IOBANK 3/dqs1_N: U7.E32 (3A_T_IO77_IOB_DIFF_IO_3A_T10n); also elsewhere on the board
/IOBANK 3/dqs1_P: U7.G32 (3A_T_IO76_IOB_DIFF_IO_3A_T10p); also elsewhere on the board
/IOBANK 3/dqs2_N: U7.W56 (3A_B_IO17_IOB_DIFF_IO_3A_B16n); also elsewhere on the board
/IOBANK 3/dqs2_P: U7.AB56 (3A_B_IO16_IOB_DIFF_IO_3A_B16p); also elsewhere on the board
/IOBANK 3/dqs3_N: U7.E62 (3A_B_IO5_IOB_DIFF_IO_3A_B22n); also elsewhere on the board
/IOBANK 3/dqs3_P: U7.G62 (3A_B_IO4_IOB_DIFF_IO_3A_B22p); also elsewhere on the board
/IOBANK 3/hbclkn: U7.W32 (3A_T_IO65_IOB_PLL_3A_T_CLKOUT1n_DIFF_IO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)
/IOBANK 3/hbclkp: U7.AB32 (3A_T_IO64_PLL_3A_T_CLKOUT1p)
/IOBANK 3/hbcs0n: U7.A38 (3A_T_IO58_IOB_CLK_T_3A_0p_DIFF_IO_3A_T1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)
/IOBANK 3/hbcs1n: U7.B38 (3A_T_IO59_IOB_CLK_T_3A_0n_DIFF_IO_3A_T1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)
/IOBANK 3/hbd0: U7.A55 (3A_T_IO51_IOB_DIFF_IO_3A_T23n)
/IOBANK 3/hbd1: U7.B41 (3A_T_IO56_IOB_DIFF_IO_3A_T20p)
/IOBANK 3/hbd2: U7.A50 (3A_T_IO48_IOB_DIFF_IO_3A_T24p)
/IOBANK 3/hbd3: U7.B53 (3A_T_IO50_IOB_DIFF_IO_3A_T23p)
/IOBANK 3/hbd4: U7.B43 (3A_T_IO54_PLL_3A_T_CLKOUT0p)
/IOBANK 3/hbd5: U7.B50 (3A_T_IO49_IOB_DIFF_IO_3A_T24n)
/IOBANK 3/hbd6: U7.A43 (3A_T_IO57_IOB_DIFF_IO_3A_T20n)
/IOBANK 3/hbd7: U7.A45 (3A_T_IO55_IOB_PLL_3A_T_CLKOUT0n_DIFF_IO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)
/IOBANK 3/hbrstn: U7.A47 (3A_T_IO53_IOB_DIFF_IO_3A_T22n)
/IOBANK 3/hbrwds: U7.B45 (3A_T_IO52_IOB_DIFF_IO_3A_T22p)
/IOBANK 3/rzq_b_3a: R23.1, U7.T48 (3A_B_IO38_IOB_RZQ_B_3A_DIFF_IO_3A_B5p)
/IOBANK 3/rzq_t_3a: R248.2, U7.M42 (3A_T_IO62_IOB_RZQ_T_3A_DIFF_IO_3A_T17p)
/IOBANK 3/~cs: U7.B58 (3A_B_IO32_IOB_DIFF_IO_3A_B8p); also elsewhere on the board
/IOBANK 3/~rst: U7.M48 (3A_B_IO39_IOB_DIFF_IO_3A_B5n); also elsewhere on the board
/iob3A_refclk_N: U7.A58 (3A_B_IO35_IOB_CLK_B_3A_0n_DIFF_IO_3A_B7n); also elsewhere on the board
/iob3A_refclk_P: U7.B55 (3A_B_IO34_IOB_CLK_B_3A_0p_DIFF_IO_3A_B7p); also elsewhere on the board
GND: R23.2, R248.1; also elsewhere on the board

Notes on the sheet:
DQS-Pin
DQ-Pin
SWIZZLING ON BANK 3A BYTE_SWIZZLE_CH0=3 2 X X X X 1 0; PIN_SWIZZLE_CH0_DQS0 = 3 4 1 2 6 0 7 5; PIN_SWIZZLE_CH0_DQS1 = 12 11 14 13 15 9 10 8; PIN_SWIZZLE_CH0_DQS2 = 19 20 17 18 23 22 21 16; PIN_SWIZZLE_CH0_DQS3 = 31 30 24 25 29 28 27 26;
LPDDR4 settings 133.333MHz ref clock = 111.111MHz

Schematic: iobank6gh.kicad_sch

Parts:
U7: A5EB013B-B23B; VFBGA_b23b_mirror

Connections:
/Connectors/iob6h0: U7.BL2 (6H_IO_HVIO_6H_1_TXCLK1_Data_Ctrl1); also elsewhere on the board
/Connectors/iob6h1: U7.BL1 (6H_IO_HVIO_6H_2_TXCLK2_Data_Ctrl2); also elsewhere on the board
/Connectors/iob6h2: U7.BH4 (6H_IO_HVIO_6H_3_TXCLK3_Data_Ctrl3)
/Connectors/iob6h3: U7.BG2 (6H_IO_HVIO_6H_4_TXCLK4_Data_Ctrl4); also elsewhere on the board
/Connectors/iob6h4: U7.BD1 (6H_IO_HVIO_6H_6_TXCLK6_Data_Ctrl6); also elsewhere on the board
/Connectors/iob6h5: U7.BD2 (6H_IO_HVIO_6H_5_TXCLK5_Data_Ctrl5); also elsewhere on the board
/Connectors/iob6h6: U7.BH6 (6H_IO_HVIO_6H_7_TXCLK7_Data_Ctrl7)
/Connectors/iob6h7: U7.BA1 (6H_IO_HVIO_6H_8_TXCLK8_Data_Ctrl8); also elsewhere on the board
/Connectors/iob6h8: U7.BE8 (6H_IO_HVIO_6H_17_TXCLK17_Data_Ctrl17)
/Connectors/iob6h9: U7.BE6 (6H_IO_HVIO_6H_14_TXCLK14_Data_Ctrl14)
/Connectors/iob6h10: U7.AU1 (6H_IO_HVIO_6H_10_PLLREFCLK2_TXCLK10_RXC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); also elsewhere on the board
/Connectors/iob6h11: U7.AU2 (6H_IO_HVIO_6H_9_PLLREFCLK1_TXCLK9_RXCLK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); also elsewhere on the board
/Connectors/iob6h12: U7.AP1 (6H_IO_HVIO_6H_11_SOURCE_SYNC_CLK1_TXCLK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); also elsewhere on the board
/Connectors/iob6h13: U7.AP2 (6H_IO_HVIO_6H_12_SOURCE_SYNC_CLK2_TXCLK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); also elsewhere on the board
/Connectors/iob6h14: U7.AM2 (6H_IO_HVIO_6H_13_TXCLK13_Data_Ctrl13); also elsewhere on the board
/Connectors/iob6h15: U7.AJ1 (6H_IO_HVIO_6H_16_TXCLK16_Data_Ctrl16); also elsewhere on the board
/Connectors/iob6h16: U7.AJ2 (6H_IO_HVIO_6H_15_TXCLK15_Data_Ctrl15); also elsewhere on the board
/Connectors/iob6h17: U7.AF1 (6H_IO_HVIO_6H_18_TXCLK18_Data_Ctrl18); also elsewhere on the board
/Connectors/iob6h18: U7.AC2 (6H_IO_HVIO_6H_19_TXCLK19_Data_Ctrl19); also elsewhere on the board
/Connectors/iob6h19: U7.AC1 (6H_IO_HVIO_6H_20_TXCLK20_Data_Ctrl20); also elsewhere on the board
/IOBANK6gh/iob6g0: U7.V11 (6G_IO_HVIO_6G_3_TXCLK3_Data_Ctrl3)
/IOBANK6gh/iob6g1: U7.R8 (6G_IO_HVIO_6G_4_TXCLK4_Data_Ctrl4)
/IOBANK6gh/iob6g2: U7.R11 (6G_IO_HVIO_6G_1_TXCLK1_Data_Ctrl1)
/IOBANK6gh/iob6g3: U7.R6 (6G_IO_HVIO_6G_7_TXCLK7_Data_Ctrl7)
/IOBANK6gh/iob6g4: U7.AE14 (6G_IO_HVIO_6G_6_TXCLK6_Data_Ctrl6)
/IOBANK6gh/iob6g5: U7.AE8 (6G_IO_HVIO_6G_12_SOURCE_SYNC_CLK2_TXCLK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); also elsewhere on the board
/IOBANK6gh/iob6g6: U7.AH14 (6G_IO_HVIO_6G_2_TXCLK2_Data_Ctrl2)
/IOBANK6gh/iob6g7: U7.V4 (6G_IO_HVIO_6G_8_TXCLK8_Data_Ctrl8)
/IOBANK6gh/iob6g8: U7.V6 (6G_IO_HVIO_6G_5_TXCLK5_Data_Ctrl5)
/clk100: U7.AE11 (6G_IO_HVIO_6G_9_PLLREFCLK1_TXCLK9_RXCLK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)

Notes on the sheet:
VCCIO_6G : 1V8

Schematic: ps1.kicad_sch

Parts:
C116, C117, C118, C119: 33p; C_0402_1005Metric
C157, C158, C159, C160, C161, C163, C164, C165, C167, C169, C170, C171, C172, C173, C196, C203, C204, C205, C216, C217: 22U 6V3; C_0402_1005Metric
C162: 100N; C_0402_1005Metric
C174, C175, C176, C177, C178, C179, C180, C181, C182, C183, C184, C185, C186, C187, C189, C190, C191, C192, C193, C194, C195, C197, C206, C207, C208, C209, C210, C214, C215, C218, C219, C220, C221: 100N; C_0201_0603Metric
L2, L3, L4, L5: L; L_0805_2012Metric
R65: 47K; R_0402_1005Metric
R80, R81, R82, R85, R86, R88, R91, R249: 10K; R_0402_1005Metric
R83: 2k2; R_0402_1005Metric
R84, R87, R90: DNP; R_0402_1005Metric; not fitted
R89: 12k; R_0402_1005Metric
U8, U16, U18, U19: AP61202Z6; SOT-563

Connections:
1V1: C119.2, C164.1, C165.1, C216.1, C217.1, C218.1, C219.1, C220.1, C221.1, L5.2, R91.2; also elsewhere on the board
1V2: C118.2, C167.1, C169.1, C196.1, C203.1, C204.1, C205.1, C206.1, C207.1, C208.1, C209.1, C210.1, C214.1, C215.1, L4.2, R88.2; also elsewhere on the board
1V8: C116.2, C159.1, C171.1, C173.1, C175.1, C177.1, C179.1, C181.1, C183.1, C185.1, C187.1, C189.1, C191.1, C193.1, C194.1, C195.1, C197.1, L3.2, R82.2, R249.1; also elsewhere on the board
3V3: C117.2, C163.1, C170.1, C172.1, C174.1, C176.1, C178.1, C180.1, C182.1, C184.1, C186.1, C190.1, C192.1, L2.2, R85.2; also elsewhere on the board
5V0: C157.1, C158.1, C160.1, C161.1, C162.1, R65.2, U8.3 (VIN), U16.3 (VIN), U18.3 (VIN), U19.3 (VIN); also elsewhere on the board
/pg_1v8: R249.2, U8.6 (PG), U16.6 (PG), U19.6 (PG); also elsewhere on the board
/power supply/PG-Core: U18.5 (EN); also elsewhere on the board
GND: C157.2, C158.2, C159.2, C160.2, C161.2, C162.2, C163.2, C164.2, C165.2, C167.2, C169.2, C170.2, C171.2, C172.2, C173.2, C174.2, C175.2, C176.2, C177.2, C178.2, C179.2, C180.2, C181.2, C182.2, C183.2, C184.2, C185.2, C186.2, C187.2, C189.2, C190.2, C191.2, C192.2, C193.2, C194.2, C195.2, C196.2, C197.2, C203.2, C204.2, C205.2, C206.2, C207.2, C208.2, C209.2, C210.2, C214.2, C215.2, C216.2, C217.2, C218.2, C219.2, C220.2, C221.2, R80.2, R81.2, R83.2, R84.2, R86.2, R87.2, R89.2, R90.2, U8.2 (GND), U16.2 (GND), U18.2 (GND), U19.2 (GND); also elsewhere on the board
unnamed: C117.1, R83.1, R84.1, R85.1, U8.1 (FB)
unnamed: L2.1, U8.4 (SW)
unnamed: R65.1, U8.5 (EN), U16.5 (EN), U18.6 (PG), U19.5 (EN)
unnamed: C119.1, R89.1, R90.1, R91.1, U16.1 (FB)
unnamed: L5.1, U16.4 (SW)
unnamed: C116.1, R80.1, R81.1, R82.1, U18.1 (FB)
unnamed: L3.1, U18.4 (SW)
unnamed: C118.1, R86.1, R87.1, R88.1, U19.1 (FB)
unnamed: L4.1, U19.4 (SW)

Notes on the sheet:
PG of 1V2 / 3V3 / 1V1 regulators (open drain) wired-AND, 1.8 V level -> U42 ch4 on root -> powergood 3.3 V + LED D1
Check powerup sequence : 0.78 -> 1.8 -> 3.3||1.1||1.2

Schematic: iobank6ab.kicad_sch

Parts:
U7: A5EB013B-B23B; VFBGA_b23b_mirror

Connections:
/Connectors/iob6a0: U7.CH14 (6A_IO_HVIO_6A_20_TXCLK20_Data_Ctrl20)
/Connectors/iob6a1: U7.CH16 (6A_IO_HVIO_6A_17_TXCLK17_Data_Ctrl17)
/Connectors/iob6a2: U7.CH19 (6A_IO_HVIO_6A_12_SOURCE_SYNC_CLK2_TXCLK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)
/Connectors/iob6a4: U7.CV19 (6A_IO_HVIO_6A_7_TXCLK7_Data_Ctrl7)
/Connectors/iob6a5: U7.CV16 (6A_IO_HVIO_6A_6_TXCLK6_Data_Ctrl6)
/Connectors/iob6a6: U7.CV14 (6A_IO_HVIO_6A_8_TXCLK8_Data_Ctrl8)
/Connectors/iob6a7: U7.CV11 (6A_IO_HVIO_6A_13_TXCLK13_Data_Ctrl13)
/Connectors/iob6a8: U7.CR19 (6A_IO_HVIO_6A_5_TXCLK5_Data_Ctrl5)
/Connectors/iob6a9: U7.CR14 (6A_IO_HVIO_6A_14_TXCLK14_Data_Ctrl14)
/Connectors/iob6a10: U7.CG23 (6A_IO_HVIO_6A_3_TXCLK3_Data_Ctrl3)
/Connectors/iob6a11: U7.CR11 (6A_IO_HVIO_6A_16_TXCLK16_Data_Ctrl16)
/Connectors/iob6a12: U7.CG26 (6A_IO_HVIO_6A_1_TXCLK1_Data_Ctrl1)
/Connectors/iob6a13: U7.CA23 (6A_IO_HVIO_6A_2_TXCLK2_Data_Ctrl2)
/Connectors/iob6a14: U7.BV19 (6A_IO_HVIO_6A_18_TXCLK18_Data_Ctrl18)
/Connectors/iob6a15: U7.CD23 (6A_IO_HVIO_6A_4_TXCLK4_Data_Ctrl4)
/Connectors/iob6a16: U7.CE14 (6A_IO_HVIO_6A_19_TXCLK19_Data_Ctrl19)
/Connectors/iob6a17: U7.BV11 (6A_IO_HVIO_6A_11_SOURCE_SYNC_CLK1_TXCLK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)
/Connectors/iob6a18: U7.BV14 (6A_IO_HVIO_6A_9_PLLREFCLK1_TXCLK9_RXCLK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)
/Connectors/iob6a19: U7.BV16 (6A_IO_HVIO_6A_15_TXCLK15_Data_Ctrl15)
/Connectors/iob6b0: U7.DD3 (6B_IO_HVIO_6B_14_TXCLK14_Data_Ctrl14); also elsewhere on the board
/Connectors/iob6b1: U7.CV6 (6B_IO_HVIO_6B_7_TXCLK7_Data_Ctrl7)
/Connectors/iob6b2: U7.CV4 (6B_IO_HVIO_6B_8_TXCLK8_Data_Ctrl8); also elsewhere on the board
/Connectors/iob6b3: U7.CR8 (6B_IO_HVIO_6B_12_SOURCE_SYNC_CLK2_TXCLK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)
/Connectors/iob6b4: U7.CR6 (6B_IO_HVIO_6B_11_SOURCE_SYNC_CLK1_TXCLK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)
/Connectors/iob6b5: U7.CH4 (6B_IO_HVIO_6B_4_TXCLK4_Data_Ctrl4); also elsewhere on the board
/Connectors/iob6b6: U7.DN2 (6B_IO_HVIO_6B_17_TXCLK17_Data_Ctrl17); also elsewhere on the board
/Connectors/iob6b7: U7.DM2 (6B_IO_HVIO_6B_9_PLLREFCLK1_TXCLK9_RXCLK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); also elsewhere on the board
/Connectors/iob6b9: U7.DH2 (6B_IO_HVIO_6B_5_TXCLK5_Data_Ctrl5); also elsewhere on the board
/Connectors/iob6b10: U7.DH1 (6B_IO_HVIO_6B_6_TXCLK6_Data_Ctrl6); also elsewhere on the board
/Connectors/iob6b12: U7.DE1 (6B_IO_HVIO_6B_3_TXCLK3_Data_Ctrl3); also elsewhere on the board
/Connectors/iob6b13: U7.DC2 (6B_IO_HVIO_6B_1_TXCLK1_Data_Ctrl1); also elsewhere on the board
/Connectors/iob6b14: U7.DC1 (6B_IO_HVIO_6B_2_TXCLK2_Data_Ctrl2); also elsewhere on the board
/Connectors/iob6b15: U7.CH6 (6B_IO_HVIO_6B_10_PLLREFCLK2_TXCLK10_RXC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)
UART_RX: U7.DJ3 (6B_IO_HVIO_6B_20_TXCLK20_Data_Ctrl20); also elsewhere on the board
UART_TX: U7.DF3 (6B_IO_HVIO_6B_16_TXCLK16_Data_Ctrl16); also elsewhere on the board
fpga_led: U7.CE6 (6B_IO_HVIO_6B_18_TXCLK18_Data_Ctrl18); also elsewhere on the board
sdm_clk25: U7.CE19 (6A_IO_HVIO_6A_10_PLLREFCLK2_TXCLK10_RXC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); also elsewhere on the board

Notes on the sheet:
VCCIO_6B : 2.5V or 3.3V

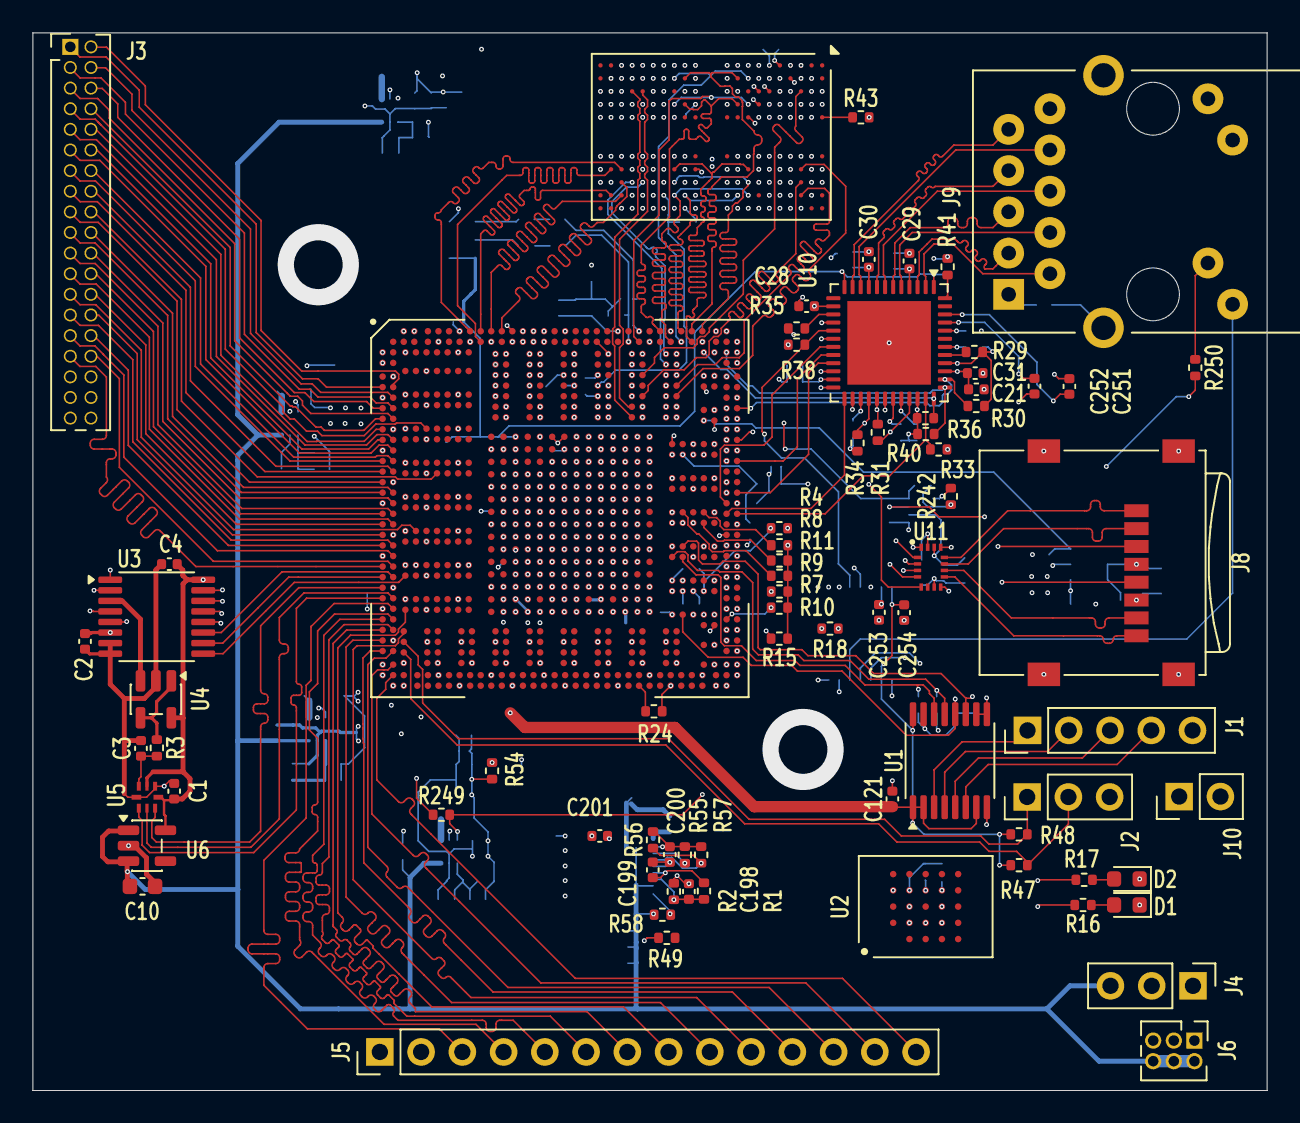
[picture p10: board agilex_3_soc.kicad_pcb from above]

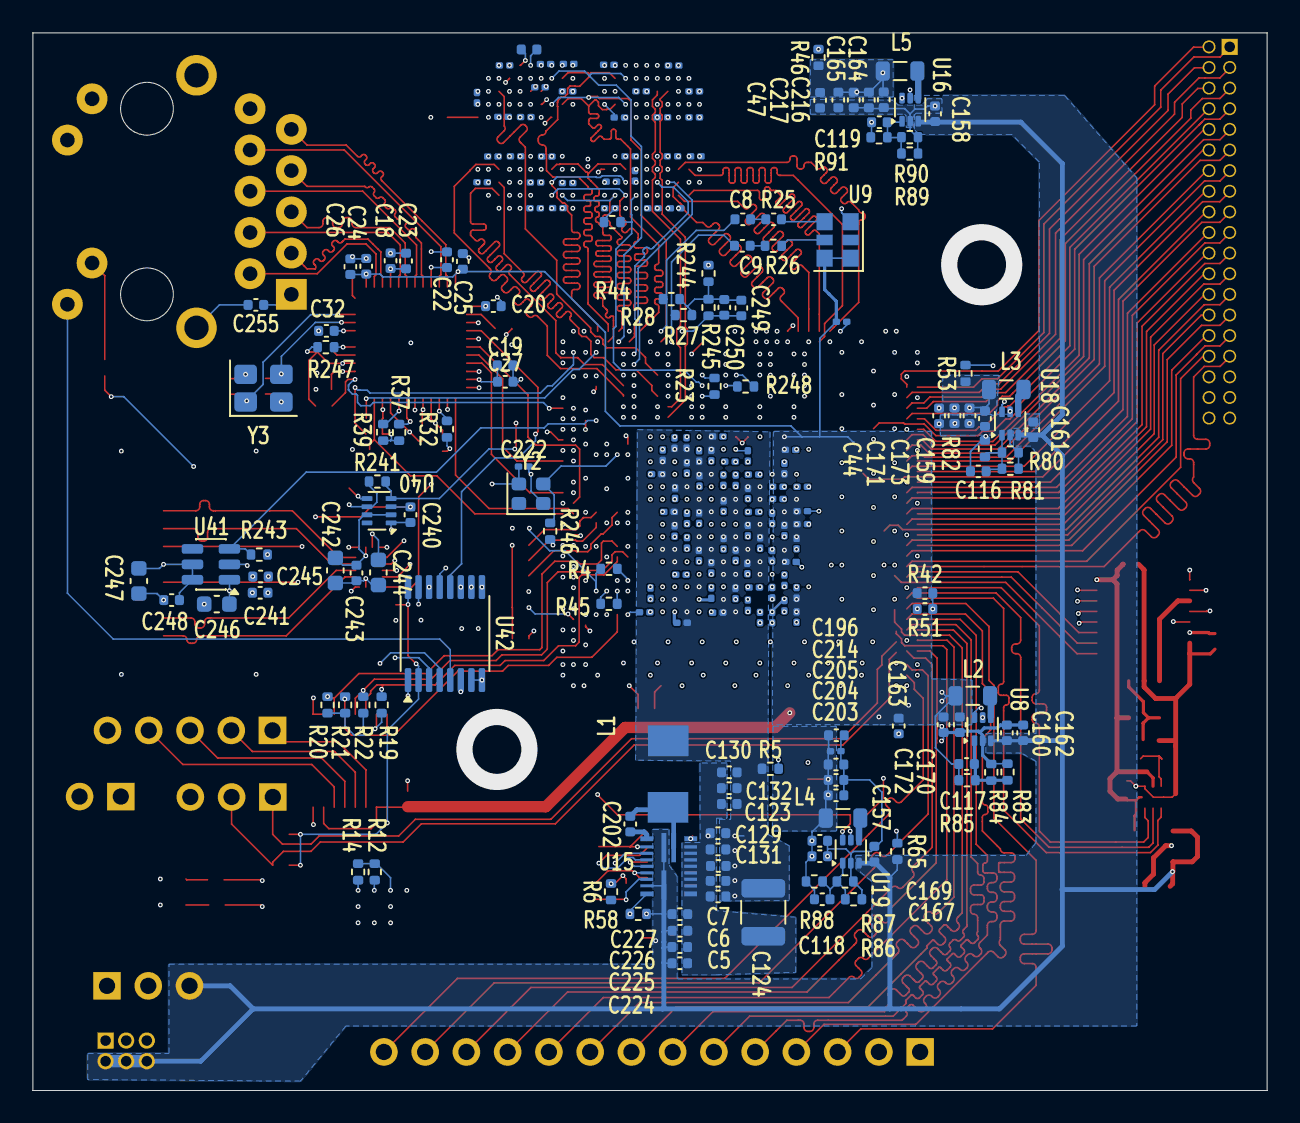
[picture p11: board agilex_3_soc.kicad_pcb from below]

Board: 8 copper layers, 76.0 x 65.1 mm, 294 parts (218 on the bottom side), 239 nets.

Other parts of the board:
C5, C6, C7, C121: C; C_0402_1005Metric
R4#2: 4K7; R_0402_1005Metric
R6: 10k; R_0402_1005Metric
R49: R; R_0402_1005Metric
R58#2: 5.6k; R_0402_1005Metric

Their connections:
3V3: C121.1; also elsewhere on the board
5V0: R49.1, R58#2.1; also elsewhere on the board
/FPGA power/vcoresense_P: R6.2; also elsewhere on the board
/SDM/msel2: R4#2.1; also elsewhere on the board
/power supply/PG-Core: R58#2.2; also elsewhere on the board
GND: C5.2, C6.2, C7.2, C121.2, R4#2.2; also elsewhere on the board
VCORE: C5.1, C6.1, C7.1; also elsewhere on the board

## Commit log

2026-01-28 sketch out more components from original design
    [agilex_3_soc.kicad_sch]
2026-03-03 add partial libraries
    [agilex_3_soc.kicad_sch]
2026-03-16 start sketching agilex 3 soc schematic and pcb
    [agilex_3_soc.kicad_sch, untitled.kicad_sch]
2026-03-17 add lpddr4 connections in schematic
    [agilex_3_soc.kicad_sch, untitled.kicad_sch]
2026-03-17 start making agilex 5 b23b package
    [agilex_3_soc.kicad_sch, untitled.kicad_sch]
2026-03-18 even more balls in b23b package
    [agilex_3_soc.kicad_sch, untitled.kicad_sch]
2026-03-19 start creating schematic symbol for agilex 5
    [agilex_3_soc.kicad_sch, untitled.kicad_sch]
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2026-03-21 add agilex 5 schematic files
    [DBM_A5E013.kicad_sch, agilex_3_soc.kicad_sch, clk.kicad_sch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]
2026-03-21 still learning how to use Git with KiCad
    [DBM_A5E013.kicad_sch, agilex_3_soc.kicad_sch, clk.kicad_sch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]
2026-03-21 sketch io routing between connector and agilex
    [agilex_3_soc.kicad_sch]
2026-03-21 move adc and admux to own schematic
    [ad_subsystem.kicad_sch, agilex_3_soc.kicad_sch, untitled.kicad_sch]
2026-03-22 try to figure out how to do buses
    [ad_subsystem.kicad_sch, agilex_3_soc.kicad_sch]
2026-03-22 start adding power supplies
    [ad_subsystem.kicad_sch, agilex_3_soc.kicad_sch]
2026-03-23 add ads7056 footprint
    [ad_subsystem.kicad_sch, agilex_3_soc.kicad_sch]
2026-03-24 start routing sd card
    [ad_subsystem.kicad_sch, agilex_3_soc.kicad_sch]
2026-03-24 more routes
    [ad_subsystem.kicad_sch, agilex_3_soc.kicad_sch]
2026-03-25 even more power supply routing
    [ad_subsystem.kicad_sch, agilex_3_soc.kicad_sch]
2026-03-25 add correct inductor footprints for peripheral supplies
    [ad_subsystem.kicad_sch]
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2026-03-26 add vias to lppdr balls
    [ad_subsystem.kicad_sch, agilex_3_soc.kicad_sch, clk.kicad_sch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]
2026-03-29 move to 8 layers
    [iobank3.kicad_sch]
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2026-04-04 draw a few connections
    [agilex_3_soc.kicad_sch]
2026-04-05 start route io connectors
    [ad_subsystem.kicad_sch, agilex_3_soc.kicad_sch]
2026-04-07 add more io routes
    [agilex_3_soc.kicad_sch]
2026-04-07 even more io
    [agilex_3_soc.kicad_sch]
2026-04-07 more cleanup
    [agilex_3_soc.kicad_sch]
2026-04-08 add comments
    [eth.kicad_sch, hps.kicad_sch, ps.kicad_sch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]
2026-04-09 start routing power supplies
    [ad_subsystem.kicad_sch, agilex_3_soc.kicad_sch, ps.kicad_sch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]
2026-04-09 add capacitors and resistors to core power
    [ps.kicad_sch]
2026-04-13 sketch length matching for lpddr4
    [ps.kicad_sch, ps1.kicad_sch]
2026-04-15 fine tune more lpddr routes
    [agilex_3_soc.kicad_sch]
2026-04-15 add level translator for jtag
    [agilex_3_soc.kicad_sch]
2026-04-16 add another powersupply for lpddr4
    [ps1.kicad_sch, sdm.kicad_sch]
2026-04-18 add routes for power supplies
    [agilex_3_soc.kicad_sch, clk.kicad_sch, fpga_power.kicad_sch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]
2026-04-19 savegame, after fixing wird problems with schematic sync
    [agilex_3_soc.kicad_sch, fpga_power.kicad_sch, mem1.kicad_sch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]
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2026-04-19 add qspi
    [clk.kicad_sch, sdm.kicad_sch]
2026-04-19 minor fiddling
    [agilex_3_soc.kicad_sch]
2026-04-21 savegame before trying to fix component names
    [agilex_3_soc.kicad_sch, clk.kicad_sch]
2026-04-24 more fiddling with aux power supplies
    [ps1.kicad_sch]
2026-04-26 route ethernet rgmii io
    [agilex_3_soc.kicad_sch, eth.kicad_sch]
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2026-04-27 change bypass caps to 0201 and start adding them to board
    [ps.kicad_sch]
2026-04-28 remove hyperram and add lpddr4 bypass caps
    [agilex_3_soc.kicad_sch, eth.kicad_sch, iobank6gh.kicad_sch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]
2026-04-28 place even more bypass caps
    [fpga_power.kicad_sch, ps1.kicad_sch]
2026-04-29 route more rgmii io
    [fpga_power.kicad_sch, ps.kicad_sch, ps1.kicad_sch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]
2026-05-03 add separate clock ICs instead of using programmable ic
    [agilex_3_soc.kicad_sch, clk.kicad_sch]
2026-05-03 add oscillator footprint and start adding ac biasing for lpddr clock
    [clk.kicad_sch, ps.kicad_sch]
2026-05-04 add ac biasing to lpddr ref clock
    [agilex_3_soc.kicad_sch, clk.kicad_sch]
2026-05-05 move power 1v1 power supply
    [agilex_3_soc.kicad_sch, ps1.kicad_sch]
2026-05-06 fix some dangling routes
    [agilex_3_soc.kicad_sch]
2026-05-07 add 1v2 flood
    [agilex_3_soc.kicad_sch, ps.kicad_sch]
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2026-05-09 add pcb boundary and remove original pcb
    [agilex_3_soc.kicad_sch, ps1.kicad_sch]
2026-05-10 remove extra components and make 1v8 plane
    [eth.kicad_sch, fpga_power.kicad_sch, hps.kicad_sch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]
2026-05-12 add sdcard level shifter
    [hps.kicad_sch, ps1.kicad_sch]
2026-05-20 increase 3v3 flood to cover nearly all 3v3 io
    [agilex_3_soc.kicad_pcb]
2026-05-20 fix some drc issues
    [agilex_3_soc.kicad_pcb]
2026-05-29 add resistors for ad channels
    [agilex_3_soc.kicad_pcb, agilex_3_soc.kicad_sch, hps.kicad_sch]
2026-05-31 move heat sink pins to match 960-23-33-D-AB-0 heat sink
    [agilex_3_soc.kicad_pcb]
2026-09-06 change flash to correct part
    [agilex_3_soc.kicad_pcb, connectors.kicad_sch, sdm.kicad_sch]
2026-09-07 choose clock ic:s
    [agilex_3_soc.kicad_pcb, clk.kicad_sch, hps.kicad_sch]
2026-09-08 fix footprints
    [clk.kicad_sch]
2026-09-08 fix oscillator supplies and flash pinout, swap SD translator to NXS0506GU
    Y2/U9: VDD and GND were reversed - an earlier symbol edit assumed the wrong
    schematic pin transform (KiCad subtracts the local Y, it does not add it).
    Supplies now land correctly: Y2 VDD->1V8, U9 VDD->3V3, both GND->GND.
    U9's enable tie moved from the NC pin to OE.
    U2 boot flash: QSPI signals were permuted and VCC/GND were unconnected, from
    the same transform error. Re-paired the net labels and moved the 1V8 and GND
    symbols onto the VCC/GND pins. All 9 connections verified:
    SCLK->qspi_CLK, CS#->~qspi_CS, SIO0-3->qspi_D0-D3, RESET#->~qspi_rst_n.
    U11: TXS0206A (DSBGA-20, 0.4mm BGA) -> NXS0506GUX (XQFN16). The new symbo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
    [agilex_3_soc.kicad_pcb, clk.kicad_sch, hps.kicad_sch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]
2026-09-09 add sdcard interface documentation
    Documents the microSD interface as built: the verified HPS -> U11 -> J8
    signal path, supply assignments, and the fact that the NXS0506GU's internal
    pull-ups make external ones unnecessary.
    Records the open items found while swapping U11: no decoupling on either of
    U11's supplies, no capacitance at the card connector, no hardware card
    detect, and SD traces still to be rerouted for the smaller footprint.
    Also specifies what UHS-I would need, since the card-side rail is currently
    tied to a fixed 3.3 V and caps the interface at high speed (~50 MHz):
    splitting VCCB onto a switched VDD_SD_IO rail muxed from the existing 3V3
    and 1V8, a load switch on card VDD fo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
2026-09-09 sdcard doc: add mux and load switch part selection
    TPS2116DRLR (SOT-583) as the 2:1 mux between 3V3 and 1V8 for the switched
    VDD_SD_IO rail, and TPS22918 (SOT-23-6) as the load switch on card VDD.
    Both packages have verified footprints in KiCad's Package_TO_SOT_SMD
    library, so no hand-built footprints are needed.
    The TPS2116 covers the two constraints that made this circuit awkward:
    reverse current blocking stops the body-diode back-feed into 1V8 when the
    rail sits at 3.3 V, and break-before-make is internal so the rails cannot be
    shorted. Its PR1 select switches around VREF (0.92-1.08 V), leaving margin
    for a 1.8 V GPIO. The TPS22918's quick output discharge matters for the
    power-cycle rec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
2026-09-14 update project
    [agilex_3_soc.kicad_pcb, agilex_3_soc.kicad_sch, clk.kicad_sch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]
2026-09-14 fix clock routing and move all components inside board perimeters
    [ad_subsystem.kicad_sch, agilex_3_soc.kicad_pcb, agilex_3_soc.kicad_sch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]
2026-09-16 fix drc
    [a5ee008b.xlsx, agilex_3_soc.kicad_pcb, ps1.kicad_sch]
2026-09-16 add hps uart
    [agilex_3_soc.kicad_pcb, agilex_3_soc.kicad_sch, hps.kicad_sch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]
2026-09-16 fix missing routes
    [agilex_3_soc.kicad_pcb, clk.kicad_sch]
2026-09-16 fix ethernet jack
    [agilex_3_soc.kicad_pcb, agilex_3_soc.kicad_sch, eth.kicad_sch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]
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2026-09-17 route pg all signal to led
    [agilex_3_soc.kicad_pcb]
2026-09-19 start finishing the pcb
    [agilex_3_soc.kicad_pcb, agilex_3_soc.kicad_sch, eth.kicad_sch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]
2026-09-19 fix silkscreen placement
    [agilex_3_soc.kicad_pcb]
2026-09-19 fix silkscreen placement further
    [agilex_3_soc.kicad_pcb]
2026-10-06 LPDDR4: top-layer dqs2 route, data-lane delay tuning, command T topology, DRC rules
    - dqs2 pair completed on F.Cu through the U7 ball field (single-channel escape)
    - all DQ/DM/DQS matched to 202 ps (strobe pair skew <= 0.1 ps); command group
    reworked to balanced T's at both U12 balls, delay tuning still pending
    - custom DRC rules: per-layer 50/100 ohm geometry, BGA neck-down, 12 mm
    uncoupled allowance, 2 ps pair skew, crosstalk warning
    Claude-Session: https://claude.ai/code/session_01DTvSTbyDRanUUYSTEfFpVv
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2026-10-13 Fix library tables: project-local paths only
    - Extract the FPGA_Altera_Agilex_5E (A5EB013B-B23B) symbol from the
    schematic cache into agilex_5_lib/ and point sym-lib-table at it
    - Drop the C:/ library paths (unused leftovers from the Altera
    reference design) and the missing titanium_lib entries from both
    sym-lib-table and fp-lib-table
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2026-10-13 Set design constraints to JLCPCB multilayer capabilities
    Board setup:
    - clearance / track width 0.09 (was 0 / 0)
    - via 0.25 dia / 0.15 drill min, annular 0.05 (was 0.1: flagged all
    0.3/0.15 vias, which have JLCPCB's preferred 0.075 ring)
    - through-hole drill min 0.15 (0.1 only for boards <= 1 mm)
    - via hole-to-hole 0.2, hole clearance 0.175 (see .kicad_dru note)
    - silkscreen text 1.0 mm / 0.15 mm, silk clearance 0.15
    - netclass Default/lpddr_dq via drill 0.1 -> 0.15
    Custom rules: PTH annular ring 0.15, PTH pad hole-to-hole 0.45,
    PTH-to-track 0.28. Stackup: vias filled and capped (via-in-pad on U7).
    Also keeps the DRC exclusions and zone defaults saved from the GUI.
    DRC (zones refilled) 3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
2026-10-13 U7: use Altera_B23B footprint from Rolf-Altera's generator
    Generated with the KiCad footprint generator from Rolf-Altera's
    kicad-library-tools branch Altera_Agilex_5 (4024449, MR
    kicad/libraries/kicad-library-tools!2200), which uses Altera's
    B23B ball coordinate / land pattern file (PBC-LPG):
    py generate.py -g package/grid_array -p Altera_B23B
    - Pads per Altera land pattern: 0.305 mm (769), 0.33 mm (17),
    0.355 mm (9), NSMD with mask = pad + 0.1 mm. Old footprint had
    0.4 mm pads with 0.075 mm clearance overrides and a duplicated
    CL23 pad.
    - Placed at rotation 0 on the package centre (156.4668, 112.1692);
    every ball lands exactly on its old position (max deviation
    0.0000 mm), so r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
2026-10-13 Remove unused VFBGA_b23b footprints
    Replaced by Altera_B23B for U7; nothing references them anymore.
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2026-10-13 Remove unused symbols from agilex_5_lib
    - agilex_5_lib: drop A5EB013B-B23B (U7 uses the FPGA_Altera_Agilex_5E
    copy), the early Agilex3_SoC / Agilex_5_SoC drafts, TXS0206A (SD
    translator replaced by NXS0506GU) and XLL7 (clock replaced by SiTime)
    - Delete a5eb013b-b23b.kicad_sym: not in sym-lib-table, older copy of
    the U7 symbol
    ERC unchanged, no library issues.
